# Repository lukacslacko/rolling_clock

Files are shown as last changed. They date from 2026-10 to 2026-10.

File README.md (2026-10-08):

# Rolling clock

A 3D-printed clock mechanism powered by its own slow roll down an incline. The rolling drum drives a pendulum escapement through two 72:18 gear pairs. A weighted inner frame carries the gears and stays approximately upright while the drum turns around it.

Designed by László Lukács with OpenAI Codex for a Bambu Lab P1S, using PLA, a 0.4 mm nozzle and 0.2 mm layers. Intended as a short-duration timer and mechanical demonstration.

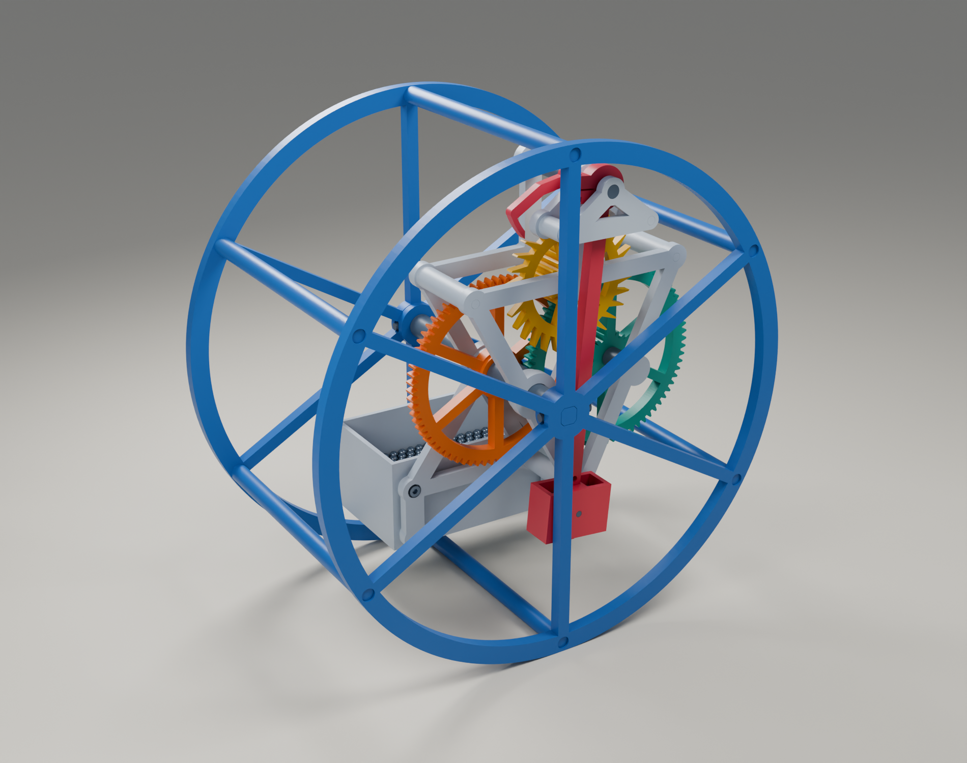
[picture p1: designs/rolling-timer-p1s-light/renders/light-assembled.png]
Assembled lightweight rolling clock


## New prototype - bolted R3

The [R3 design](designs/rolling-timer-r3/README.md) responds to the first build's physical feedback: square screw-fastened posts, a screw-fixed bob, more pendulum space, a deeper rolling rim and shared frames for 16:1, 32:1 and 64:1 gearing. It includes [a 17-page illustrated guide](designs/rolling-timer-r3/BUILD-GUIDE.pdf), a [1:1 axle identification sheet](designs/rolling-timer-r3/AXLE-1-TO-1.pdf) (also guide page 6), [per-ratio spacer and wheel-orientation drawings](designs/rolling-timer-r3/PIVOT-STACKS.pdf) (guide pages 7-9), and separate print lists. **The builder reports corrected R3 prints and rolls well.** The smoother wheel below still needs a physical trial. The first working version remains below and under tag `v0.1.0`. The 7 October pivot correction adds taller pivot feet and 6 mm of width; see the R3 reuse table before printing the remaining parts.

**R3 rear thrust correction:** add one [38_rear_journal_thrust_collar.stl](designs/rolling-timer-r3/STL/common/38_rear_journal_thrust_collar.stl). This 6 mm ring surrounds rear journal 36, between the rear frame and washer 35; it fills a gap omitted during the widening. All existing corrected print files remain unchanged. See the [R3 correction notes](designs/rolling-timer-r3/README.md#missing-rear-thrust-collar---correction) and updated guide page 6.

**Smoother R3 rim:** [wheel 01](designs/rolling-timer-r3/STL/common/01_case_wheel.stl) now has **1,536 outer segments** instead of 192 (0.507 mm flats instead of 4.058 mm). The 248 mm diameter and all mounting features are retained; the other 50 print files are unchanged. Try Bambu Studio Resolution 0.001 mm and Arc fitting on. Details and evidence are in the [R3 notes](designs/rolling-timer-r3/README.md#smoother-rolling-rim---8-october-2026).

## Current state — first working build

On **1 October 2026**, the complete lightweight **16:1** mechanism ran on its first physical trial, following a successful hand-driven bench test. This repository preserves that design before the next round of improvements. Running duration, timing accuracy and long-term wear have not yet been measured.

The reported issue is occasional contact between the pendulum bob and the interior frame or drum spokes. A separate [1 mm wall replacement bob and shorter pin](designs/rolling-timer-p1s-light/bob-1mm/README.md) provide 1.4 mm more clearance on each side while preserving the iron capacity and rod fit. This replacement has passed geometric checks but **has not yet been physically tested**. The original working STL set is retained unchanged.

## Start here

1. Use the **[lightweight 16:1 design](designs/rolling-timer-p1s-light/README.md)** and its **[print list](designs/rolling-timer-p1s-light/PRINT-LIST.md)**. The list gives quantities and orientations; optional fit coupons are included.
2. Follow the **[illustrated bench assembly guide (PDF)](designs/rolling-timer-p1s-light/bench-guide/bench-assembly-guide.pdf)** for the gear train, escapement and pendulum. A [browser version](designs/rolling-timer-p1s-light/bench-guide/index.html) is included; download the repository and open it locally.
3. Follow the **[complete assembly instructions](designs/rolling-timer-p1s-light/ASSEMBLY.md)** to add the ballast cup and rolling drum.
4. For the clearance update, replace parts 25 and 26 with **[25_open_pendulum_bob_1mm.stl](designs/rolling-timer-p1s-light/bob-1mm/25_open_pendulum_bob_1mm.stl)** and **[26_bob_pin_short.stl](designs/rolling-timer-p1s-light/bob-1mm/26_bob_pin_short.stl)**. Follow that folder's fitting instructions; the guide's pictures show the original bob.

**Rotation direction:** viewed from the pendulum/front side, the orange input and yellow escape wheel turn counterclockwise, and the green compound wheel turns clockwise. Apply only light hand torque for a bench test. Lift the drum to return it uphill instead of rolling the escapement backward.

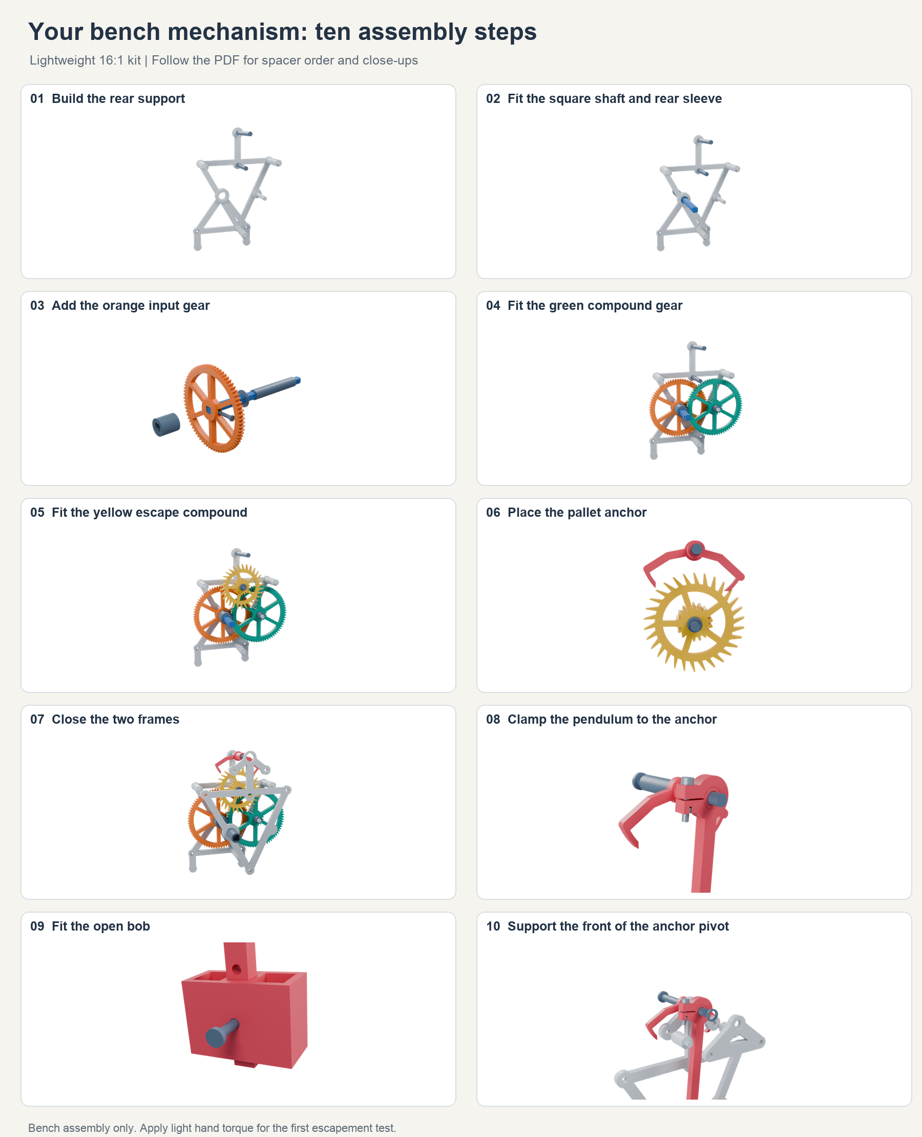
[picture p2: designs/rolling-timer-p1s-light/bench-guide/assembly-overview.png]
Ten stages of the bench assembly


## Dimensions and materials

| Item | Design |
|---|---|
| Rolling drum | 240 mm diameter × 140 mm wide |
| Printer envelope | 256 × 256 × 256 mm; every individual part fits |
| Spur gears | Module 1.25, 20° pressure angle; 72:18 × 72:18 = 16:1 |
| Escapement | 30-tooth Graham deadbeat, printed pallets and short pendulum |
| Main axle | 8 mm chamfered square shaft with separate round journal sleeves |
| Bearings | Printed plain journals; no purchased rolling bearings |
| Ballast | Start around 600 g in the open main cup and 15–20 g in the open bob |
| Hardware | Two M3 × 10 screws and nuts for the cup; one M3 × 16 screw and nut for the pendulum clamp |
| Nominal rate | About 8 minutes per metre at the intended effective pendulum length; calculated, not measured |

The two compound gears have small-pinion teeth extending through their large wheels so they print from the bed without support under the pinions. Detailed fits, print settings and first-run setup are in each design's README. STL dimensions are millimetres; print at 100% scale.

## Animation and other variants

Open **[docs/animation.html](docs/animation.html)** locally for the interactive animation: play/pause, single beats, time scrubbing, and close-ups of the escapement and gear layers. It is a self-contained HTML file with no build step or network dependency. Its older grid-frame schematic illustrates the same 16:1 gearing; the print files and assembly guide define the lightweight hardware. The animation prescribes motion and does not simulate friction, available torque or carrier rocking.

The **[modular R2 design](designs/rolling-timer-p1s-r2/README.md)** retains two grid plates with removable pivot modules for experimenting with gear ratios. Its **[32:1 development set](designs/rolling-timer-p1s-r2/upgrade-32x/README.md)** includes an extra gear and a matched reversed escape wheel and anchor. Neither this grid-frame assembly nor the 32:1 set has been physically tested. The 32:1 set is **not a drop-in upgrade for the lightweight frames**.

Perspective renders, editable Blender mesh scenes, assembled reference meshes and JSON geometry-check reports are included beside each design. Files in `source/assembly/` and `bob-1mm/assembly/` are positioned reference meshes, not print plates. Rendered loose steel and fasteners are illustrative.

## Edit and regenerate

The CAD source is Python using Manifold, Trimesh, Shapely and NumPy. Use **Python 3.11 or newer** and install the pinned dependencies in a virtual environment. From the repository root:

```sh
python3 -m venv .venv
source .venv/bin/activate
python -m pip install -r designs/rolling-timer-p1s-light/source/requirements.txt

python designs/rolling-timer-p1s-light/source/check_motion.py
python designs/rolling-timer-p1s-light/source/validate_light.py
python designs/rolling-timer-p1s-light/bob-1mm/source/build_bob.py
```

On Windows, activate with `.venv\Scripts\activate` instead. `check_motion.py` regenerates the base print files and assembled geometry before checking motion. The bob generator writes only the separate replacement folder. These commands overwrite generated files; commit edits before regenerating. The STL set has already been exported, so Python is unnecessary just to print it.

The modular version has its own generators:

```sh
python designs/rolling-timer-p1s-r2/source/check_motion.py
python designs/rolling-timer-p1s-r2/source/upgrade32.py
python designs/rolling-timer-p1s-r2/source/validate_revision.py
```

For optional renders, use Blender 5.x:

```sh
blender -b --factory-startup -t 6 --python designs/rolling-timer-p1s-light/source/render_light.py
blender -b --factory-startup -t 6 --python designs/rolling-timer-p1s-light/bench-guide/source/render_bench_guide.py
```

To rebuild the PDF and browser guide from the included rendered figures, install `reportlab` and `Pillow`, then run `python designs/rolling-timer-p1s-light/bench-guide/source/make_bench_guide.py`. The script looks for Arial, Liberation Sans or DejaVu Sans on common platforms; the checked-in PDF is ready to use.

The checks cover closed connected meshes, print envelopes, gear engagement, nominal assembly intersections, and sampled mechanism motion. They do not model print error, friction, strength or wear. Historical JSON reports describe the geometric checks when created; the physical status above records the later successful trial.

## References and license

The deadbeat pallet geometry follows the construction described by [Roman Y. Andronov](https://romanandronov.github.io/pgc/ryapgce.html); see also [Rainer Hessmer's Deadbeat Escapement Builder](https://hessmer.org/gears/DeadbeatEscapementBuilder.html). The project supplies its own CAD implementation, mounting system and print geometry.

The original source, print models, animation and documentation in this repository are released under the **[MIT License](LICENSE)**. Third-party software used to generate them retains its own licenses and is not bundled here.

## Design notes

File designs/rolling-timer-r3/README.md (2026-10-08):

# R3 - bolted frames and three gear ratios

The builder reports that the corrected R3 **prints and rolls well** (8 October 2026), after adding rear thrust collar 38. Visible flat faces on the rolling rim led to the finer-mesh wheel below, which still needs a physical print. Running accuracy, durability and every gearing option have not been established. The original build and its `v0.1.0` checkpoint remain unchanged.

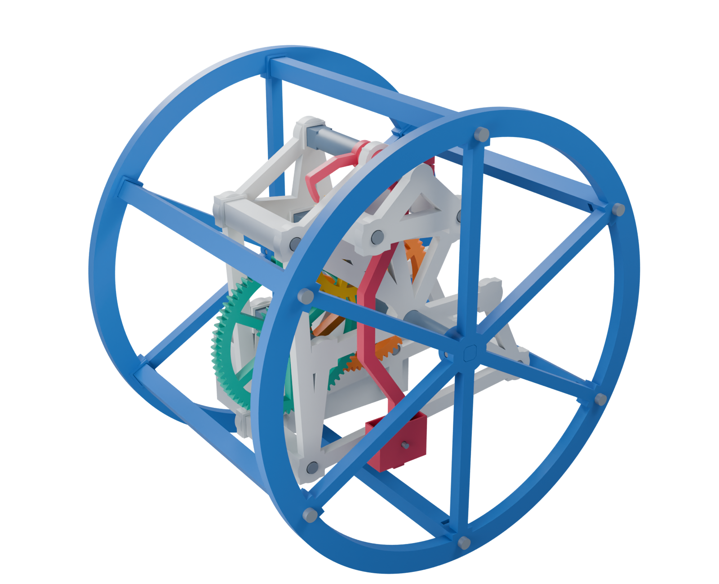
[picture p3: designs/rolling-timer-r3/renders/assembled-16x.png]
Bolted R3 assembly


## What changes

- Six square case posts and three square frame posts have flat ends, side-loading captive nuts and M3 clearance holes. Screws clamp the ends against flat seats; locating lips have **0.2 mm clearance per side**, so the posts do not spread the wheel rim.
- The bridge has two square posts, bolted at both ends. Its post locations are moved away from the pendulum clamp's swept envelope. The bridge supplies their square locating lips; their frame ends sit directly on a flat face.
- All three main-axle crosspins become **M3x16 screws and captive nuts**. The square axle still transmits torque; the screws retain it axially.
- The open bob has **1 mm outer walls**, a retained structural web, and an **M3x16 screw and captive nut** instead of a printed pin. Its screw passes through one of five 3.4 mm rod holes.
- The pendulum has its own wider front compartment and a bent rod that clears the main axle. The escapement is tilted inward by 10 degrees as a matched wheel/pallet arrangement to keep the pendulum clamp inside the rotating posts. Its working pallet profiles follow the first successful build.
- Both carrier frames support **16:1, 32:1 and 64:1**. Gear shafts are bolted to the rear frame and supported in clearance-fit blind seats in the front frame. The anchor pivot is supported by the rear frame and the bolted bridge. No bought bearings are needed.

The drum is **248 mm diameter x 186 mm between its outer plastic faces**, about **192.4 mm including the bounded screw heads**. Every individual part fits the 256 mm P1S volume. The wheel has a 13 mm radial rolling rim. The post body's furthest corner is 4.90 mm inside the rolling circle; the wider locating pads stay at least about 2.9 mm inside it. All post screws load the wheel axially.

## Smoother rolling rim - 8 October 2026

The printed rim's visible faces were present in the STL: the outside circle used **192 segments**, making each flat **4.058 mm wide** on the 248 mm wheel. The ideal chord lies up to **0.01660 mm** inside a true circle. This coarse approximation is a clear contributor to the reported faceted surface; the user's actual sliced toolpath was not inspected.

The current [01_case_wheel.stl](STL/common/01_case_wheel.stl) uses **1,536 outer segments**, each about **0.507 mm wide**, with only **0.000259 mm ideal chord error**. Only the outside rolling contour changes. The hub, axle socket, six post seats, screw holes, inner rim and spokes keep their original geometry. The other 50 print files are unchanged. Print **two copies** when replacing the drum wheels; the revised wheel still fits the existing assembly.

For this wheel, try **Bambu Studio Resolution = 0.001 mm** and **Arc fitting enabled** in Advanced settings. Resolution controls contour simplification, and arc fitting uses the same tolerance to generate G2/G3 moves; this is an engineering starting point for this rim, not a physically tested profile. The common Bambu process profile currently uses 0.012 mm resolution. See Bambu's [setting definitions](https://github.com/bambulab/BambuStudio/blob/master/src/libslic3r/PrintConfig.cpp) and [common process profile](https://github.com/bambulab/BambuStudio/blob/master/resources/profiles/BBL/process/fdm_process_common.json). Keep 0.2 mm layers: the issue is the circular contour in the XY plane. Avoid mesh simplification of the replacement STL.

## Pivot-base correction - 7 October 2026

The original 4.5 mm pivot foot was too short: its nut channel reached 1.2 mm into the 8 mm journal, leaving a weak connection. Both pivot types now have **10.5 mm square feet**, **4.8 mm of material above the nut channel**, and a blind screw bore that stops **3.7 mm below the shaft root**. The 8 mm shaft is solid from its root upward. Print pivots 13 and 19 with **100% infill**, foot down. Nut fit remains 5.6 mm with a 5.8 mm entry.

The gear train, front frame, bridge and pendulum move forward together by 6 mm. Gear engagement, all gear spacers, pendulum clearance and screw lengths stay the same. At its closest axial position, the B gear is 6.4 mm ahead of its pivot nut.

**Already printed R3 gears, anchor, rear frame, anchor bridge and both bridge posts can be reused. Reprint only the three frame posts from the builder's reported printed set.** Both frame shapes are unchanged; their spacing increases from 48 to 54 mm. Six print files change in total:

| File in `STL/common/` | Qty, 32x core | Qty, complete 32x | Revised dimension |
|---|---:|---:|---|
| [07_square_frame_post.stl](STL/common/07_square_frame_post.stl) | 3 | 3 | 54 mm long |
| [13_bolted_gear_pivot.stl](STL/common/13_bolted_gear_pivot.stl) | 3 | 3 | 10.5 mm foot; 56.5 mm total |
| [19_bolted_anchor_pivot.stl](STL/common/19_bolted_anchor_pivot.stl) | 1 | 1 | 10.5 mm foot; 89.5 mm total |
| [03_square_main_axle.stl](STL/common/03_square_main_axle.stl) | 1 | 1 | 186 mm; cross-holes at 6, 97, 180 mm |
| [36_rear_round_journal.stl](STL/common/36_rear_round_journal.stl) | 1 | 1 | 76 mm long |
| [02_square_case_post.stl](STL/common/02_square_case_post.stl) | 0 | 6 | 172 mm long |

For 16x, use two copies of pivot 13; the other quantities are the same. The 64x quantities match 32x. Use all six corrected file types when completing the drum; all other R3 print shapes remain compatible.

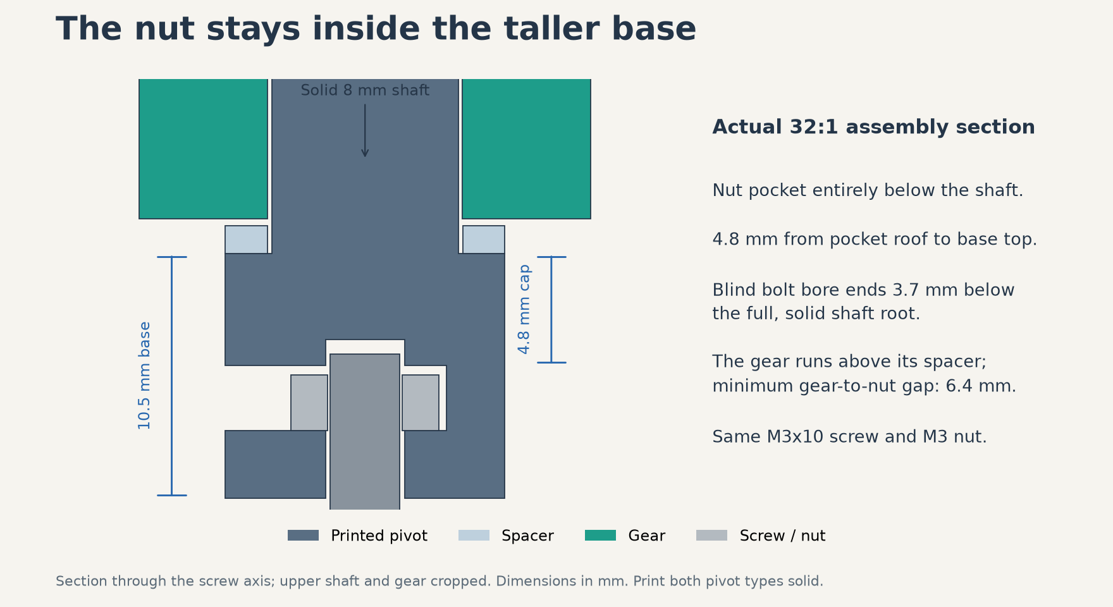
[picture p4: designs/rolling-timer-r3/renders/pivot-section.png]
Section through corrected gear pivot


## Missing rear thrust collar - correction

The 6 mm widening advanced the orange gear, washer 35 and the end of journal 36, but left the rear frame's bearing collar in place. A ring around the journal was omitted. This left a **6.4 mm gap between the rear-frame collar and washer 35**, allowing excessive rearward movement of the main axle relative to the carrier. This was a design error, not a missing assembly step or a part already present in the earlier kit.

**Print one [38_rear_journal_thrust_collar.stl](STL/common/38_rear_journal_thrust_collar.stl), for any of the three ratios.** It is **6 mm long, 16 mm outside diameter, with a 12.4 mm round bore**. Print flat on either annular face, without supports. Slide it **around journal 36**, in front of the rear-frame bearing collar and behind washer 35. Washer 35 still goes onto the square axle, against the end of the journal. The nominal frame-to-collar clearance is 0.4 mm.

Rear-to-front thrust path: **rear-frame collar 05 → new collar 38 → washer 35 → fixed orange gear 10**. Journal 36 runs inside collar 38. **The collar correction left all 50 previously supplied STL files byte-for-byte unchanged.** The later rolling-rim refinement above changes only wheel 01. The collar is included in all print lists, kits, the assembly meshes and the updated guide's page 6. No additional screw or nut is needed.

The geometry checks now derive the actual axle stops from the thrust stacks and allow the loose sleeves to slide independently. With collar 38, the nominal rigid axle limits are **-0.8 to +0.8 mm** relative to the carrier; the previous check incorrectly assumed only -0.4 to +0.4 mm without checking that those stops existed. All three configurations pass the revised interference checks. The builder subsequently reported that collar 38 printed well and the clock rolled well.

## Files and printing

Start with [BUILD-GUIDE.pdf](BUILD-GUIDE.pdf), then use the exact quantities in [PRINT-LIST-16x.md](PRINT-LIST-16x.md). The other configurations have [32x](PRINT-LIST-32x.md) and [64x](PRINT-LIST-64x.md) lists. Do not print every file in every folder.

**Axle orientation, updated 8 October:** page 6 of the 17-page guide is a **1:1 side view of the assembled main axle**, with a second outline of the bare axle and all three holes. It is also available as a one-page [AXLE-1-TO-1.pdf](AXLE-1-TO-1.pdf). Print A4 landscape at **100% / Actual size**, disable Fit / Shrink, and verify the **50 mm calibration bar**. The drawing uses the actual corrected assembly meshes and is shared by all three ratios.

**Spacer and wheel orientation drawings:** guide pages **7, 8 and 9** cover **16:1, 32:1 and 64:1**, respectively. The same three pages are available separately as [PIVOT-STACKS.pdf](PIVOT-STACKS.pdf). Each shows the active pivot map, rear-to-front order, part numbers, spacer lengths, tooth counts and the direction of the pinions. The anchor row shows its sleeve passing through the front frame, the pendulum clamp, and the 7.7 mm front spacer before the bridge. These side diagrams use CAD axial positions with compressed diameters for readability; they are **not 1:1 templates**.

The middle hole is **97 mm from the rear end** (main ballast bowl side), and **89 mm from the front end** (pendulum side). The orange wheel's **flat face points rearward**, toward the **76 mm journal 36**; its **raised hub points forward**, toward sleeve 34 and the pendulum. Its M3x16 screw goes through the middle hole. Rear-to-front order on the axle: **36 → 35 → 10 → 34 → 37**, with **38 around the front end of 36**, between the rear frame and washer 35. The drawing preserves the intended small gaps; it is not an exploded view.

- `STL/common/`: shared case, frames, fastener posts, pivots, input gear, pendulum and bob.
- `STL/16x/`, `STL/32x/`, `STL/64x/`: the selected gear train and its spacers.
- `STL/slow-common/`: the reversed anchor shared by 32x and 64x.
- `STL/fit-tests/`: nut-post and locating-seat coupons.
- `assembly/`: positioned reference meshes, **not print files**.
- `source/`: editable Python CAD, geometric checks, render and guide generators.
- `layouts.json`: actual R3 shaft positions and per-ratio quantities. `escapement-reference.json` preserves the earlier tooth/pallet/contact-cycle data; its legacy layout centres are not the R3 frame layout.
- `renders/` and `r3-assembly.blend`: views of the actual mesh assemblies.

Use PLA, a 0.4 mm nozzle, 0.2 mm layers, and 100% scale. Small functional parts: 5-6 walls and solid or nearly solid sections. Larger frames and wheels: about 4-5 walls, 5 top/bottom layers and 25-35% infill as a starting point. The exported orientations put posts on a long flat side with their nut slots upward, gears on their broad faces, cups mouth-up, and journal sleeves upright. Keep gear teeth, journals and pallets free of support material. Preview the small transverse screw-hole bridges and nut recesses in the slicer.

The 248 mm wheel leaves only 4 mm on each side of a nominal 256 mm bed: **no outside brim**. Check your actual printer profile's exclusions and auxiliary structures. Tall journal sleeves and pivots can use a small brim.

### Fit coupons first

The final anti-rotation seats are **5.6 mm** wide throughout, selected by the builder after printing and trying the fit coupons. The side-loading insertion channels are **5.8 mm** wide, with a 2 mm taper into the seat, including the bob, square posts, pivot feet and axle-retaining hubs. Direct-entry hex pockets in the pendulum clamp and ballast bowl use the same 5.6 mm seats with a short 5.8 mm flared mouth. `NUT_WIDTH` and `NUT_ENTRY_WIDTH` in `source/build.py` control these dimensions independently.

To confirm the fit on another printer or with different nuts, print `40_nut_post_coupon_560.stl` and `41_post_seat_coupon.stl` in their supplied orientations, and try an actual nut and M3x10 screw. The nut should slide freely along the entry, then sit with its thread on the screw axis without rotating when tightened. The two flat faces must close without the locating lips spreading. The original 5.25 and 5.40 mm comparison coupons are retained at their labelled dimensions, all with the same 5.8 mm entry. If another seat width suits your nuts and printer, change `NUT_WIDTH` and regenerate; do not scale complete gear or frame files.

The hardware models use nominal 5.5 mm-across-flats nuts, leaving 0.1 mm total clearance across the production seat. The physical coupon test determined the printed fit, and the corrected R3 has now been reported running. Tighten plastic joints only until seated; use the nut, not a self-tapped plastic thread.

## Hardware

| Configuration | M3x10 screws | M3x16 screws | Plain M3 nuts |
|---|---:|---:|---:|
| 16:1 | 15 | 17 | 32 |
| 32:1 | 16 | 17 | 33 |
| 64:1 | 16 | 17 | 33 |

These counts are within two dozen of each screw length and exclude optional fit-test hardware. Use plain nuts approximately 2.4 mm thick and screw heads no larger than 6.5 mm diameter x 3.2 mm high, with flat undersides. Screw length is measured under the head. No metal washers, threaded inserts or purchased bearings are required.

The gear pivot feet use one rear screw each; their front tips are located in blind seats, without clamping the rotating gear. The three main frame posts set the 54 mm face-to-face spacing. Spare bearing positions remain empty.

## Choosing a ratio

| Configuration | Gear pairs | Extra shaft | Anchor |
|---|---|---|---|
| 16:1 | 72:18 x 72:18 | None; B uses B16 position | Forward |
| 32:1 | 72:18 x 72:18 x 60:30 | Bslow and D positions | Reversed |
| 64:1 | 72:18 x 72:18 x 72:18 | Same Bslow and D positions | Same reversed anchor |

Both final pairs for the slower options have **90 teeth in total**, giving the same **56.25 mm centre distance**. To change 32x to 64x, swap only the D compound and the escape compound; all shafts, spacers, anchor and frames remain in place. Changing 16x to a slower option also relocates B, adds D and its spacers, and replaces the anchor and C rear spacer. Use the complete selected print list. Do not mix older revision parts into R3.

From the pendulum/front side, drive the orange input **counterclockwise**. The escape wheel turns counterclockwise in 16x and clockwise in 32x/64x. The extra external mesh requires the reversed anchor and escape wheel together.

At the original nominal pendulum period, one metre takes approximately **7 min 42 s / 15 min 25 s / 30 min 50 s** for 16x/32x/64x. These are calculated values, not measurements. The larger wheel, revised pendulum shape and metal bob fastener require calibration. The slower options reduce the ideal torque at the escapement by factors of two and four relative to 16x, so successful running on the same incline is not guaranteed.

## First trial

Begin with 16x. Bench-test with light hand torque before fitting the drum. Set the bob initially at the **150 mm hole** (fourth from the pivot), with about **15-20 g total iron**. Adjust the clamp angle for equal release on each half-swing, then snug its M3x16 screw. Leave the bearing stack free to turn with its designed endplay.

Start the rolling test with about **600 g** in the main bowl. The previous clock ran well with a 4 cm rise over an 80 cm board and also ran at 3 cm; at 2 cm it needed careful beat adjustment. Those correspond to approximately **2.9, 2.1 and 1.4 degrees**. Use the successful 4 cm setup as a starting point for R3, then reduce the slope once it runs steadily. Mark distance against a stopwatch rather than assuming the calculated rate. Lift the drum to reset it uphill.

A little periodic rocking can result from the pendulum exchanging angular momentum with the carrier and drum. The bolted joints address looseness; they are not intended to eliminate that coupled motion. Watch for missed or multiple releases, rubbing and changing beat rather than judging solely by the appearance of the rocking.

## What was checked

The three assembled configurations include worst-case screw-head envelopes and real nut envelopes. Checks cover each exported mesh, actual involute engagement, both escapement directions, nominal assembly interference, the full gear and carrier axial endplay, a 61-position pendulum sweep from -15 to +15 degrees, and 73 drum positions through a full rotation. Analytic radial bounds also cover every drum angle within the checked pendulum range. The pivot correction adds cross-section area checks through both feet, verifies a substantial cap above each nut pocket, and checks that the full 8 mm shaft is solid. These geometric checks are not a strength or fatigue simulation.

Nominal axial gaps: **9.4 mm bob to front frame**, **6.2 mm bob-screw head to frame**, and **15.6 mm screw tip to front wheel spokes**. Overall clearance to the rotating case posts is at least **2.35 mm** within the checked range. The screw/nut stacks have full nominal nut engagement, with at least 0.4 mm of screw extending beyond the nut. Gear axial endplay is 0.6 mm; blind pivot seats leave 0.5 mm end clearance. At the full combined axle and gear endplay limits, the input hub clears the large B wheel by **0.1 mm nominally**. The builder's successful roll is encouraging, but that small extreme-position clearance has not been measured physically.

These checks do not simulate friction, extrusion errors, elastic deflection, creep, torque losses or running accuracy. The successful R3 report does not establish every gear ratio or the new smoother rim. `checks-16x.json`, `checks-32x.json` and `checks-64x.json` contain the detailed results, including the measured exported rim segmentation; [OBSERVATIONS.md](OBSERVATIONS.md) preserves the builder's feedback.

## Regenerate

With Python 3.11+ and `source/requirements.txt` installed:

```sh
python source/validate.py
```

This regenerates all R3 meshes and runs the checks. It does not modify earlier designs. Generate the dimensioned pivot section with `python source/pivot_section.py` (requires Matplotlib). For illustrations, run `blender -b --factory-startup -t 6 --python source/render.py`. After any CAD change, run `python source/axle_reference.py` to project the actual assembled axle meshes and verify that they match across all ratios, then `python source/pivot_reference.py` to project the pivot stacks and verify their spacer lengths and gaps. Rebuild the guide, standalone 1:1 axle sheet, three-page pivot reference and print lists with `python source/make_guide.py` using ReportLab and Pillow. Create the complete archive and selected print kits with `python source/package.py --output /path/to/output-folder`. The checked-in outputs are ready to use without these tools.

Released under the [MIT License](LICENSE), as part of [lukacslacko/rolling_clock](https://github.com/lukacslacko/rolling_clock).

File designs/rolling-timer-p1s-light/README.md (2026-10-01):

# Lightweight 16:1 rolling timer

This is a dedicated first-print alternative to the revision-2 grid frames. It retains the same gear train, escapement, square shaft, round journal sleeves, pendulum, open ballast capacity and 240 mm drum. Only three existing print files change: rear carrier 05, front carrier 06 and bowl 08.

## What changed

- The two grid discs become small triangular frames with only the required bearing bosses, pendulum supports and bowl bracket.
- The B pivot is integrated into rear frame 05; its blind front bearing is integrated into frame 06. Parts 31, 32 and all six pins 33 are omitted.
- Three original-size carrier posts 07 join the frames, at new positions. Print only three, not four. The six long drum posts 02 remain unchanged.
- The bowl uses two upper M3 x10 screws and plain M3 nuts. Head recesses shorten the clamped plastic stack; hex pockets inside the bowl locate the nuts. Two lower contact pads resist rocking without lower fasteners. Omit the four original pins 09.

The pair of frames has **49.8 cm3** CAD solid volume versus **145.2 cm3** for the old grid plates: **65.7% less**, even including the integrated B supports. There are 39 printed assembly instances rather than 52. Slicer time and filament savings depend on settings; these are geometry-volume figures, not a sliced-time prediction.

## Files to use

- `STL/05_rear_carrier.stl`, `STL/06_front_carrier.stl`, `STL/08_open_ballast_bucket.stl`: the three replacement parts.
- `STL/`: complete compatible 16:1 print set, including unchanged R2 pieces and fit tests.
- `PRINT-LIST.md`: quantities and print orientations.
- `bob-1mm/`: optional 2026-10-01 replacement bob with 1 mm outer walls and a matching shorter pin, preserving the rod fit and iron capacity. Use its own instructions; the original `STL/` files remain preserved.
- `ASSEMBLY.md`: revised complete assembly order.
- `bowl-bolt-section.png` and `.svg`: the M3 x10 mounting stack.
- `renders/`: perspective views of the new assembly and frame pair.
- `light-assembly.blend`: editable rendered assembly; its floor, loose ballast and fastener envelopes are not print parts.
- `source/`: generators and checks. `light-layout.json` records the axes, post locations and fastener dimensions.

The old R2 package is preserved separately. This light frame has no interchangeable mounting grid and is intended for the first 16:1 build. Use the original grid-frame version for the supplied 32:1 upgrade.

## The two M3 x10 bowl screws

The screw heads sit on the mechanism side of the rear frame. Their 7 mm diameter recesses are 2.5 mm deep. Use cap, button or pan heads with flat undersides, head diameter no more than 6.5 mm and head height no more than 3.2 mm. Screw length is measured under the head.

From the head seat to the nut face, the plastic stack is 2.5 mm of rear frame + 2 mm bowl boss + 2.4 mm bowl wall = **6.9 mm**. A plain **2.4 mm-thick M3 nut** leaves **0.7 mm** of the 10 mm screw beyond the nut. No washer is needed in the intended stack. The nut pockets are 5.7 mm across flats and 3 mm deep, sized around a plain M3 nut with 5.5 mm flats. The nut dimensions follow [Accu's M3 plain-nut specification](https://www.accu.co.uk/hexagon-nuts/766459-NUT203M3); use your existing matching nuts.

Seat both nuts and fit both screws before filling the bowl. Tighten gently until the upper bosses and lower pads contact the rear frame. The nuts can be held with a fingertip inside the open cup while starting the screws. Begin with about 600 g of ballast as before.

## Printing

PLA, 0.4 mm nozzle and 0.2 mm layers remain the design assumptions. Both frames print with their outside faces on the bed. The rear frame's integral B pivot points upward; the front frame's bearing bosses and blind seat point upward. Use 5-6 walls and 5 top/bottom layers; 25-35% infill is a reasonable initial choice for the frame webs. The integral pivot should be solid. These settings are starting choices, not a printer-specific strength validation.

Rear frame envelope: **128.3 x 188.9 x 41 mm**. Front frame: **120 x 163.9 x 9 mm**. Bowl: **110 x 60 x 46 mm**, exported open-mouth-up. All fit the P1S. Keep general supports off the frames. Inspect the small horizontal nut-pocket roofs and screw holes in the bowl's slicer preview; clean up any loose bridge strands before fitting the nuts.

The saved meshes are closed, connected solids. Nominal assembly, both spur meshes, escapement motion, the pendulum range and a full rotation of the keyed shaft were checked, including the bowl fastener envelopes. The unchanged printed files are byte-identical to R2. On 2026-10-01, the user reported the complete mechanism running on its first trial, with occasional pendulum-bob contact against the carrier or case spokes. The narrower replacement in `bob-1mm/` addresses that contact; it has been checked geometrically but has not yet been physically tested. Long-term wear and running accuracy remain unmeasured.

## Regenerating

With the dependencies in `source/requirements.txt`, run `python source/check_motion.py`, then `python source/validate_light.py`. The first command regenerates the print meshes and assembled geometry. For images, use Blender: `blender -b --factory-startup -t 6 --python source/render_light.py`.

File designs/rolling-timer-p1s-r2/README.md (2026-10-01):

# Rolling timer - P1S prototype, revision 2

A 240 mm rolling drum containing a weighted carrier, a 16:1 gear train and a short pendulum with a Graham deadbeat escapement. Every printable part fits the 256 mm P1S volume. The ballast bucket and pendulum bob are open; neither has a lid. All rotating pivots are printed plain bearings. This revision adds pinion teeth through both compound wheels and an 8 mm chamfered square main shaft, with separate round journal sleeves in the unchanged carrier plates.

**This modular grid-frame variant has checked CAD geometry but has not been physically tested. The lightweight sibling uses the same 16:1 gears and was reported running on 2026-10-01.** Start with the fit coupon and the 16:1 mechanism. The animation prescribes pendulum motion; it does not establish that friction, losses or carrier rocking will permit sustained running.

## Files and first prints

- `STL/`: the initial **16:1** build, individually oriented on the bed. Print quantities are in `PRINT-LIST.md` and `parts.json`. Do not import every file as one assembled model.
- `ASSEMBLY.md`: assembly order, fit adjustment and first running trial.
- `mounting-layout.png`: dimensioned axis and mounting-hole layout.
- `renders/`: perspective studio views of the assembly and revised components. See its README for the parts omitted in the open inspection view.
- `REVISION-2.md`: changes, compatibility, fit and assembly differences.
- `perspective-assembly.blend`: editable assembled mesh scene with perspective camera and studio lighting. Numerical dimensions are millimetres. It is not a parametric solid model or a print plate.
- `source/`: editable Python geometry and CAD generators.
- `upgrade-32x/`: a separate, optional development set. **Do not mix these parts into the first build.**

Print parts 27-30 and 38-39 first. Parts 38-39 test the new square drive fit: the notched coupon has 8.20, 8.30 and 8.40 mm sockets from left to right with the notch at lower-left. Production sockets are 8.30 mm across flats. The key should slide by hand with little angular play. The original parts 27-30 comprise a hole coupon and matching 4, 6 and 12 mm test pins. The coupon has a notched corner. With that corner at the lower-left in a top view, the row nearest it is Ø6.2, 6.3, 6.4, 6.5 left to right, followed by Ø4.0, 4.1, 4.2. The farther row is Ø12.2, 12.3, 12.4. The coupon illustration shows the exact orientation.

## Main dimensions

| Feature | Dimension |
|---|---:|
| Complete drum | Ø240 × 140 mm |
| Reusable carrier plates | Ø216 mm; 5 mm plate + 4 mm main bearing collar |
| Mounting lattice | 20 mm positions on 40 mm rails; Ø4.1 holes |
| Printed main shaft | 8 x 8 x 140 mm; 1.4 mm corner chamfers |
| Main round journal sleeves | OD12; lengths 66.6 and 23.6 mm |
| Square drive sockets | 8.30 mm across flats; matching corner relief |
| B, C and anchor pivot journals | Ø6 mm |
| Gear / anchor running bores | Ø6.35 mm |
| Main running bores | Ø12.4 mm |
| Module and pressure angle | 1.25 mm, 20° |
| Both gear pairs | 72:18; 56.25 mm centre distance |
| 72-tooth gear pitch / tip diameter | 90 / 92.5 mm |
| 18-tooth pinion pitch / tip diameter | 22.5 / 25 mm |
| Escape wheel | 30 teeth; Ø68 mm tip circle |
| Escape wheel–anchor spacing | 48.08326 mm |
| Lock / lift / drop | 1.5° / 4.5° / 2° |
| Pendulum bob settings | 135, 140, 145, 150, 155 mm from pivot |
| Nominal effective pendulum length | Approximately 140 mm; calibrate after filling |
| Ballast bucket, external | 110 × 58 × 46 mm, plus 2 mm mounting bosses |
| Ballast internal volume | Approximately 244 cm³ |

The larger ballast bucket is behind the gear train. The pendulum and its much smaller open bob are in front, so their front-view outlines can overlap. Start with about **600 g of balls in the ballast bucket and 15–20 g in the bob**; your 750 g supply leaves adjustment material. Loosely packed screws have a different bulk density, so use the actual filled mass. Leave space below the rim.

## Reusing the plates for different gearing

Both carrier plates have the same mounting lattice. The B gear in the first build already uses a **removable rear pivot module and matching front bearing module** (31 and 32), located by three printed pins each. These are small parts: changing a shaft position means changing its modules, gears and spacers while retaining the plates. New shafts can have integral pivots or blind bearing seats on the inner faces; they do not require new holes drilled through plate rails. Carrier posts also fit unused lattice holes if a later layout needs them moved.

The complete list of usable grid positions is `mounting-grid.json`; the central bearing and existing C/P mounting areas exclude some positions. The main rolling axis stays fixed. The supplied escapement stays at C/P for the two included layouts. Other arbitrary layouts still require clearance and strength checks; the grid cannot make every gear combination fit.

As a concrete extension, `upgrade-32x/` uses **72:18 × 72:18 × 36:18 = 32:1**. It retains both plates, drum, main shaft, C/P pivots, front B module, bucket and pendulum. A replacement rear module adds an Ø8 mm cantilever pivot for the extra compound gear. A recessed retaining collar keeps that shaft clear of the escape wheel. Adding one external mesh reverses the output, so the upgrade includes **both a mirrored escape wheel and a mirrored pallet anchor**, with matching axial spacers. This layout has been checked for static interference and spur engagement, but is a development set to try after the 16:1 version works.

## Printing

Use PLA, a 0.4 mm nozzle and 0.2 mm layers at 100% scale. The exports already have their intended printing faces on Z=0. Do not resize the gears to change a fit: that also changes their pitch.

- Gears, anchor, pivots, pins and pivot modules: 4–6 walls; solid or near-solid small sections. Put the seam away from journal surfaces and pallet contacts. Use a moderate outer-wall speed, about 30–40 mm/s as a starting point.
- Carrier plates and wheels: 4 walls, 5 top/bottom layers, around 20–30% infill. Keep both wheel rims flat and equal in diameter.
- Main shaft: lie on the long flat as exported, with solid infill and 4-6 walls. Its 45-degree corner chamfers start from a 5.2 mm-wide bed face.
- Tall posts and round journal sleeves: upright with a 5-6 mm brim, 6 walls or solid where space allows. Journal sleeves have about 1.07 mm minimum wall at the socket corners; preview the toolpaths there.
- Both compound gears: broad wheel face on the bed. Their small pinion teeth now continue down to the bed rather than starting partway up the print.
- Buckets: print open mouth upward as exported; their 2.4 mm walls are intended to print solid. Ordinary bridging is needed over the small horizontal pin holes.
- The 240 mm wheels fit individually with 8 mm nominal margins on a 256 mm plate. Avoid adding a large outside brim or purge structure that extends beyond the usable bed.
- General supports should be off. Inspect the slicer preview around transverse holes and the pendulum clamp's nut pocket; use local support only there if your profile needs it. Keep support material off the gear teeth and pallet contact edges.

Remove elephant foot and burrs from gears and bearing entrances. A running journal should turn freely under a small load; a locating pin should stay put without being hammered in. The starting PLA running allowance is 0.35–0.4 mm on diameter. It is an allowance to test, not a claim about your printer's exact output. This is consistent with the practical range discussed by [MatterHackers in its assembly-design notes](https://www.matterhackers.com/articles/matterhackers-lab:-design-assemblies-).

The only recommended metal fastener in the initial build is **one M3×16 screw and one M3 nut for the pendulum beat clamp**. A sufficiently snug printed clamp can be tried first, but it must not slip relative to the anchor. All other joints use printed pins. Calibrate the new square socket by changing KEY_CLEARANCE in source/build.py after printing coupon 38 and key 39. Calibrate other tight stationary fits by changing only the pins' XY dimensions or the relevant source allowance; do not scale their lengths or complete gear parts.

## Timing and operation

At an effective length of 140 mm, the ideal pendulum period is 0.75060 s. The escape wheel advances one tooth per full oscillation, giving 480 oscillations per drum turn at 16:1. One beat advances the drum about 0.7854 mm.

| Nominal result | 16:1 first build | 32:1 development set |
|---|---:|---:|
| One drum revolution | 6 min 00 s | 12 min 01 s |
| Travel in five minutes | 628 mm | 314 mm |
| Time for one metre | 7 min 58 s | 15 min 56 s |

These are kinematic values, not measured accuracy. The rod, bob, anchor mass and fill distribution determine the actual effective length; the moving weighted carrier also affects the rate. Set the bob initially at 150 mm and calibrate travel against a stopwatch. Moving the bob down slows the timer. For a practical egg-timer demonstration, marking a measured five-minute travel distance is easier than achieving an exact calculated pendulum length.

Use a straight board around 1 m long and at least 170 mm wide, with a soft end stop. Start at 1–2° (approximately 17–35 mm rise per metre), then increase only enough to sustain ticking. The animation's 6° is an illustration, not a required setting. Aim initially for about ±5° pendulum swing. Reset by **lifting and carrying the drum uphill**; forcing it to roll backward drives the escapement backward.

## What was checked

- Every initial-build STL is a closed, single-body mesh and fits the stated build volume.
- The revised compound pinion cross-sections have full support from the broad wheel face in the supplied print orientation.
- The complete keyed input rotor checked at 73 positions over a full revolution; both carrier plates are byte-identical to revision 1.
- Both spur meshes over 121 input positions and the complete pallet outline over 241 pendulum positions.
- The initial assembly for unintended intersections, plus 41 mechanism poses and 41 pendulum positions from −25° to +15° relative to the carrier.
- Approximately 3 mm clearance between the carrier envelope and the swept inside surface of the rotating drum posts.
- The 32:1 alternative's additional gear meshes and complete nominal assembly, allowing only its explicitly intended collar press fit.

Reports are included as JSON. These reports record geometric checks, not physical tests of this modular variant. See the repository README for the lightweight build's running report. Print the fit coupon, then bench-test the mechanism while supporting the carrier vertically before committing to the two large drum wheels.

## Editing and regenerating

Use Python 3.11+ and install `manifold3d==3.5.4`, `trimesh==5.1.0`, `shapely==2.1.2` and NumPy. From `source/`, run:

```sh
python geometry.py
python check_motion.py
python upgrade32.py
python validate_revision.py
```

`check_motion.py` rebuilds the 16:1 CAD; `upgrade32.py` rebuilds it and then the optional set. Generated STL and assembly files are overwritten. `build.py` defines the plates, modules, clearances and axial stack. `geometry.py` generates the deadbeat contact geometry and animation samples. Change related dimensions together and rerun the checks; they intentionally fail if a revised layout interferes.

## Geometry references

The pallet construction follows the geometric method described by [Roman Y. Andronov](https://romanandronov.github.io/pgc/ryapgce.html), also implemented in [Rainer Hessmer’s Deadbeat Escapement Builder](https://hessmer.org/gears/DeadbeatEscapementBuilder.html). The supplied CAD, mounting system, tooth relief and size choices are this prototype’s design.

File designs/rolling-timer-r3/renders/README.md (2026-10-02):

# R3 CAD illustrations

These are perspective renders of the generated assembly meshes. Blue: case and square axle; orange: input gear; green: B compound; purple: D compound; gold: escape wheel; red: anchor, pendulum and bob; pale gray: fixed frame and cup; dark gray: printed journals and spacers; steel: screws and nuts.

`assembled-16x.png` shows the complete 16x plastic and fastener assembly. `mechanism-16x.png`, `mechanism-32x.png` and `mechanism-64x.png` omit the rolling case to expose the mechanism. Other images omit selected pieces or spread fasteners apart to show assembly access; follow the PDF for the seated positions and stack order.

Screws are unthreaded clearance envelopes, with simplified heads; drive recesses are not depicted. Nuts are nominal M3 envelopes with an unthreaded bore. No rendered metal part is an STL to print. The loose iron fill is omitted.

`render-metadata.json` supplies label locations for the PDF. The corresponding `source/render.py` regenerates all views from `assembly/` with Blender 5.x. `r3-assembly.blend` in the parent folder contains all three configurations; only 16x is visible initially.

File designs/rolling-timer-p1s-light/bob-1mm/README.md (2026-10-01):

# Pendulum bob with 1 mm walls

Replacement for the bob that occasionally touches the carrier or front drum spokes. The original print set is preserved; use the two STL files in this folder for this revision.

Print one each:

- `25_open_pendulum_bob_1mm.stl`
- `26_bob_pin_short.stl`

The four outer vertical cup walls are now **1.0 mm**, reduced from 2.4 mm by moving the exterior faces inward. The printed envelope is **31.2 x 13.2 x 24 mm**, previously 34 x 16 x 24 mm. This gives **1.4 mm more clearance on each face**, including both faces toward the frame and drum spokes. The iron pocket dimensions and capacity are unchanged. The 2.4 mm floor and central structural web remain to carry the iron and pin loads.

The rod slot, 3.1 mm pin hole and 150 mm starting position are unchanged. The new pin has the same head and 2.9 mm shank diameter, but its shank is **13.2 mm** instead of 16 mm. Overall length is **14.8 mm** instead of 17.6 mm.

## Printing and fitting

1. Print the holder at 100% scale, open mouth upward as exported, using your PLA and 0.2 mm layers. Check that the slicer retains the continuous 1 mm walls. No added supports are intended. Print the pin on its head as exported.
2. Empty the old holder, remove its pin and slide it off the pendulum rod.
3. Slide on the replacement with the pockets facing upward. Use the same rod hole as your successful test (150 mm was the starting recommendation).
4. Insert the short pin from behind, with its head facing the interior frame. It should seat gently, with its plain end approximately flush with the front of the holder. Do not leave the longer pin protruding: it can consume the clearance gained by this change.
5. Refill with the same iron amount, then turn the case through a complete revolution while gently swinging the pendulum to check actual clearance. The lower plastic mass may slightly change the rate; recheck travel against elapsed time after the swap.

Instead of printing the new pin, you can shorten the **plain end** of your existing pin by **2.8 mm**, giving a 13.2 mm shank measured from under its head, and remove the cutting burr. Preserve the head.

## Checks

Both exported STLs are watertight, single connected solids and fit the P1S. The replacement was checked through 81 pendulum poses from -25 to +15 degrees against the fixed assembly and pendulum rod. Axial and radial bounds cover every drum rotation within that range. No nominal CAD intersections were found.

Nominal gaps are 3.4 mm between holder and front carrier, 1.8 mm between the seated pin head and front carrier, and 2.4 mm between holder/pin tip and front drum spokes. These figures do not include print error, frame flex or axial play. The user has reported the original complete mechanism running; this replacement has not yet been physically tested.

`checks.json` records the geometry checks. `source/build_bob.py` regenerates only this replacement folder, using the original assembly as a reference. `assembly/` contains development meshes in assembled positions, not files to print.

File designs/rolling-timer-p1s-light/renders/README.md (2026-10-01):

# Lightweight 16:1 variant - perspective views

All views use the supplied printable meshes. The steel screw/nut envelopes omit threads; loose steel ballast and the studio floor are illustrative.

- light-assembled.png: the complete rolling timer.
- light-mechanism.png: front drum wheel and its shaft crosspin removed; both lightweight carrier frames remain fitted.
- light-rear.png: complete assembly, empty ballast cup so its upper mounting region can be inspected.
- lightweight-frames.png: the new rear and front frames lying on their intended printing faces. Rear frame has the integral B pivot and bowl bracket; front has the blind B bearing and pendulum bridge supports.

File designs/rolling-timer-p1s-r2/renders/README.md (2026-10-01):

# Revision 2 perspective renders

All views use a perspective camera and the exact supplied R2 print geometry.

- `perspective-front.png`: complete assembly, front three-quarter view.
- `perspective-rear.png`: complete assembly from the ballast side.
- `perspective-open.png`: front wheel, front carrier, B front module and anchor bridge removed for inspection, with their associated retaining hardware. These supports are required in the actual build.
- `compound-gears-on-print-faces.png`: green and yellow gears resting on their exported printing faces. Small pinion teeth now continue through the large-wheel thickness.
- `square-drive-components.png`: square shaft, orange input gear, two round bearing sleeves and keyed thrust parts, arranged separately on the studio floor.

The studio floor and loose steel spheres are illustrative. No printed part geometry was altered for rendering. Colors identify the same functional groups as the previous guide. The old visual guide belongs to revision 1; follow this revision's ASSEMBLY.md for the square axle and its additional sleeves.

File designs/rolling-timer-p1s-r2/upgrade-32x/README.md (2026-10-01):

# Optional 32:1 development set - revision 2

Build the initial 16:1 mechanism first. This optional set keeps both carrier plates, the revised square drive and its round sleeves, drum, ballast and pendulum. Read the parent ASSEMBLY.md section "Trying 32:1 later" and layout-and-checks.json before printing.

U02-U04 now have pinion teeth extending through the large-wheel thickness, as in the revised base gears. The D compound still has its recessed collar seat; inspect that small annular overhang in the slicer. Use the reversed escape wheel and reversed anchor together. All upgrade print quantities and orientations are in parts.json. The geometry is not physically tested.

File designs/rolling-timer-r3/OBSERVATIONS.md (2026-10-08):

# Physical observations motivating R3

Recorded from the builder on 2 October 2026, after the original lightweight 16:1 clock ran successfully.

1. Press-fit case posts expanded their wheel holes and produced six bumps in the rolling rim, sometimes stopping the roll. Frame and pendulum-bridge joints loosened or failed to maintain an exact distance.
2. The printed bob pin was unreliable; a toothpick was used successfully instead.
3. The pendulum still occasionally touched the frame or case. Inexact post spacing contributed.
4. Pendulum motion visibly rocked the case, with no clear running problem reported from that effect alone.
5. The clock rolled well on an 80 cm board raised 4 cm, and also at 3 cm. At 2 cm, setting the pendulum clamp angle was finicky.
6. The main axle crosspins worked, but screws were preferred for consistency and easier assembly.

Requested changes: square, flat-ended posts with captive M3 nuts; M3x10 and M3x16 fasteners; 5.25 mm nut-slot width; loose locating lips; a thicker rolling rim; more pendulum space; screw-retained axle and bob; one frame design supporting 16x, 32x and 64x; and a new illustrated build guide. A few centimetres of extra width were acceptable.

Nut-access clarification: the originally requested 5.25 mm applied only to the final anti-rotation seat. The insertion channel should be wider, approximately 5.8 mm, especially on the pendulum bob.

Physical coupon result: after printing and trying the coupons, the builder selected **5.6 mm** for all final nut seats. This supersedes the original 5.25 mm request. Current R3 production parts use 5.6 mm seats throughout, with the 5.8 mm insertion channels retained. The labelled comparison coupons remain unchanged.

R3 is a response to these observations. Its subsequent running report is recorded below. The previous working version is preserved under the v0.1.0 repository tag.

## Pivot-foot issue - 7 October 2026

The builder found in the slicer that the gear-pivot nut slot nearly severed the shaft from its base and could expose the nut near a gear. At this point the printed R3 parts were the four 32x wheels, reversed anchor, rear frame, anchor bridge, three frame posts and two bridge posts. Widening was acceptable.

The CAD confirmed that the 2.8 mm nut pocket reached 1.2 mm above the original 4.5 mm foot into the 8 mm journal. Connected-mesh and collision checks had not caught this weak section. The correction uses 10.5 mm feet on both pivot types, a blind bolt bore below the shaft, and a 6 mm forward shift of the mechanism. Frame posts become 54 mm long and overall plastic width becomes 186 mm. Of the reported printed parts, only the three frame posts need replacement. At that point, physical strength and running tests were pending.

## Successful roll and faceted rim - 8 October 2026

After printing and fitting the missing rear thrust collar 38, the builder reported: "Printed well, rolls well". The remaining reported issue was a visibly faceted outer rim: the wheel appeared to move from one flat face to the next, and the flats could be seen in reflected light and felt by hand. The ongoing build was prepared for 32:1; this message does not independently confirm trials of all three gear sets. Timing accuracy and durability remain unmeasured.

Inspection of the exported wheel STL found exactly 192 outer angular vertices, 4.058 mm between neighbours and 0.01660 mm ideal radial chord error. The source circle used 48 segments per quadrant. The correction refines only that outside circle to 384 segments per quadrant (1,536 total), retaining all mounting features and every other print file. The revised STL and a finer slicing-resolution suggestion are ready for a new print; smoother physical rolling is not yet confirmed.

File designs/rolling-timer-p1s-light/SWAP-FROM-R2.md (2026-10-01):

# Lightweight replacement pack for the revision-2 timer

Print these three replacement STLs:

1. `05_rear_carrier.stl`: triangular rear frame, integrated B pivot and bowl bracket.
2. `06_front_carrier.stl`: triangular front frame, integrated B bearing and pendulum-bridge mounts.
3. `08_open_ballast_bucket.stl`: open bowl with two upper M3 nut pockets and two lower contact pads.

All other retained STLs are byte-identical to revision 2. Reuse the square axle, round bearing sleeves, gears, escapement, pendulum, drum wheels and their existing spacers/pins.

## Quantity changes

- Use **three** carrier posts 07, at the new frame holes. The six long drum posts 02 are unchanged.
- Omit all four bowl pins 09.
- Omit both B modules 31 and 32 and all six pins 33; their functions are integrated into the new frames.
- Add two **M3 x10** flat-under-head cap/button/pan screws and two plain M3 nuts for the bowl. The existing pendulum-clamp screw is separate.

The two frame prints together have 49.8 cm3 CAD solid volume rather than 145.2 cm3 for the original grid discs, a 65.7% reduction. Actual sliced print time and filament depend on settings. The rear frame is 128.3 x 188.9 x 41 mm; front is 120 x 163.9 x 9 mm.

## Assembly changes

The exported orientations put each frame's outside face on the bed. The rear B pivot prints pointing up; the front blind B seat opens upward. Print the bowl mouth upward. Start with 5-6 walls and 5 top/bottom layers for the frames.

Seat the two plain nuts inside the bowl. Bring the bowl against the rear frame and insert the M3 x10 screws from the gear side into the recessed upper holes. The screw heads sit on 2.5 mm-thick material; together with the 2 mm bowl bosses and 2.4 mm bowl wall, the plastic grip is 6.9 mm. A 2.4 mm plain nut leaves 0.7 mm of screw beyond it. Use the stack without washers. See `bowl-bolt-section.png`.

The two lower pads rest against the frame without fasteners. Tighten the top screws gently until the bosses and pads sit against the frame. Keep the bowl empty until the fasteners are fitted; start the running trial with about 600 g of ballast.

The new frame-post positions are (-76,-52), (32,-50), (-26,55), using the original coordinate system. All gear, pendulum and main-bearing positions stay unchanged. Fit the B compound straight onto the rear frame's integral pivot; the front frame now contains its mating blind bearing. No module mounting step remains.

Follow the included `ASSEMBLY.md` for the complete sequence. This pair is dedicated to 16:1 and does not have the original frame's upgrade grid. Geometric motion and screw-clearance checks passed; physical fit, frame stiffness and sustained running remain to be tried.

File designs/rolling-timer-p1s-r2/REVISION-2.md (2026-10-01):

# Revision 2 - print support and square drive

This is the new complete print set. Use matching revision-2 drive parts together.

## Through pinions

The green 18/72 compound (11) now carries its 18-tooth pinion profile through all 16 mm of thickness. The yellow escape compound (12) carries its pinion through all 17 mm. Their large wheel faces remain the printing faces. This removes the unsupported starts at the small pinion teeth in the old design. Gear ratios, phases, pitch, centre distances and outer envelopes are unchanged.

The same through-pinion change is included in the optional 32:1 compounds U02-U04. That remains a development set; build and test 16:1 first.

## Square drive with round bearing sleeves

Main shaft 03 is 8 x 8 x 140 mm, with 1.4 mm corner chamfers. The orange gear and both blue drum wheels have matching sockets, 8.30 mm across flats. Chamfers keep the profile inside a small round envelope; the four long flats provide the positive drive.

The weighted carrier must stay free to turn relative to this shaft. Two separately printed sleeves have square sockets inside and 12 mm round exteriors. They rotate with the shaft inside the existing 12.4 mm carrier bores. Minimum sleeve wall at a socket corner is about 1.07 mm. Their extended lengths locate them between the wheel hubs and the existing thrust stack.

The three printed crosspins remain as axial retainers. Wheel and gear hub slots have tangential relief, so the square drive can engage without relying on the pins to transmit torque. Thrust pieces 34 and 35 now have square sockets too.

The shaft prints lying on its long flat, with length along the bed; the sleeves print upright. Print square coupon 38 and key 39 first. Nominal clearances must be calibrated to the actual PLA print.

## Changed print files

| Part | Change |
|---|---|
| 01_case_wheel, quantity 2 | Square socket; relieved retaining slot |
| 03_main_shaft | Chamfered square section; lying-flat print orientation |
| 10_drive_72 | Square socket; relieved retaining slot |
| 11_compound_18_72 | Pinion teeth through the full thickness |
| 12_escape_compound | Pinion teeth through the full thickness |
| 34_main_front_thrust_sleeve | Square socket |
| 35_main_rear_thrust_washer | Square socket |
| 36_rear_round_journal | New; OD12 x 66.6 mm |
| 37_front_round_journal | New; OD12 x 23.6 mm |
| 38_square_fit_coupon, 39_square_fit_key | New fit tests, not assembly parts |

Both reusable carrier plates (05 and 06) and all their mounting locations are unchanged. The earlier STL package, Blender scene and illustrated PDF remain revision 1. This package has updated assembly instructions and perspective renders; it does not silently mix the old guide with the new shaft.

## Checks and limits

See assembly-checks.json, motion-checks.json and revision-checks.json. The geometry has been checked for intersections, gear engagement, the full-turn keyed rotor and pinion support in the supplied print orientation. No physical printing, shaft strength, friction or sustained-running test has been performed. Fit, smooth motion and timing still need the first prototype trial.

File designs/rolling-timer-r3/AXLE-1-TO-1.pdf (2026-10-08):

04 / AXLE IDENTIFICATION AT ACTUAL SIZE

# Main axle: rear, front and gear orientation

Corrected R3 • 54 mm frame posts • 186 mm axle • identical for 16x / 32x / 64x

REAR — main ballast bowl side | FRONT — pendulum side

CHECK THE ASSEMBLY

Long side of the middle hole: REAR (97 mm).

Fix gear 10 at this middle hole with one M3x16 screw + nut.

38 surrounds rear journal 36. It fits between frame 05
and rear thrust washer 35. Parts are in their assembled positions. Small gaps are
intentional; do not clamp tight.

Rear frame collar shown in section. Other frame parts / drum omitted.

Lay the bare axle on the outline below to identify its three holes.

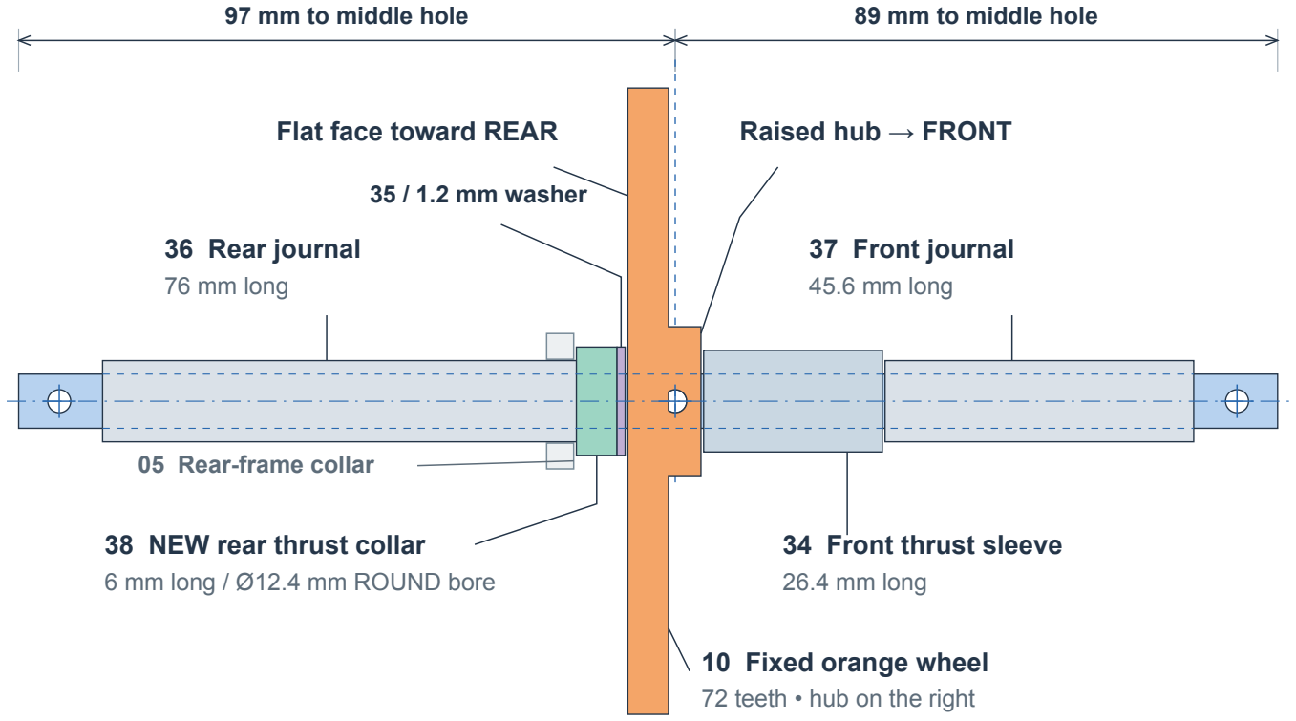
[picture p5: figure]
97 mm to middle hole; 89 mm to middle hole; 36 Rear journal; 76 mm long; 37 Front journal; 45.6 mm long; 35 / 1.2 mm washer; 05 Rear-frame collar; 38 NEW rear thrust collar; 6 mm long / Ø12.4 mm ROUND bore; 34 Front thrust sleeve; 26.4 mm long; Flat face toward REAR; Raised hub → FRONT; 10 Fixed orange wheel; 72 teeth • hub on the right

BARE AXLE 03 • 8 mm square • Ø3.4 mm cross-holes

Hole labels are measured from the REAR end. Both end holes are 6 mm from their nearest end.

This bar must measure 50 mm

Print A4 landscape at 100% / Actual size. Disable Fit / Shrink. Check the bar first.

ROLLING CLOCK R3 | TRUE 1:1 VECTOR DRAWING | 8 OCTOBER 2026 | 1 / 1

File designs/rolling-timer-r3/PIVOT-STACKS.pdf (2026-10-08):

05 / RATIO-SPECIFIC ASSEMBLY REFERENCE

# 16:1 - spacer order and wheel orientation

Side diagrams show the assembled order. Axial positions come from CAD; diameters are compressed. Not 1:1.

PIVOT MAP | REAR / ballast bowl side | FRONT / pendulum side

Seen from the front

A

B16

Bslow

C D

P

B uses B16.
Gear files: STL/16x/

Spacer label: part / length.

Anchor file:
STL/16x/

18_anchor_forward.stl

Pinions always face REAR.
Anchor sleeve faces FRONT.

13 = short gear pivot
19 = long anchor pivot

Rear spacers sit against the pivot foot, ahead of frame 05.

B

05 06

13 foot

15 / 1.2 mm | 16 / 23.7 mm

11

11_B_18_72.stl
18T pinion toward REAR
72T wheel toward FRONT

15 (1.2) > 11 > 16 (23.7) > front frame 06

C

05 06

13 foot

17 / 13.2 mm | 27 / 4.7 mm
| 12

12_escape_compound.stl
18T pinion toward REAR
30T escape teeth toward FRONT

17 (13.2) > 12 > 27 (4.7) > front frame 06

P

05

06

22

19 foot

20 / 34.2 mm | 21 / 7.7 mm
18 24

long sleeve

Bridge
22

20 (34.2) > 18 [sleeve forward] > 21 (7.7) > bridge 22

P: sleeve 18 passes through frame 06; clamp 24 surrounds its front end. Spacer 21 goes beyond both.

One of each spacer shown. Use common/ for 20 and 21. Main axle A and its sleeves: guide page 6 / AXLE-1-TO-1.pdf.

Corrected 54 mm frame posts. Nominal gear endplay: 0.6 mm total. Do not squeeze rotating parts between fixed faces.

ROLLING CLOCK R3 | 16:1 PIVOT STACKS | NUMBERS = STL FILE PREFIXES | 1 / 3

# 32:1 - spacer order and wheel orientation

Side diagrams show the assembled order. Axial positions come from CAD; diameters are compressed. Not 1:1.

PIVOT MAP | REAR / ballast bowl side | FRONT / pendulum side

Seen from the front

A

B16

Bslow

C D

P

B uses Bslow.
Gear files: STL/32x/

Spacer label: part / length.

Anchor file:
STL/slow-common/

18_anchor_reversed.stl

Pinions always face REAR.
Anchor sleeve faces FRONT.

13 = short gear pivot
19 = long anchor pivot

Rear spacers sit against the pivot foot, ahead of frame 05.

B

05 06

13 foot

15 / 1.2 mm | 16 / 23.7 mm

11

11_B_18_72.stl
18T pinion toward REAR
72T wheel toward FRONT

15 (1.2) > 11 > 16 (23.7) > front frame 06

D

05 06

13 foot

28 / 13.2 mm | 29 / 11.7 mm

14

14_D_18_60.stl
18T pinion toward REAR
60T wheel toward FRONT

28 (13.2) > 14 > 29 (11.7) > front frame 06

C

05 06

13 foot

17 / 25.2 mm | 27 / 4.7 mm
| 12

12_escape_compound.stl
30T pinion toward REAR
30T escape teeth toward FRONT

17 (25.2) > 12 > 27 (4.7) > front frame 06

P

05

06

22

19 foot

20 / 34.2 mm | 21 / 7.7 mm
18 24

long sleeve

Bridge
22

20 (34.2) > 18 [sleeve forward] > 21 (7.7) > bridge 22

P: sleeve 18 passes through frame 06; clamp 24 surrounds its front end. Spacer 21 goes beyond both.

One of each spacer shown. Use common/ for 20 and 21. Main axle A and its sleeves: guide page 6 / AXLE-1-TO-1.pdf.

ROLLING CLOCK R3 | 32:1 PIVOT STACKS | NUMBERS = STL FILE PREFIXES | 2 / 3

# 64:1 - spacer order and wheel orientation

Side diagrams show the assembled order. Axial positions come from CAD; diameters are compressed. Not 1:1.

PIVOT MAP | REAR / ballast bowl side | FRONT / pendulum side

Seen from the front

A

B16

Bslow

C D

P

B uses Bslow.
Gear files: STL/64x/

Spacer label: part / length.

Anchor file:
STL/slow-common/

18_anchor_reversed.stl

Pinions always face REAR.
Anchor sleeve faces FRONT.

13 = short gear pivot
19 = long anchor pivot

Rear spacers sit against the pivot foot, ahead of frame 05.

B

05 06

13 foot

15 / 1.2 mm | 16 / 23.7 mm

11

11_B_18_72.stl
18T pinion toward REAR
72T wheel toward FRONT

15 (1.2) > 11 > 16 (23.7) > front frame 06

D

05 06

13 foot

28 / 13.2 mm | 29 / 11.7 mm

14

14_D_18_72.stl
18T pinion toward REAR
72T wheel toward FRONT

28 (13.2) > 14 > 29 (11.7) > front frame 06

C

05 06

13 foot

17 / 25.2 mm | 27 / 4.7 mm
| 12

12_escape_compound.stl
18T pinion toward REAR
30T escape teeth toward FRONT

17 (25.2) > 12 > 27 (4.7) > front frame 06

P

05

06

22

19 foot

20 / 34.2 mm | 21 / 7.7 mm
18 24

long sleeve

Bridge
22

20 (34.2) > 18 [sleeve forward] > 21 (7.7) > bridge 22

P: sleeve 18 passes through frame 06; clamp 24 surrounds its front end. Spacer 21 goes beyond both.

One of each spacer shown. Use common/ for 20 and 21. Main axle A and its sleeves: guide page 6 / AXLE-1-TO-1.pdf.

ROLLING CLOCK R3 | 64:1 PIVOT STACKS | NUMBERS = STL FILE PREFIXES | 3 / 3

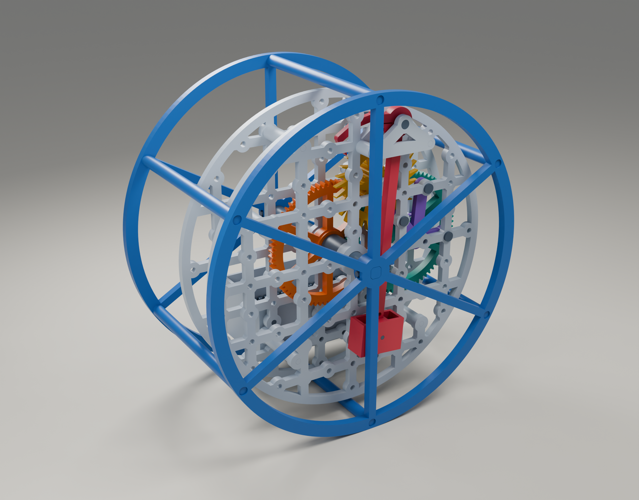
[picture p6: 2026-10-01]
designs/rolling-timer-p1s-r2/renders/perspective-front.png

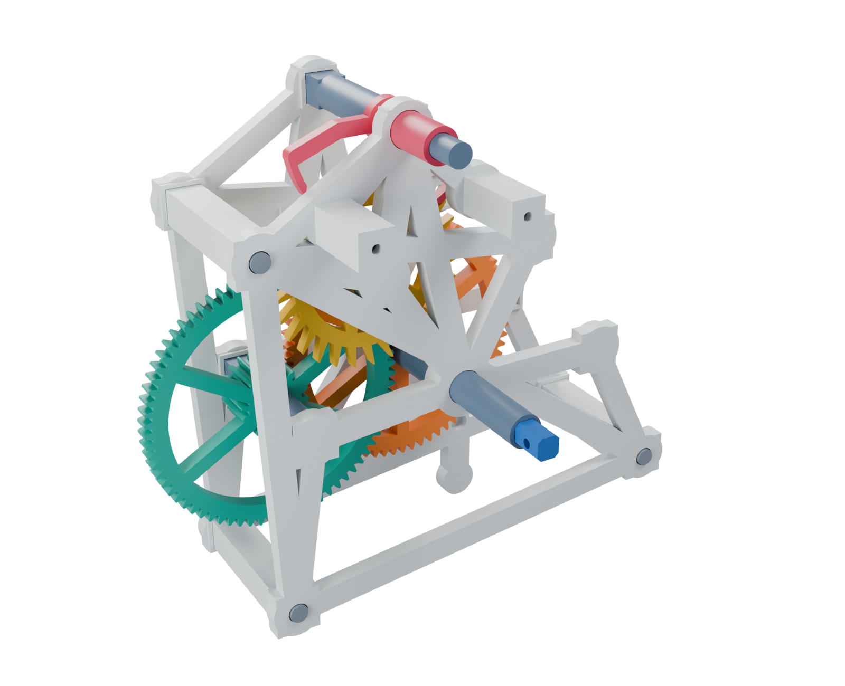
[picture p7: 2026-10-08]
designs/rolling-timer-r3/renders/close-front-frame.png

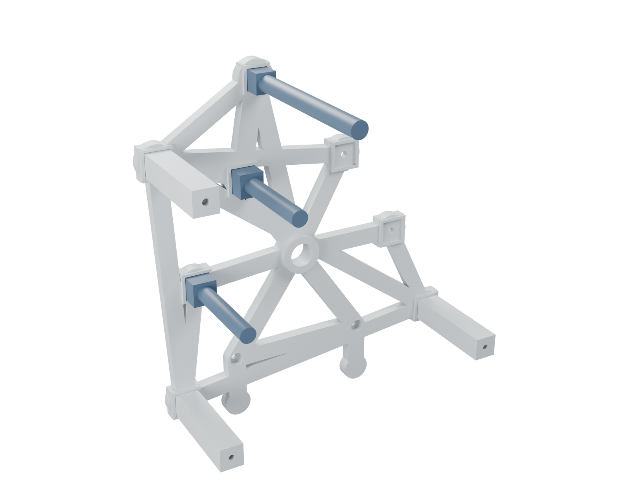
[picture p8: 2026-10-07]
designs/rolling-timer-r3/renders/frame-and-pivots.png

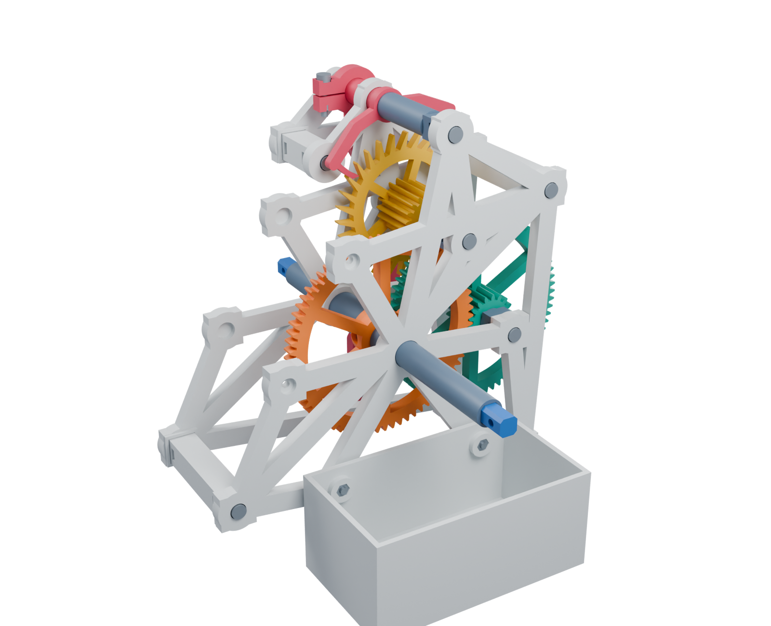
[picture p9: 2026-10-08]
designs/rolling-timer-r3/renders/bowl-rear.png

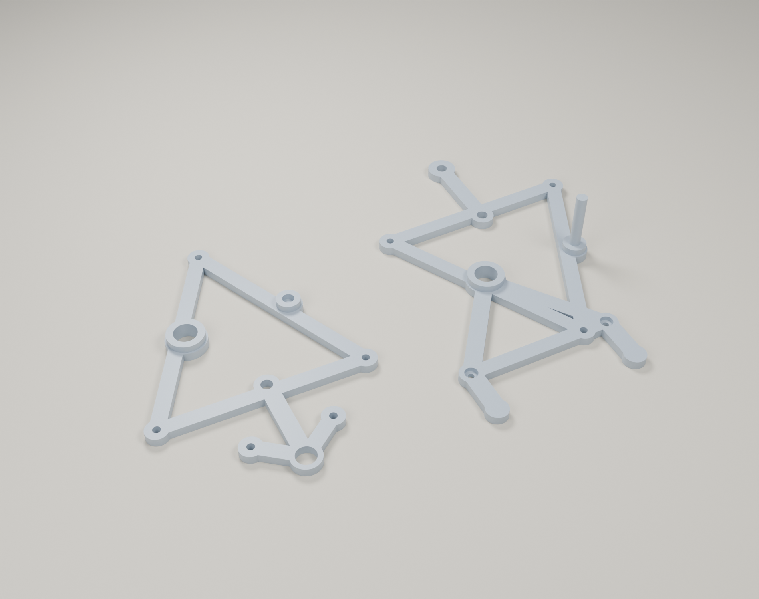
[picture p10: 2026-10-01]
designs/rolling-timer-p1s-light/renders/lightweight-frames.png

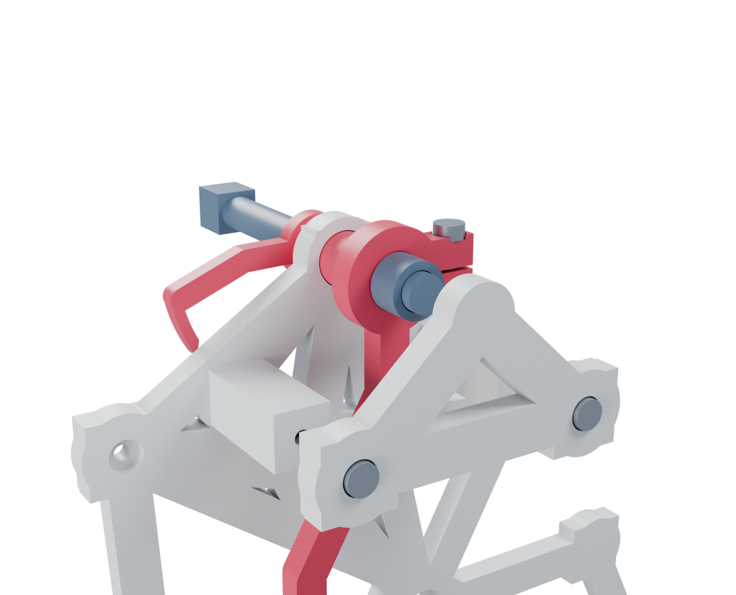
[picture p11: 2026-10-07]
designs/rolling-timer-r3/renders/bridge-detail.png

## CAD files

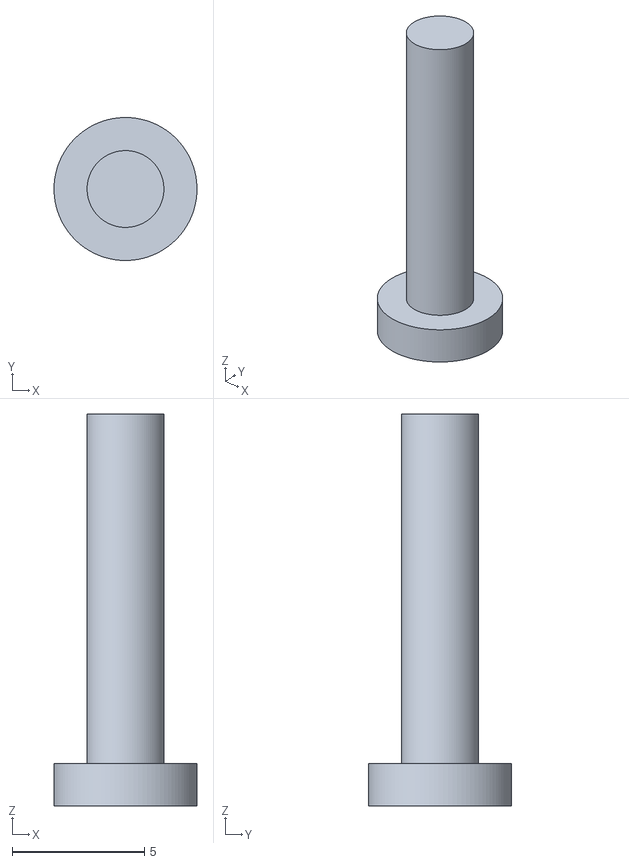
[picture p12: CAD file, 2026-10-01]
designs/rolling-timer-p1s-light/bob-1mm/assembly/26_pin_assembled.stl
5.40 x 5.40 x 14.8

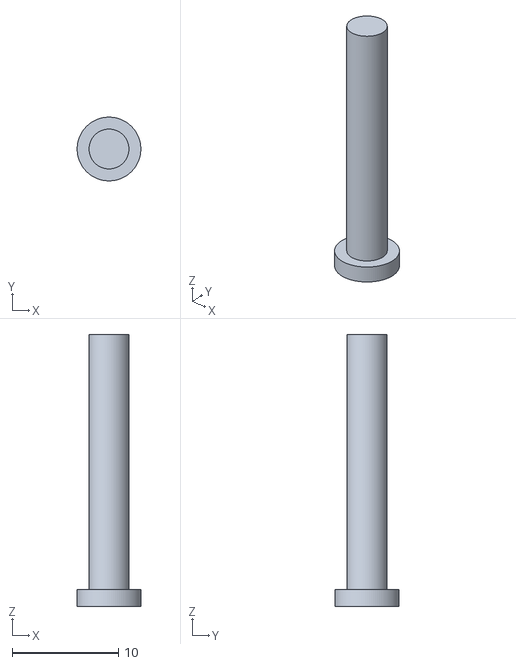
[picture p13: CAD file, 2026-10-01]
designs/rolling-timer-p1s-r2/STL/04_main_crosspin.stl
6.00 x 6.00 x 25.6

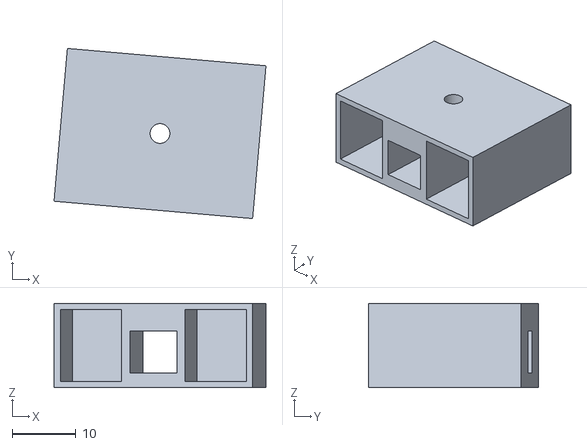
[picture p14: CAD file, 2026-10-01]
designs/rolling-timer-p1s-light/bob-1mm/assembly/25_bob_assembled.stl
33.2 x 26.6 x 13.2

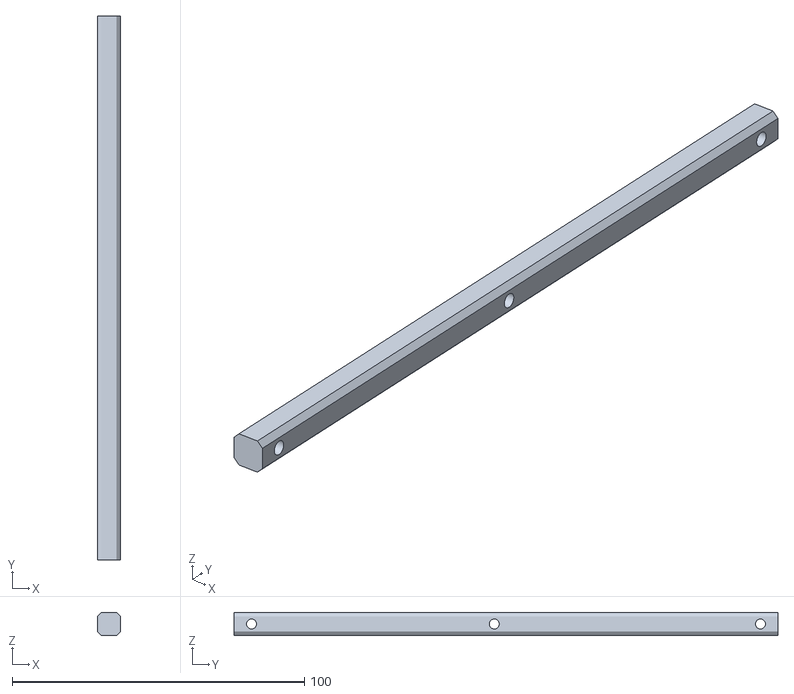
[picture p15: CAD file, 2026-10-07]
designs/rolling-timer-r3/STL/common/03_square_main_axle.stl
8.00 x 186.0 x 8.00

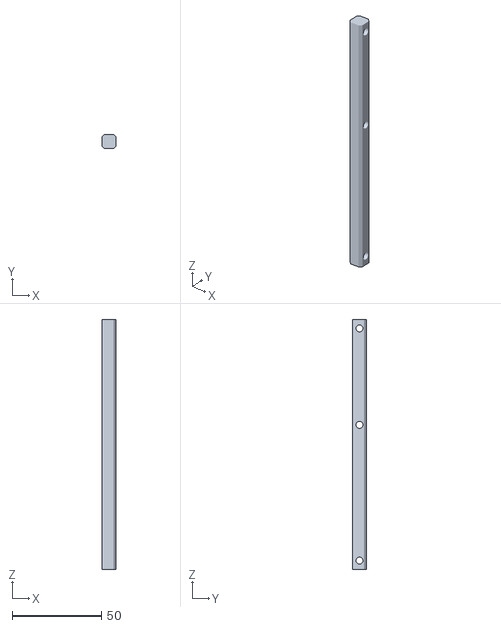
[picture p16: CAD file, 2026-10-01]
designs/rolling-timer-p1s-light/source/assembly/08_03_main_shaft.stl
8.00 x 8.00 x 140.0

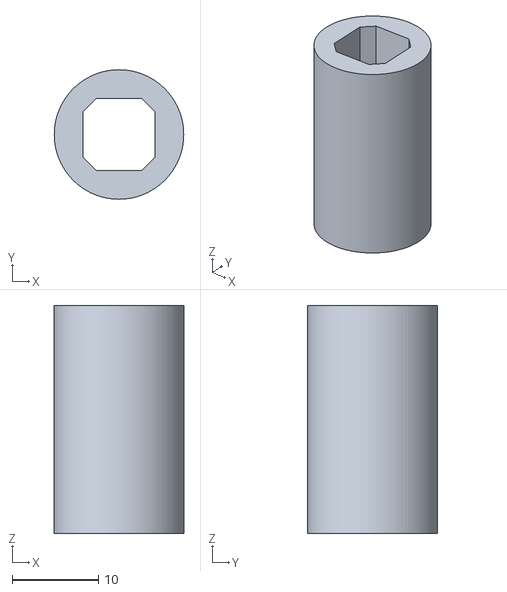
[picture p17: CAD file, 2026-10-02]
designs/rolling-timer-r3/STL/common/34_main_front_thrust_sleeve.stl
15.0 x 15.0 x 26.4

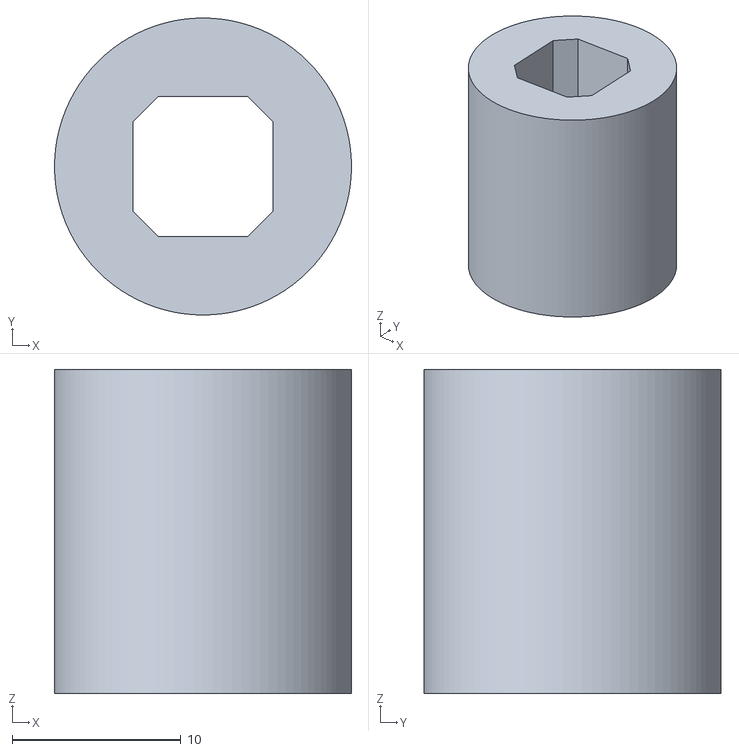
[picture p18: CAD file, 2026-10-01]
designs/rolling-timer-p1s-r2/source/assembly/38_34_main_front_thrust_sleeve.stl
17.6 x 17.6 x 19.2

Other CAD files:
designs/rolling-timer-p1s-light/STL/34_main_front_thrust_sleeve.stl
designs/rolling-timer-p1s-r2/STL/03_main_shaft.stl
designs/rolling-timer-p1s-light/source/assembly/09_04_main_crosspin.stl
designs/rolling-timer-p1s-light/STL/03_main_shaft.stl
designs/rolling-timer-p1s-r2/source/assembly/09_04_main_crosspin.stl
designs/rolling-timer-r3/assembly/32x/103_34_main_front_thrust_sleeve.stl
designs/rolling-timer-p1s-light/source/assembly/10_04_main_crosspin.stl
designs/rolling-timer-p1s-r2/source/assembly/11_04_main_crosspin.stl
designs/rolling-timer-p1s-light/STL/01_case_wheel.stl
designs/rolling-timer-p1s-light/STL/02_case_post.stl
designs/rolling-timer-p1s-light/STL/05_rear_carrier.stl
designs/rolling-timer-p1s-light/STL/06_front_carrier.stl
designs/rolling-timer-p1s-light/STL/07_carrier_post.stl
designs/rolling-timer-p1s-light/STL/08_open_ballast_bucket.stl
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

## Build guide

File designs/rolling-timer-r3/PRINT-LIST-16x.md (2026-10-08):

# R3 print list - 16:1

One complete 16:1 clock. Keep the folder names: identically numbered gear files differ between ratios. Dimensions are millimetres. See BUILD-GUIDE.pdf.

Hardware: **15 M3x10**, **17 M3x16**, **32 plain M3 nuts**. Fit coupons are optional extras.

| File | Qty | Print envelope | Orientation / note |
|---|---:|---|---|
| [common/01_case_wheel.stl](STL/common/01_case_wheel.stl) | 2 | 248 x 248 x 12 | Flat outer face on bed, hub and locating lips up. Diameter 248 mm, 1536-side rolling rim. Slicer Resolution: try 0.001 mm; arc fitting on. No outer brim. |
| [common/02_square_case_post.stl](STL/common/02_square_case_post.stl) | 6 | 172 x 10 x 10 | 172 mm long. Long flat side on bed; both nut-slot mouths upward. Preload two M3 nuts. End bolts M3x16. |
| [common/03_square_main_axle.stl](STL/common/03_square_main_axle.stl) | 1 | 8 x 186 x 8 | 186 mm long. Long flat on bed; solid. Cross-holes at 6, 97 and 180 mm from the rear end. |
| [common/05_shared_rear_frame.stl](STL/common/05_shared_rear_frame.stl) | 1 | 171 x 186.353 x 10 | Flat outside face on bed; lips and main collar up. Universal 16/32/64 frame. |
| [common/06_shared_front_frame.stl](STL/common/06_shared_front_frame.stl) | 1 | 171 x 178.353 x 10 | Outside face on bed; all locating lips point up. Bridge posts locate in the bridge at their other ends. |
| [common/07_square_frame_post.stl](STL/common/07_square_frame_post.stl) | 3 | 54 x 12 x 12 | Long flat side on bed, nut slots up. Flat ends set the 54 mm frame gap; M3x10 at both ends. |
| [common/08_open_ballast_bowl.stl](STL/common/08_open_ballast_bowl.stl) | 1 | 104 x 62 x 46 | Mouth up. Two M3x10 screws and two nuts; lower pads rest on the frame. |
| [common/10_drive_72.stl](STL/common/10_drive_72.stl) | 1 | 92.5 x 92.5 x 10.8 | Broad wheel on bed, hub up. M3x16 retains the square axle. |
| [common/13_bolted_gear_pivot.stl](STL/common/13_bolted_gear_pivot.stl) | 2 | 12 x 12 x 56.5 | Solid print, square foot on bed; 10.5 mm foot and solid 8 mm journal. One M3x10 at rear; tip has 0.5 mm clearance in the front blind seat. |
| [common/19_bolted_anchor_pivot.stl](STL/common/19_bolted_anchor_pivot.stl) | 1 | 10 x 10 x 89.5 | Solid print, square foot on bed; 10.5 mm foot fully contains the nut slot. M3x10 at rear; bridge supports the long tip. |
| [common/20_anchor_rear_spacer.stl](STL/common/20_anchor_rear_spacer.stl) | 1 | 12 x 12 x 34.2 | Flat annular face on bed; 34.2 mm long. |
| [common/21_anchor_front_spacer.stl](STL/common/21_anchor_front_spacer.stl) | 1 | 12 x 12 x 7.7 | Flat annular face on bed; 7.7 mm long. |
| [common/22_bolted_anchor_bridge.stl](STL/common/22_bolted_anchor_bridge.stl) | 1 | 70 x 40 x 7.5 | Outer face on bed; shallow locating lips upward. M3x10 at each end. |
| [common/23_square_bridge_post.stl](STL/common/23_square_bridge_post.stl) | 2 | 27 x 12 x 12 | Flat side on bed, nut mouths up. Two M3x10 per post. Hard shoulders set the bridge position. |
| [common/24_offset_pendulum.stl](STL/common/24_offset_pendulum.stl) | 1 | 42.5 x 177 x 6 | Broad face on bed. Dogleg clears the main shaft. M3x16 clamp; 3.4 mm bob holes. |
| [common/25_screw_fixed_bob.stl](STL/common/25_screw_fixed_bob.stl) | 1 | 31.2 x 13.2 x 24 | Open mouth up. 1 mm outer walls; 5.8 mm nut channel tapers to a 5.6 mm seat. Use one M3x16 through the selected rod hole. |
| [common/34_main_front_thrust_sleeve.stl](STL/common/34_main_front_thrust_sleeve.stl) | 1 | 15 x 15 x 26.4 | Flat annular end on bed, 26.4 mm long. Square bore keys to axle. |
| [common/35_main_rear_thrust_washer.stl](STL/common/35_main_rear_thrust_washer.stl) | 1 | 16 x 16 x 1.2 | Flat annular end on bed, 1.2 mm long. Square bore keys to axle. |
| [common/36_rear_round_journal.stl](STL/common/36_rear_round_journal.stl) | 1 | 12 x 12 x 76 | Flat annular end on bed, 76 mm long. Square bore keys to axle. |
| [common/37_front_round_journal.stl](STL/common/37_front_round_journal.stl) | 1 | 12 x 12 x 45.6 | Flat annular end on bed, 45.6 mm long. Square bore keys to axle. |
| [common/38_rear_journal_thrust_collar.stl](STL/common/38_rear_journal_thrust_collar.stl) | 1 | 16 x 16 x 6 | Flat annular end on bed. 6 mm long, 16 mm OD, 12.4 mm ROUND bore. Slides around journal 36, between the rear-frame collar and washer 35. One for every ratio. |
| [16x/11_B_18_72.stl](STL/16x/11_B_18_72.stl) | 1 | 92.5 x 92.5 x 18 | Large wheel on bed; pinion teeth continue down to the bed. Pinion faces rear in assembly. |
| [16x/12_escape_compound.stl](STL/16x/12_escape_compound.stl) | 1 | 67.907 x 67.907 x 25 | Escape face on bed; pinion extends through wheel. Use matching anchor direction. |
| [16x/15_B_rear_spacer.stl](STL/16x/15_B_rear_spacer.stl) | 1 | 12 x 12 x 1.2 | Flat annular face on bed; 1.2 mm long. |
| [16x/16_B_front_spacer.stl](STL/16x/16_B_front_spacer.stl) | 1 | 12 x 12 x 23.7 | Flat annular face on bed; 23.7 mm long. |
| [16x/17_C_rear_spacer.stl](STL/16x/17_C_rear_spacer.stl) | 1 | 12 x 12 x 13.2 | Flat annular face on bed; 13.2 mm long. |
| [16x/18_anchor_forward.stl](STL/16x/18_anchor_forward.stl) | 1 | 66.539 x 33.038 x 34 | Pallet faces on bed, sleeve up. Used only with 16x escape wheel. |
| [16x/27_C_front_spacer.stl](STL/16x/27_C_front_spacer.stl) | 1 | 12 x 12 x 4.7 | Flat annular face on bed; 4.7 mm long. |

## Fit coupons first

- [5.60 mm nut-post coupon - selected production fit](STL/fit-tests/40_nut_post_coupon_560.stl)
- [Matching frame-seat coupon](STL/fit-tests/41_post_seat_coupon.stl)
- Alternative nut seats: [5.25 mm](STL/fit-tests/40_nut_post_coupon_525.stl), [5.40 mm](STL/fit-tests/40_nut_post_coupon_540.stl). All insertion channels are 5.8 mm.

Print at 100% scale in the exported orientation. Do not rescale complete gears to change a fit. All parts must be R3.

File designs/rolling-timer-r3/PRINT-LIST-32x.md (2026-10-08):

# R3 print list - 32:1

One complete 32:1 clock. Keep the folder names: identically numbered gear files differ between ratios. Dimensions are millimetres. See BUILD-GUIDE.pdf.

Hardware: **16 M3x10**, **17 M3x16**, **33 plain M3 nuts**. Fit coupons are optional extras.

| File | Qty | Print envelope | Orientation / note |
|---|---:|---|---|
| [common/01_case_wheel.stl](STL/common/01_case_wheel.stl) | 2 | 248 x 248 x 12 | Flat outer face on bed, hub and locating lips up. Diameter 248 mm, 1536-side rolling rim. Slicer Resolution: try 0.001 mm; arc fitting on. No outer brim. |
| [common/02_square_case_post.stl](STL/common/02_square_case_post.stl) | 6 | 172 x 10 x 10 | 172 mm long. Long flat side on bed; both nut-slot mouths upward. Preload two M3 nuts. End bolts M3x16. |
| [common/03_square_main_axle.stl](STL/common/03_square_main_axle.stl) | 1 | 8 x 186 x 8 | 186 mm long. Long flat on bed; solid. Cross-holes at 6, 97 and 180 mm from the rear end. |
| [common/05_shared_rear_frame.stl](STL/common/05_shared_rear_frame.stl) | 1 | 171 x 186.353 x 10 | Flat outside face on bed; lips and main collar up. Universal 16/32/64 frame. |
| [common/06_shared_front_frame.stl](STL/common/06_shared_front_frame.stl) | 1 | 171 x 178.353 x 10 | Outside face on bed; all locating lips point up. Bridge posts locate in the bridge at their other ends. |
| [common/07_square_frame_post.stl](STL/common/07_square_frame_post.stl) | 3 | 54 x 12 x 12 | Long flat side on bed, nut slots up. Flat ends set the 54 mm frame gap; M3x10 at both ends. |
| [common/08_open_ballast_bowl.stl](STL/common/08_open_ballast_bowl.stl) | 1 | 104 x 62 x 46 | Mouth up. Two M3x10 screws and two nuts; lower pads rest on the frame. |
| [common/10_drive_72.stl](STL/common/10_drive_72.stl) | 1 | 92.5 x 92.5 x 10.8 | Broad wheel on bed, hub up. M3x16 retains the square axle. |
| [common/13_bolted_gear_pivot.stl](STL/common/13_bolted_gear_pivot.stl) | 3 | 12 x 12 x 56.5 | Solid print, square foot on bed; 10.5 mm foot and solid 8 mm journal. One M3x10 at rear; tip has 0.5 mm clearance in the front blind seat. |
| [common/19_bolted_anchor_pivot.stl](STL/common/19_bolted_anchor_pivot.stl) | 1 | 10 x 10 x 89.5 | Solid print, square foot on bed; 10.5 mm foot fully contains the nut slot. M3x10 at rear; bridge supports the long tip. |
| [common/20_anchor_rear_spacer.stl](STL/common/20_anchor_rear_spacer.stl) | 1 | 12 x 12 x 34.2 | Flat annular face on bed; 34.2 mm long. |
| [common/21_anchor_front_spacer.stl](STL/common/21_anchor_front_spacer.stl) | 1 | 12 x 12 x 7.7 | Flat annular face on bed; 7.7 mm long. |
| [common/22_bolted_anchor_bridge.stl](STL/common/22_bolted_anchor_bridge.stl) | 1 | 70 x 40 x 7.5 | Outer face on bed; shallow locating lips upward. M3x10 at each end. |
| [common/23_square_bridge_post.stl](STL/common/23_square_bridge_post.stl) | 2 | 27 x 12 x 12 | Flat side on bed, nut mouths up. Two M3x10 per post. Hard shoulders set the bridge position. |
| [common/24_offset_pendulum.stl](STL/common/24_offset_pendulum.stl) | 1 | 42.5 x 177 x 6 | Broad face on bed. Dogleg clears the main shaft. M3x16 clamp; 3.4 mm bob holes. |
| [common/25_screw_fixed_bob.stl](STL/common/25_screw_fixed_bob.stl) | 1 | 31.2 x 13.2 x 24 | Open mouth up. 1 mm outer walls; 5.8 mm nut channel tapers to a 5.6 mm seat. Use one M3x16 through the selected rod hole. |
| [common/34_main_front_thrust_sleeve.stl](STL/common/34_main_front_thrust_sleeve.stl) | 1 | 15 x 15 x 26.4 | Flat annular end on bed, 26.4 mm long. Square bore keys to axle. |
| [common/35_main_rear_thrust_washer.stl](STL/common/35_main_rear_thrust_washer.stl) | 1 | 16 x 16 x 1.2 | Flat annular end on bed, 1.2 mm long. Square bore keys to axle. |
| [common/36_rear_round_journal.stl](STL/common/36_rear_round_journal.stl) | 1 | 12 x 12 x 76 | Flat annular end on bed, 76 mm long. Square bore keys to axle. |
| [common/37_front_round_journal.stl](STL/common/37_front_round_journal.stl) | 1 | 12 x 12 x 45.6 | Flat annular end on bed, 45.6 mm long. Square bore keys to axle. |
| [common/38_rear_journal_thrust_collar.stl](STL/common/38_rear_journal_thrust_collar.stl) | 1 | 16 x 16 x 6 | Flat annular end on bed. 6 mm long, 16 mm OD, 12.4 mm ROUND bore. Slides around journal 36, between the rear-frame collar and washer 35. One for every ratio. |
| [32x/11_B_18_72.stl](STL/32x/11_B_18_72.stl) | 1 | 92.5 x 92.5 x 18 | Large wheel on bed; pinion teeth continue down to the bed. Pinion faces rear in assembly. |
| [32x/12_escape_compound.stl](STL/32x/12_escape_compound.stl) | 1 | 67.741 x 67.99 x 13 | Escape face on bed; pinion extends through wheel. Use matching anchor direction. |
| [32x/14_D_18_60.stl](STL/32x/14_D_18_60.stl) | 1 | 77.5 x 77.5 x 18 | Large wheel on bed; pinion faces rear. Both pivot ends supported. |
| [32x/15_B_rear_spacer.stl](STL/32x/15_B_rear_spacer.stl) | 1 | 12 x 12 x 1.2 | Flat annular face on bed; 1.2 mm long. |
| [32x/16_B_front_spacer.stl](STL/32x/16_B_front_spacer.stl) | 1 | 12 x 12 x 23.7 | Flat annular face on bed; 23.7 mm long. |
| [32x/17_C_rear_spacer.stl](STL/32x/17_C_rear_spacer.stl) | 1 | 12 x 12 x 25.2 | Flat annular face on bed; 25.2 mm long. |
| [32x/27_C_front_spacer.stl](STL/32x/27_C_front_spacer.stl) | 1 | 12 x 12 x 4.7 | Flat annular face on bed; 4.7 mm long. |
| [32x/28_D_rear_spacer.stl](STL/32x/28_D_rear_spacer.stl) | 1 | 12 x 12 x 13.2 | Flat annular face on bed; 13.2 mm long. |
| [32x/29_D_front_spacer.stl](STL/32x/29_D_front_spacer.stl) | 1 | 12 x 12 x 11.7 | Flat annular face on bed; 11.7 mm long. |
| [slow-common/18_anchor_reversed.stl](STL/slow-common/18_anchor_reversed.stl) | 1 | 66.539 x 33.038 x 34 | Pallet faces on bed, sleeve up. Used with 32x or 64x reversed escape wheels. |

## Fit coupons first

- [5.60 mm nut-post coupon - selected production fit](STL/fit-tests/40_nut_post_coupon_560.stl)
- [Matching frame-seat coupon](STL/fit-tests/41_post_seat_coupon.stl)
- Alternative nut seats: [5.25 mm](STL/fit-tests/40_nut_post_coupon_525.stl), [5.40 mm](STL/fit-tests/40_nut_post_coupon_540.stl). All insertion channels are 5.8 mm.

Print at 100% scale in the exported orientation. Do not rescale complete gears to change a fit. All parts must be R3.

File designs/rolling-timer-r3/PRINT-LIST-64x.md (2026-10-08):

# R3 print list - 64:1

One complete 64:1 clock. Keep the folder names: identically numbered gear files differ between ratios. Dimensions are millimetres. See BUILD-GUIDE.pdf.

Hardware: **16 M3x10**, **17 M3x16**, **33 plain M3 nuts**. Fit coupons are optional extras.

| File | Qty | Print envelope | Orientation / note |
|---|---:|---|---|
| [common/01_case_wheel.stl](STL/common/01_case_wheel.stl) | 2 | 248 x 248 x 12 | Flat outer face on bed, hub and locating lips up. Diameter 248 mm, 1536-side rolling rim. Slicer Resolution: try 0.001 mm; arc fitting on. No outer brim. |
| [common/02_square_case_post.stl](STL/common/02_square_case_post.stl) | 6 | 172 x 10 x 10 | 172 mm long. Long flat side on bed; both nut-slot mouths upward. Preload two M3 nuts. End bolts M3x16. |
| [common/03_square_main_axle.stl](STL/common/03_square_main_axle.stl) | 1 | 8 x 186 x 8 | 186 mm long. Long flat on bed; solid. Cross-holes at 6, 97 and 180 mm from the rear end. |
| [common/05_shared_rear_frame.stl](STL/common/05_shared_rear_frame.stl) | 1 | 171 x 186.353 x 10 | Flat outside face on bed; lips and main collar up. Universal 16/32/64 frame. |
| [common/06_shared_front_frame.stl](STL/common/06_shared_front_frame.stl) | 1 | 171 x 178.353 x 10 | Outside face on bed; all locating lips point up. Bridge posts locate in the bridge at their other ends. |
| [common/07_square_frame_post.stl](STL/common/07_square_frame_post.stl) | 3 | 54 x 12 x 12 | Long flat side on bed, nut slots up. Flat ends set the 54 mm frame gap; M3x10 at both ends. |
| [common/08_open_ballast_bowl.stl](STL/common/08_open_ballast_bowl.stl) | 1 | 104 x 62 x 46 | Mouth up. Two M3x10 screws and two nuts; lower pads rest on the frame. |
| [common/10_drive_72.stl](STL/common/10_drive_72.stl) | 1 | 92.5 x 92.5 x 10.8 | Broad wheel on bed, hub up. M3x16 retains the square axle. |
| [common/13_bolted_gear_pivot.stl](STL/common/13_bolted_gear_pivot.stl) | 3 | 12 x 12 x 56.5 | Solid print, square foot on bed; 10.5 mm foot and solid 8 mm journal. One M3x10 at rear; tip has 0.5 mm clearance in the front blind seat. |
| [common/19_bolted_anchor_pivot.stl](STL/common/19_bolted_anchor_pivot.stl) | 1 | 10 x 10 x 89.5 | Solid print, square foot on bed; 10.5 mm foot fully contains the nut slot. M3x10 at rear; bridge supports the long tip. |
| [common/20_anchor_rear_spacer.stl](STL/common/20_anchor_rear_spacer.stl) | 1 | 12 x 12 x 34.2 | Flat annular face on bed; 34.2 mm long. |
| [common/21_anchor_front_spacer.stl](STL/common/21_anchor_front_spacer.stl) | 1 | 12 x 12 x 7.7 | Flat annular face on bed; 7.7 mm long. |
| [common/22_bolted_anchor_bridge.stl](STL/common/22_bolted_anchor_bridge.stl) | 1 | 70 x 40 x 7.5 | Outer face on bed; shallow locating lips upward. M3x10 at each end. |
| [common/23_square_bridge_post.stl](STL/common/23_square_bridge_post.stl) | 2 | 27 x 12 x 12 | Flat side on bed, nut mouths up. Two M3x10 per post. Hard shoulders set the bridge position. |
| [common/24_offset_pendulum.stl](STL/common/24_offset_pendulum.stl) | 1 | 42.5 x 177 x 6 | Broad face on bed. Dogleg clears the main shaft. M3x16 clamp; 3.4 mm bob holes. |
| [common/25_screw_fixed_bob.stl](STL/common/25_screw_fixed_bob.stl) | 1 | 31.2 x 13.2 x 24 | Open mouth up. 1 mm outer walls; 5.8 mm nut channel tapers to a 5.6 mm seat. Use one M3x16 through the selected rod hole. |
| [common/34_main_front_thrust_sleeve.stl](STL/common/34_main_front_thrust_sleeve.stl) | 1 | 15 x 15 x 26.4 | Flat annular end on bed, 26.4 mm long. Square bore keys to axle. |
| [common/35_main_rear_thrust_washer.stl](STL/common/35_main_rear_thrust_washer.stl) | 1 | 16 x 16 x 1.2 | Flat annular end on bed, 1.2 mm long. Square bore keys to axle. |
| [common/36_rear_round_journal.stl](STL/common/36_rear_round_journal.stl) | 1 | 12 x 12 x 76 | Flat annular end on bed, 76 mm long. Square bore keys to axle. |
| [common/37_front_round_journal.stl](STL/common/37_front_round_journal.stl) | 1 | 12 x 12 x 45.6 | Flat annular end on bed, 45.6 mm long. Square bore keys to axle. |
| [common/38_rear_journal_thrust_collar.stl](STL/common/38_rear_journal_thrust_collar.stl) | 1 | 16 x 16 x 6 | Flat annular end on bed. 6 mm long, 16 mm OD, 12.4 mm ROUND bore. Slides around journal 36, between the rear-frame collar and washer 35. One for every ratio. |
| [64x/11_B_18_72.stl](STL/64x/11_B_18_72.stl) | 1 | 92.5 x 92.5 x 18 | Large wheel on bed; pinion teeth continue down to the bed. Pinion faces rear in assembly. |
| [64x/12_escape_compound.stl](STL/64x/12_escape_compound.stl) | 1 | 67.741 x 67.99 x 13 | Escape face on bed; pinion extends through wheel. Use matching anchor direction. |
| [64x/14_D_18_72.stl](STL/64x/14_D_18_72.stl) | 1 | 92.5 x 92.5 x 18 | Large wheel on bed; pinion faces rear. Both pivot ends supported. |
| [64x/15_B_rear_spacer.stl](STL/64x/15_B_rear_spacer.stl) | 1 | 12 x 12 x 1.2 | Flat annular face on bed; 1.2 mm long. |
| [64x/16_B_front_spacer.stl](STL/64x/16_B_front_spacer.stl) | 1 | 12 x 12 x 23.7 | Flat annular face on bed; 23.7 mm long. |
| [64x/17_C_rear_spacer.stl](STL/64x/17_C_rear_spacer.stl) | 1 | 12 x 12 x 25.2 | Flat annular face on bed; 25.2 mm long. |
| [64x/27_C_front_spacer.stl](STL/64x/27_C_front_spacer.stl) | 1 | 12 x 12 x 4.7 | Flat annular face on bed; 4.7 mm long. |
| [64x/28_D_rear_spacer.stl](STL/64x/28_D_rear_spacer.stl) | 1 | 12 x 12 x 13.2 | Flat annular face on bed; 13.2 mm long. |
| [64x/29_D_front_spacer.stl](STL/64x/29_D_front_spacer.stl) | 1 | 12 x 12 x 11.7 | Flat annular face on bed; 11.7 mm long. |
| [slow-common/18_anchor_reversed.stl](STL/slow-common/18_anchor_reversed.stl) | 1 | 66.539 x 33.038 x 34 | Pallet faces on bed, sleeve up. Used with 32x or 64x reversed escape wheels. |

## Fit coupons first

- [5.60 mm nut-post coupon - selected production fit](STL/fit-tests/40_nut_post_coupon_560.stl)
- [Matching frame-seat coupon](STL/fit-tests/41_post_seat_coupon.stl)
- Alternative nut seats: [5.25 mm](STL/fit-tests/40_nut_post_coupon_525.stl), [5.40 mm](STL/fit-tests/40_nut_post_coupon_540.stl). All insertion channels are 5.8 mm.

Print at 100% scale in the exported orientation. Do not rescale complete gears to change a fit. All parts must be R3.

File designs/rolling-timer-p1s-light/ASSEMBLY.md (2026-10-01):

# Assembly and first trial - lightweight 16:1

Use the new perspective views in `renders/` and `bowl-bolt-section.png` alongside this guide. Numbers refer to the STL filenames. Z is measured from the rear outside drum face toward the pendulum/front wheel. In the coordinate drawing, X is right and Y is down. The original grid-layout picture and old illustrated guide do not show this frame/post layout.

## 1. Fit and preparation

Print coupon 27 and test pins 28-30, plus square coupon 38 and key 39, before the larger parts. The square fit should slide by hand with little angular play. The stock socket is 8.30 mm across flats around an 8.00 mm chamfered square key. Select a freely turning Ø6 and Ø12 running fit, and a firm removable Ø4 locating fit. The actual gear and anchor bores are Ø6.35; static shaft seats are Ø6.2. Remove any seam ridge on a journal. Smooth thrust faces; preserve the escape-tooth tips and the pallet's curved locking/flat impulse faces.

Print the mechanism before the two case wheels if you want to limit the first trial. Support or clamp the carrier vertically for its bench test, leaving the pendulum and gear faces free. Clamp or support the skeletal carrier without obstructing either gear face. Do not rely on the ballast cup as a bench-test stand.

## 2. Lightweight carrier and two-bolt bowl

1. Hold rear frame 05 with its integral B pivot and main-bearing collar pointing toward the gears. The frame is at Z68-73; the main collar and B-pivot shoulder end at Z77. There is no separate B module.
2. Put two plain M3 nuts into the hex recesses inside bowl 08. Place the bowl behind the rear frame, mouth upward. Its two upper bosses and two lower pads contact the frame. Mount centres are X=-40 and +40, Y=55; the unfastened lower pads are at Y=80.
3. Insert two M3 x10 screws from the gear side through the recessed frame holes and into the nuts. Hold the nuts while starting the threads. Use the intended flat-under-head screws without washers; the nominal stack leaves 0.7 mm of screw past a 2.4 mm nut. Tighten gently. The lower pads resist bowl rocking and require no pins or bolts.
4. Insert C pivot 13 and the longer P pivot 19 from the rear, with their flanges resting on frame 05. Their axes remain C=(-25,-46.77072) and P=(-25,-94.85398). The integral B axis remains (-56.25,0).
5. Insert **three** carrier posts 07 at **(-76,-52), (32,-50), (-26,55)**. Their shoulders span Z73-110. Do not use the old grid-frame post locations. The six longer case posts 02 are a different part.
6. Set front frame 06 aside with its main collar and blind B bearing seat facing the gears. It has no separate front B module or module pins. Omit parts 09, 31, 32 and 33 entirely.

## 3. Main shaft and gear train

The square main shaft's three cross-holes are at **5, 81 and 135 mm from its rear end**. Keep this orientation; it is not symmetric. The square faces transmit torque. The pins provide axial retention, with tangential relief in the wheel and gear hub slots.

1. Slide long rear journal 36 onto main shaft 03. Feed the shaft and sleeve through the rear plate centre bearing. The sleeve, not the square shaft, contacts the round bearing bore. In the final stack it occupies Z10.4-77; its front end is flush with the rear bearing collar at Z77. Hold it there while assembling the next parts.
2. Add thin main thrust washer 35 in front of the rear collar, then drive gear 10, with its taller hub facing forward. Align its transverse hole to the shaft hole at 81 mm and insert crosspin 04. The square socket positively drives the gear; the pin prevents axial sliding. The hub slot deliberately permits a little tangential pin movement so torque is taken by the square faces.
3. Slide keyed main thrust sleeve 34 in front of the drive-gear hub. Together with washer 35 it limits the carrier's axial movement without clamping the bearings.
4. Fit compound B gear 11 onto the integral B pivot of rear frame 05: its 18-tooth pinion faces rearward and meshes with gear 10; its 72-tooth wheel faces forward. Add spacer 15 in front.
5. On C pivot 13, fit rear spacer 16, escape compound 12 with its 18-tooth pinion rearward, then front spacer 17. Mesh C's pinion with B's 72-tooth wheel. The escape wheel faces forward.
6. On P pivot 19, fit rear spacer 20, then anchor 18. The pallet body is in the same axial plane as the escape wheel; its long Ø10 sleeve points forward. Bring the pallets around the escape wheel without levering against tooth tips.
7. Fit the front plate. Its integral blind B seat receives B's pivot, C's pivot enters its static hole, and the anchor sleeve passes through the larger P opening. Seat all three carrier posts. Ensure that neither gear compound is axially squeezed. Slide short front journal 37 along the exposed square shaft and into the front carrier bearing from the front. It occupies Z106-129.6, with its rear end flush with the rear face of the front bearing collar. Both sleeves turn with the shaft in the stationary plates.

### Working axial stack, 16:1

| Axis | Rear to front, millimetres |
|---|---|
| A | Rear journal 36: 10.4-77; washer 35: 77-77.6; drive face 78-84 / hub to 86; thrust sleeve 34: 86.4-105.6; front journal 37: 106-129.6 |
| B | Integral rear boss 73-77; pinion 78-94 (through wheel); large wheel 88-94; spacer 94.6-106; integral front boss 106-110 |
| C | Rear spacer 73-87.4; pinion 88-105 (through wheel); escape wheel 101-105; front spacer 105.6-110 |
| P | Rear spacer 73–100.4; anchor body 101–105; sleeve to 127; front washer 127.6–129; bridge 129–133 |

The small axial gaps are deliberate. Do not add a washer that removes all endplay.

## 4. Pendulum and beat

1. Slide pendulum 24 over the anchor sleeve, ahead of the front plate. Leave its split clamp loose. Install the M3 nut in the hex pocket and the M3×16 screw through the opposing ear if using the recommended clamp screw.
2. Slide open bob 25 onto the rod. Use pin 26 through the **150 mm** rod hole initially. The other settings, from the pivot outward, are 135, 140, 145 and 155 mm. The bob mouth points upward; add roughly 15–20 g of balls or small hardware, spread between its two pockets.
3. Fit washer 21, bridge posts 23 and bridge 22. The bridge supports the front end of P's stationary shaft. Its support-post holes are at **P+(−21,16)** and **P+(21,16)**.
4. With the carrier vertical, apply a very light counterclockwise torque to gear A, viewed from the pendulum/front side, and move the pendulum gently. Adjust the clamp angle so the escape wheel releases once on each half-swing with similar excursions either side of gravity vertical. Tighten only enough to prevent the pendulum slipping on the anchor sleeve.

Beat adjustment changes the pendulum's angle relative to the pallet anchor. Moving the bob changes the rate. Do the beat adjustment again under actual ramp load, because the weighted carrier tilts under drive torque. The checked rod/bob envelope is −25° to +15° relative to the carrier, including the swing; keep the neutral rod within approximately −20° to +10° at a ±5° swing.

## 5. Bench check and drum

First check free gear motion with the anchor lifted clear. Then replace the anchor and verify alternating lock/release under light hand torque. No tooth should drag on the back of a pallet. If the train is stiff, find the tight bore, tooth burr or thrust contact before increasing drive force.

Once the mechanism passes this test, ensure both round journal sleeves are fitted, then slide the rear wheel's square socket onto the shaft and lock it with crosspin 04 at Z5. Insert six case posts 02 into its rim holes. Fit the second wheel facing inward—the hub's taller side faces the mechanism—and secure the shaft crosspin at Z135. The post shoulders sit between the inner wheel faces; the main shaft crosspins retain the two wheels axially. The wheel hubs also capture the extended journal sleeves. Keep the intended small axial gaps; do not force the sleeves against the bearings.

Add about 600 g to the open ballast bucket. Turn the drum through a full revolution by hand while controlling the pendulum. Check that the case posts clear the carrier everywhere, both wheel rims run true, and the bucket and pendulum remain between the case wheels. Carry the assembly with the bucket upright.

## 6. First run

Use a straight, level-across-its-width board with a soft end stop. Start with a 1–2° incline and a small pendulum swing. Increase the slope only enough to maintain motion; use less slope if the escapement knocks or the swing grows excessively. The bucket should hold the carrier near a steady tilted position rather than rotating with the case. Adjust the beat at that operating tilt.

If the rims slide instead of rolling, improve the board's traction; do not add a thick tread without accounting for its change in rolling diameter. Mark a start and finish after a stopwatch trial. At the intended rate, five minutes uses about 628 mm in the 16:1 build. To reset, lift the timer and carry it back uphill rather than forcing the gear train backward.

## Keeping the later upgrade option

This lightweight pair is dedicated to 16:1. The original R2 grid-frame package remains available for the 32:1 development set. All gearing and pendulum parts in this first build retain their R2 positions and geometry, but the lightweight frames do not provide that upgrade's module mounts.

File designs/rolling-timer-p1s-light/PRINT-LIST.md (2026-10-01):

# Print list - lightweight 16:1 variant

Print at 100% scale; dimensions below are millimetres. The files are already oriented on their printing faces. Parts 27-30 and 38-39 are optional fit tests rather than assembly parts.

| File | Qty | Printing envelope | Notes |
|---|---:|---|---|
| 01_case_wheel.stl | 2 | 240 x 240 x 10 | Flat spokes on bed; 240 mm circle. No brim outside the rim. |
| 02_case_post.stl | 6 | 8.5 x 8.5 x 138 | Upright with brim. The two case wheels capture the shoulders. |
| 03_main_shaft.stl | 1 | 8 x 140 x 8 | Lie on a long flat as exported; solid, 4-6 walls. 8 mm square with 1.4 mm corner chamfers. Clear retention holes. |
| 04_main_crosspin.stl | 3 | 6 x 6 x 25.6 | Print upright on its head; brim. Do not force a tight pin. |
| 05_rear_carrier.stl | 1 | 128.3 x 188.854 x 41 | Dedicated light 16:1 frame. Flat outside face on bed. Integral B pivot upward. |
| 06_front_carrier.stl | 1 | 120 x 163.854 x 9 | Dedicated light 16:1 frame. Outside face on bed; bearing bosses and blind B seat upward. |
| 07_carrier_post.stl | 3 | 10 x 10 x 47 | Same post as R2; only three needed. Upright. |
| 08_open_ballast_bucket.stl | 1 | 110 x 60 x 46 | Open mouth upward. Two M3 nut pockets inside the upper front wall; lower pads have no fasteners. |
| 10_drive_72.stl | 1 | 92.5 x 92.5 x 8 | Wheel face flat on bed, hub upward. |
| 11_compound_18_72.stl | 1 | 92.5 x 92.5 x 16 | Large wheel on bed; pinion teeth run through all 16 mm so they start on the bed. Phase is built in. |
| 12_escape_compound.stl | 1 | 67.741 x 67.99 x 17 | Escape wheel on bed; pinion teeth run through all 17 mm. Preserve escape tooth tips. |
| 13_gear_pivot.stl | 1 | 10 x 10 x 49 | Escape shaft only. Upright on flange, brim; solid. Both ends supported. |
| 15_B_front_spacer.stl | 1 | 10 x 10 x 11.4 | Flat annular face on bed. Keep thrust faces smooth. |
| 16_C_rear_spacer.stl | 1 | 10 x 10 x 14.4 | Flat annular face on bed. Keep thrust faces smooth. |
| 17_C_front_spacer.stl | 1 | 10 x 10 x 4.4 | Flat annular face on bed. Keep thrust faces smooth. |
| 18_pallet_anchor.stl | 1 | 66.539 x 32.038 x 26 | Pallet faces flat on bed, sleeve upward. No supports on contact edges. |
| 19_anchor_pivot.stl | 1 | 10 x 10 x 67 | Upright on flange; brim, solid. Supported at rear plate and front bridge. |
| 20_anchor_rear_spacer.stl | 1 | 9 x 9 x 27.4 | Flat annular face on bed. Keep thrust faces smooth. |
| 21_anchor_front_washer.stl | 1 | 9 x 9 x 1.4 | Flat annular face on bed. Keep thrust faces smooth. |
| 22_anchor_bridge.stl | 1 | 50 x 26 x 4 | Flat on bed. |
| 23_bridge_post.stl | 2 | 9 x 9 x 23 | Upright. |
| 24_pendulum.stl | 1 | 26 x 176 x 6 | Rod and clamp on bed; One M3×16 plus nut clamps the beat. |
| 25_open_pendulum_bob.stl | 1 | 34 x 16 x 24 | Open mouth up. Slide over rod; set centre initially to the 150 mm hole. |
| 26_bob_pin.stl | 1 | 5.4 x 5.4 x 17.6 | Print upright on its head; brim. Do not force a tight pin. |
| 27_fit_coupon.stl | 1 | 112 x 42 x 5 | Not an assembly part. Notched corner is lower-left in the fit diagram. |
| 28_fit_test_6mm.stl | 1 | 10 x 10 x 20 | Coupon test shaft; upright. |
| 29_fit_test_12mm.stl | 1 | 16 x 16 x 20 | Coupon test shaft; upright. |
| 30_fit_test_4mm.stl | 1 | 6 x 6 x 16 | Coupon test pin; upright. |
| 34_main_front_thrust_sleeve.stl | 1 | 17.6 x 17.6 x 19.2 | Flat face on bed. Chamfered square bore keys this thrust part to the main shaft. |
| 35_main_rear_thrust_washer.stl | 1 | 19.6 x 19.6 x 0.6 | Flat face on bed. Chamfered square bore keys this thrust part to the main shaft. |
| 36_rear_round_journal.stl | 1 | 12 x 12 x 66.6 | Upright on flat end; brim. OD 12 mm runs in existing 12.4 mm carrier bore. Square socket slides on shaft. |
| 37_front_round_journal.stl | 1 | 12 x 12 x 23.6 | Upright on flat end; brim. OD 12 mm runs in existing 12.4 mm carrier bore. Square socket slides on shaft. |
| 38_square_fit_coupon.stl | 1 | 54 x 20 x 5 | Not an assembly part. Notch at lower-left: 8.20, 8.30, 8.40 mm across flats, left to right. |
| 39_square_fit_key.stl | 1 | 8 x 20 x 8 | Not an assembly part. Same profile and lying-flat orientation as main shaft. |

External hardware: two M3 x10 screws with flat undersides and two plain M3 nuts for the bowl. The existing pendulum clamp can use one M3 x16 screw and another M3 nut. No gear bearings are purchased.

Omit the old bowl pins 09, B modules 31/32 and module pins 33. Use three carrier posts 07; the six drum posts 02 are unchanged.

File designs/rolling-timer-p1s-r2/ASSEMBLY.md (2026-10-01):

# Assembly and first trial - revision 2

Use the new perspective views in `renders/` and `mounting-layout.png` alongside this guide. The previous illustrated PDF shows revision 1; use the square-shaft instructions here for this revision. Numbers refer to STL filenames. All Z measurements below start at the **rear outside face of the drum**, with Z increasing toward the pendulum/front wheel. In the front-view drawing X points right and Y points down.

## 1. Fit and preparation

Print coupon 27 and test pins 28-30, plus square coupon 38 and key 39, before the larger parts. The square fit should slide by hand with little angular play. The stock socket is 8.30 mm across flats around an 8.00 mm chamfered square key. Select a freely turning Ø6 and Ø12 running fit, and a firm removable Ø4 locating fit. The actual gear and anchor bores are Ø6.35; static shaft seats are Ø6.2. Remove any seam ridge on a journal. Smooth thrust faces; preserve the escape-tooth tips and the pallet's curved locking/flat impulse faces.

Print the mechanism before the two case wheels if you want to limit the first trial. Support or clamp the carrier vertically for its bench test, leaving the pendulum and gear faces free. With the modular plates fitted, the frame extends below the ballast bucket; the bucket alone is not a stand.

## 2. Carrier and fixed pivots

1. Hold rear plate 05 with its central bearing collar toward the gear train. The plate occupies Z68–73; the collar ends at Z77.
2. Attach the open ballast bucket 08 behind it using four pins 09. Its 2 mm bosses meet the plate. The mouth points upward. The bucket mounting holes are X±40, Y55 and Y80.
3. Attach B rear module 31 to the inner face using three pins 33, inserted from outside the plate. Use lattice holes **(−80,0), (−60,−40), (−40,−20)**. The integral Ø6 shaft points forward.
4. Insert C pivot 13 and the longer P pivot 19 from the back, with their flanges resting against the rear plate. They should stay fixed in the plate. Their axes are **C=(−25,−46.77072)** and **P=(−25,−94.85398)**.
5. Insert four carrier posts 07 at **(65,−35), (40,−85), (45,65), (−60,65)**. Their shoulders span Z73–110. These are the carrier posts, not the six longer drum posts.
6. On front plate 06, attach B front module 32 to its inner face using three more pins 33 at the same lattice positions. Its blind bearing seat faces rearward, toward the gears. The centre bearing collar also faces rearward.

## 3. Main shaft and gear train

The square main shaft's three cross-holes are at **5, 81 and 135 mm from its rear end**. Keep this orientation; it is not symmetric. The square faces transmit torque. The pins provide axial retention, with tangential relief in the wheel and gear hub slots.

1. Slide long rear journal 36 onto main shaft 03. Feed the shaft and sleeve through the rear plate centre bearing. The sleeve, not the square shaft, contacts the round bearing bore. In the final stack it occupies Z10.4-77; its front end is flush with the rear bearing collar at Z77. Hold it there while assembling the next parts.
2. Add thin main thrust washer 35 in front of the rear collar, then drive gear 10, with its taller hub facing forward. Align its transverse hole to the shaft hole at 81 mm and insert crosspin 04. The square socket positively drives the gear; the pin prevents axial sliding. The hub slot deliberately permits a little tangential pin movement so torque is taken by the square faces.
3. Slide keyed main thrust sleeve 34 in front of the drive-gear hub. Together with washer 35 it limits the carrier's axial movement without clamping the bearings.
4. Fit compound B gear 11 onto the integral pivot of module 31: its 18-tooth pinion faces rearward and meshes with gear 10; its 72-tooth wheel faces forward. Add spacer 15 in front.
5. On C pivot 13, fit rear spacer 16, escape compound 12 with its 18-tooth pinion rearward, then front spacer 17. Mesh C's pinion with B's 72-tooth wheel. The escape wheel faces forward.
6. On P pivot 19, fit rear spacer 20, then anchor 18. The pallet body is in the same axial plane as the escape wheel; its long Ø10 sleeve points forward. Bring the pallets around the escape wheel without levering against tooth tips.
7. Fit the front plate. Its B module receives B's pivot, C's pivot enters its static hole, and the anchor sleeve passes through the larger P opening. Seat all four carrier posts. Ensure that neither gear compound is axially squeezed. Slide short front journal 37 along the exposed square shaft and into the front carrier bearing from the front. It occupies Z106-129.6, with its rear end flush with the rear face of the front bearing collar. Both sleeves turn with the shaft in the stationary plates.

### Working axial stack, 16:1

| Axis | Rear to front, millimetres |
|---|---|
| A | Rear journal 36: 10.4-77; washer 35: 77-77.6; drive face 78-84 / hub to 86; thrust sleeve 34: 86.4-105.6; front journal 37: 106-129.6 |
| B | Rear module 73-77; pinion 78-94 (through wheel); large wheel 88-94; spacer 94.6-106; front module 106-110 |
| C | Rear spacer 73-87.4; pinion 88-105 (through wheel); escape wheel 101-105; front spacer 105.6-110 |
| P | Rear spacer 73–100.4; anchor body 101–105; sleeve to 127; front washer 127.6–129; bridge 129–133 |

The small axial gaps are deliberate. Do not add a washer that removes all endplay.

## 4. Pendulum and beat

1. Slide pendulum 24 over the anchor sleeve, ahead of the front plate. Leave its split clamp loose. Install the M3 nut in the hex pocket and the M3×16 screw through the opposing ear if using the recommended clamp screw.
2. Slide open bob 25 onto the rod. Use pin 26 through the **150 mm** rod hole initially. The other settings, from the pivot outward, are 135, 140, 145 and 155 mm. The bob mouth points upward; add roughly 15–20 g of balls or small hardware, spread between its two pockets.
3. Fit washer 21, bridge posts 23 and bridge 22. The bridge supports the front end of P's stationary shaft. Its support-post holes are at **P+(−21,16)** and **P+(21,16)**.
4. With the carrier vertical, apply a very light counterclockwise torque to gear A, viewed from the pendulum/front side, and move the pendulum gently. Adjust the clamp angle so the escape wheel releases once on each half-swing with similar excursions either side of gravity vertical. Tighten only enough to prevent the pendulum slipping on the anchor sleeve.

Beat adjustment changes the pendulum's angle relative to the pallet anchor. Moving the bob changes the rate. Do the beat adjustment again under actual ramp load, because the weighted carrier tilts under drive torque. The checked rod/bob envelope is −25° to +15° relative to the carrier, including the swing; keep the neutral rod within approximately −20° to +10° at a ±5° swing.

## 5. Bench check and drum

First check free gear motion with the anchor lifted clear. Then replace the anchor and verify alternating lock/release under light hand torque. No tooth should drag on the back of a pallet. If the train is stiff, find the tight bore, tooth burr or thrust contact before increasing drive force.

Once the mechanism passes this test, ensure both round journal sleeves are fitted, then slide the rear wheel's square socket onto the shaft and lock it with crosspin 04 at Z5. Insert six case posts 02 into its rim holes. Fit the second wheel facing inward—the hub's taller side faces the mechanism—and secure the shaft crosspin at Z135. The post shoulders sit between the inner wheel faces; the main shaft crosspins retain the two wheels axially. The wheel hubs also capture the extended journal sleeves. Keep the intended small axial gaps; do not force the sleeves against the bearings.

Add about 600 g to the open ballast bucket. Turn the drum through a full revolution by hand while controlling the pendulum. Check that the case posts clear the carrier everywhere, both wheel rims run true, and the bucket and pendulum remain between the case wheels. Carry the assembly with the bucket upright.

## 6. First run

Use a straight, level-across-its-width board with a soft end stop. Start with a 1–2° incline and a small pendulum swing. Increase the slope only enough to maintain motion; use less slope if the escapement knocks or the swing grows excessively. The bucket should hold the carrier near a steady tilted position rather than rotating with the case. Adjust the beat at that operating tilt.

If the rims slide instead of rolling, improve the board's traction; do not add a thick tread without accounting for its change in rolling diameter. Mark a start and finish after a stopwatch trial. At the intended rate, five minutes uses about 628 mm in the 16:1 build. To reset, lift the timer and carry it back uphill rather than forcing the gear train backward.

## Trying 32:1 later

Read `upgrade-32x/layout-and-checks.json` first. Replace 31, 11, 12, 18, 15, 16 and 17 with the corresponding U parts. Keep the front B module, both carrier plates, C/P pivots, main shaft and thrust parts, drum, ballast and pendulum.

The combined B/D rear module adds two mounts at **(−80,−60)** and **(−40,−60)**; print two additional pins 33. On its Ø8 D pivot fit U10, then U03. Press collar U11 into the recessed front hub of U03 until it is held by the fixed pivot, with its front face flush with the pivot tip at Z99.4. It must clear the spinning counterbore and leave endplay; do not press it against the gear's shoulder. This collar fit is intentionally tight and needs a trial fit before final assembly.

Use U04 **and** U05 together: both escapement parts are mirrored because the output direction reverses. Readjust beat. A successful 32:1 build should nominally halve the travel rate, but it also halves ideal torque at the escapement and adds losses. That is why the first running trial should use 16:1.

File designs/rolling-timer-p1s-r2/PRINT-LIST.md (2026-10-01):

# Print list - revision 2, initial 16:1 build

All dimensions in millimetres. Files are already oriented for printing. Parts 27-30 and 38-39 are fit tests, not assembly components. Part numbers intentionally skip 14.

| File stem | Quantity | Printing envelope | Notes |
|---|---:|---|---|
| 01_case_wheel | 2 | 240 x 240 x 10 | Flat spokes on bed; 240 mm circle. No brim outside the rim. |
| 02_case_post | 6 | 8.5 x 8.5 x 138 | Upright with brim. The two case wheels capture the shoulders. |
| 03_main_shaft | 1 | 8 x 140 x 8 | Lie on a long flat as exported; solid, 4-6 walls. 8 mm square with 1.4 mm corner chamfers. Clear retention holes. |
| 04_main_crosspin | 3 | 6 x 6 x 25.6 | Print upright on its head; brim. Do not force a tight pin. |
| 05_rear_carrier | 1 | 216 x 216 x 9 | Reusable mounting grid. Flat plate on bed, bearing collar upward. |
| 06_front_carrier | 1 | 216 x 216 x 9 | Reusable mounting grid. Flat plate on bed, bearing collar upward. |
| 07_carrier_post | 4 | 10 x 10 x 47 | Upright. Select static press fit using coupon. |
| 08_open_ballast_bucket | 1 | 110 x 60 x 46 | Open mouth upward in print and use. No lid. 2.4 mm walls. |
| 09_bucket_pin | 4 | 7.2 x 7.2 x 11 | Print upright on its head; brim. Do not force a tight pin. |
| 10_drive_72 | 1 | 92.5 x 92.5 x 8 | Wheel face flat on bed, hub upward. |
| 11_compound_18_72 | 1 | 92.5 x 92.5 x 16 | Large wheel on bed; pinion teeth run through all 16 mm so they start on the bed. Phase is built in. |
| 12_escape_compound | 1 | 67.741 x 67.99 x 17 | Escape wheel on bed; pinion teeth run through all 17 mm. Preserve escape tooth tips. |
| 13_gear_pivot | 1 | 10 x 10 x 49 | Escape shaft only. Upright on flange, brim; solid. Both ends supported. |
| 15_B_front_spacer | 1 | 10 x 10 x 11.4 | Flat annular face on bed. Keep thrust faces smooth. |
| 16_C_rear_spacer | 1 | 10 x 10 x 14.4 | Flat annular face on bed. Keep thrust faces smooth. |
| 17_C_front_spacer | 1 | 10 x 10 x 4.4 | Flat annular face on bed. Keep thrust faces smooth. |
| 18_pallet_anchor | 1 | 66.539 x 32.038 x 26 | Pallet faces flat on bed, sleeve upward. No supports on contact edges. |
| 19_anchor_pivot | 1 | 10 x 10 x 67 | Upright on flange; brim, solid. Supported at rear plate and front bridge. |
| 20_anchor_rear_spacer | 1 | 9 x 9 x 27.4 | Flat annular face on bed. Keep thrust faces smooth. |
| 21_anchor_front_washer | 1 | 9 x 9 x 1.4 | Flat annular face on bed. Keep thrust faces smooth. |
| 22_anchor_bridge | 1 | 50 x 26 x 4 | Flat on bed. |
| 23_bridge_post | 2 | 9 x 9 x 23 | Upright. |
| 24_pendulum | 1 | 26 x 176 x 6 | Rod and clamp on bed; One M3×16 plus nut clamps the beat. |
| 25_open_pendulum_bob | 1 | 34 x 16 x 24 | Open mouth up. Slide over rod; set centre initially to the 150 mm hole. |
| 26_bob_pin | 1 | 5.4 x 5.4 x 17.6 | Print upright on its head; brim. Do not force a tight pin. |
| 27_fit_coupon | 1 | 112 x 42 x 5 | Not an assembly part. Notched corner is lower-left in the fit diagram. |
| 28_fit_test_6mm | 1 | 10 x 10 x 20 | Coupon test shaft; upright. |
| 29_fit_test_12mm | 1 | 16 x 16 x 20 | Coupon test shaft; upright. |
| 30_fit_test_4mm | 1 | 6 x 6 x 16 | Coupon test pin; upright. |
| 31_B_rear_pivot_module | 1 | 51 x 52 x 36 | Flat module on bed, integral pivot upward. Mounts to three grid holes. |
| 32_B_front_pivot_module | 1 | 51 x 52 x 4 | Closed face on bed, blind bearing seat upward. Matching three grid holes. |
| 33_module_pin | 6 | 7.2 x 7.2 x 10.6 | Print upright on its head; brim. Do not force a tight pin. |
| 34_main_front_thrust_sleeve | 1 | 17.6 x 17.6 x 19.2 | Flat face on bed. Chamfered square bore keys this thrust part to the main shaft. |
| 35_main_rear_thrust_washer | 1 | 19.6 x 19.6 x 0.6 | Flat face on bed. Chamfered square bore keys this thrust part to the main shaft. |
| 36_rear_round_journal | 1 | 12 x 12 x 66.6 | Upright on flat end; brim. OD 12 mm runs in existing 12.4 mm carrier bore. Square socket slides on shaft. |
| 37_front_round_journal | 1 | 12 x 12 x 23.6 | Upright on flat end; brim. OD 12 mm runs in existing 12.4 mm carrier bore. Square socket slides on shaft. |
| 38_square_fit_coupon | 1 | 54 x 20 x 5 | Not an assembly part. Notch at lower-left: 8.20, 8.30, 8.40 mm across flats, left to right. |
| 39_square_fit_key | 1 | 8 x 20 x 8 | Not an assembly part. Same profile and lying-flat orientation as main shaft. |

CAD solid volume including test pieces: 513 cm3. This is geometry volume; use your slicer for actual filament consumption.

The main shaft is now printed lying on its long flat. Journals 36 and 37 print upright. Keep support material off all gear teeth and bearing surfaces. Also required: ballast, ramp/end stop, and preferably an M3 x16 screw and nut for the pendulum clamp.

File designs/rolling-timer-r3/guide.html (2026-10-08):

# Build the bolted rolling clock

R3: shared frames for 16:1, 32:1 and 64:1. The builder reports corrected R3 rolls well. The refined 1,536-segment rolling rim still needs a physical test.

Open the complete 17-page illustrated build guide

Print the 1:1 main-axle identification sheet (also page 6 of the guide). A4 landscape, 100% / Actual size, with Fit / Shrink disabled. Check the 50 mm bar.

Spacer order and wheel direction drawings: 16x / 32x / 64x (guide pages 7-9). Each sheet shows the pivot map, spacer lengths and front/rear orientation, including the anchor.

Smoother rolling rim: wheel 01 now has 1,536 outer segments instead of 192, retaining its dimensions and mounting features. Try slicer Resolution 0.001 mm and Arc fitting on. Only wheel 01 changes; print two copies to replace both drum wheels.

Rear thrust correction: print one new 38_rear_journal_thrust_collar.stl. Its 12.4 mm round bore surrounds journal 36; its 6 mm length fills the gap between rear-frame collar 05 and washer 35. Existing corrected prints can be reused.

Pivot correction: 10.5 mm pivot feet, 54 mm frame posts, 186 mm axle and 76 mm rear journal. Existing R3 gears, frames, anchor bridge and bridge posts remain compatible.

Print lists: 16x / 32x / 64x. Begin with the nut-post and seat coupons, then the 16x mechanism. Full design notes.

Assembled R3 clock

## Captive-nut posts

Square post and metal screw and nut

## Screw-fixed bob

Thin-wall bob with screw and nut

## Same frames, slower gearing

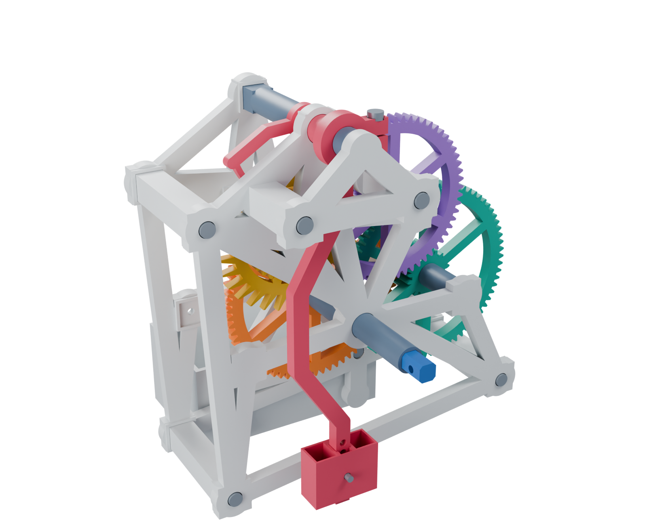
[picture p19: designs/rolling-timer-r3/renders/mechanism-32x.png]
32 to 1 mechanism
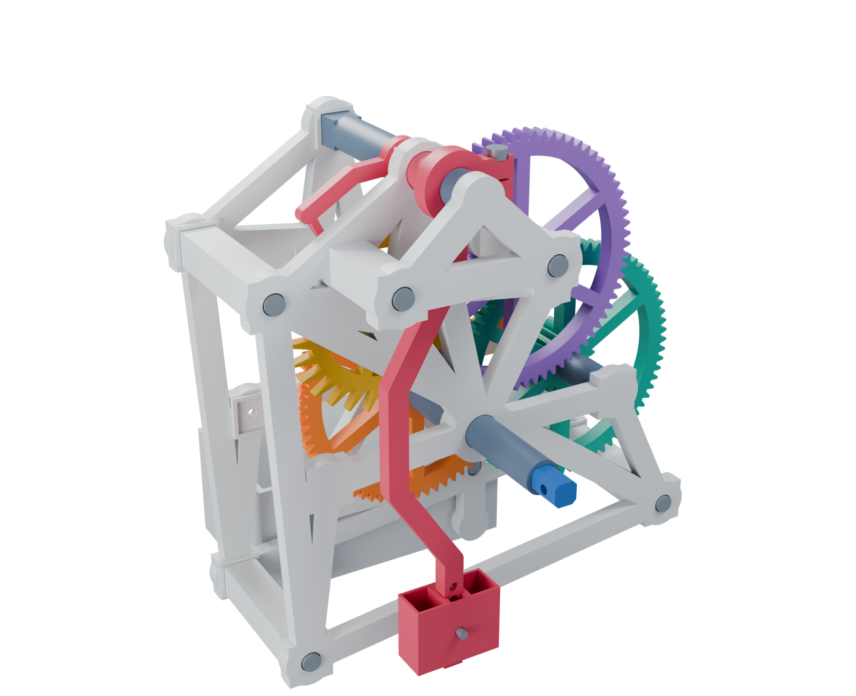
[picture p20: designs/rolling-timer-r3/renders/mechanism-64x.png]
64 to 1 mechanism


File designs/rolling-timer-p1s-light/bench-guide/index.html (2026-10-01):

LIGHT 16:1 / YOUR PRINTED BENCH KIT

# Assemble the gear train, escapement and pendulum

28 printed pieces from 25 STL files, one M3 x16 screw and one M3 nut. Download the illustrated PDF for numbered callouts, diagrams and the spacer reference.

Front is the pendulum side. Rear is the side with the heads of pivots 13 and 19. Remove brims and obvious shaft burrs; preserve tooth tips and pallet faces.

## 01. Build the rear support



Looking from the gear / pendulum side. B is already printed into frame 05.

- 05_rear_carrier.stl
- 07_carrier_post.stl x3
- 13_gear_pivot.stl
- 19_anchor_pivot.stl
1. Hold rear frame 05 with its long built-in B pin pointing toward you. The two small bowl screw holes are at the bottom; leave them empty.
2. Insert short pivot 13 through hole C and long pivot 19 through the top hole P, both from behind. Their flat heads stay behind frame 05.
3. Insert the three posts 07 into the three small corner holes shown. Their thick shoulders sit against the gear-side face of 05.

Check: 13 is 49 mm overall; 19 is 67 mm. Use all three 47 mm carrier posts. Set front frame 06 aside.

## 02. Fit the square shaft and rear sleeve



The long round sleeve passes through the rear frame bearing.

- 03_main_shaft.stl
- 36_rear_round_journal.stl
1. Identify the rear end of shaft 03: the middle cross-hole is 81 mm from it, and 59 mm from the other end. Mark the rear end temporarily.
2. Slide long round sleeve 36 onto the square shaft. Feed the sleeved shaft through the large A hole of frame 05 from behind.
3. Set the front end of sleeve 36 flush with the front face of the raised collar on 05. Hold it there while adding the next parts.

Shaft holes from rear end: 5 mm, 81 mm, 135 mm. Overall length: 140 mm.

Check: the 66.6 mm sleeve provides the round bearing surface. The bare square shaft should not rub directly in the frame hole.

## 03. Add the orange input gear



Exploded detail: parts are spread apart along the shaft. Frame omitted here.

- 35_main_rear_thrust_washer.stl
- 10_drive_72.stl
- 04_main_crosspin.stl
- 34_main_front_thrust_sleeve.stl
1. From the front, slide thin washer 35 onto the square shaft, against the rear collar. This is the very thin 0.6 mm washer.
2. Slide drive gear 10 on with its taller central hub facing forward. Align its cross-slot with the shaft hole 81 mm from the rear end.
3. Push crosspin 04 through the hub and shaft. Then add the larger keyed sleeve 34 in front of the gear. Its length is 19.2 mm.

Rear to front: 05 rear collar → 35 0.6 mm washer → 10 + 04 gear + pin → 34 19.2 mm sleeve

Check: gear 10 and shaft 03 turn together. The square socket transmits torque; a little tangential play in the retaining pin slot is intentional.

## 04. Fit the green compound gear



The green wheel sits farther forward than the orange wheel.

- 11_compound_18_72.stl
- 15_B_front_spacer.stl
1. Slide compound gear 11 onto the built-in B pivot of rear frame 05.
2. Point its projecting small pinion toward the rear frame. Its large 72-tooth wheel faces forward. The small pinion meshes with orange gear 10.
3. Slide spacer 15, length 11.4 mm, onto the B pivot in front of gear 11.

Rear to front: 05 / B integral pivot → 11 pinion rearward → 15 11.4 mm spacer

Check: turn the gears gently while supporting the loose shafts. The large green wheel should clear the orange wheel rather than mesh with it.

## 05. Fit the yellow escape compound



The yellow small pinion engages the large green wheel.

- 16_C_rear_spacer.stl
- 12_escape_compound.stl
- 17_C_front_spacer.stl
1. On pivot 13 at C, slide on rear spacer 16, length 14.4 mm. It rests against frame 05.
2. Add escape compound 12: its projecting small pinion points rearward, and its large pointed escape wheel faces forward. Turn gently to engage the green wheel.
3. Add front spacer 17, length 4.4 mm. Before fitting the anchor, check that both gear meshes turn without a hard spot.

Rear to front: 05 rear frame → 16 14.4 mm → 12 pinion rearward → 17 4.4 mm

Check: 16 is the long spacer behind the yellow gear; 17 is the short spacer in front. Do not press on the pointed tooth tips.

## 06. Place the pallet anchor

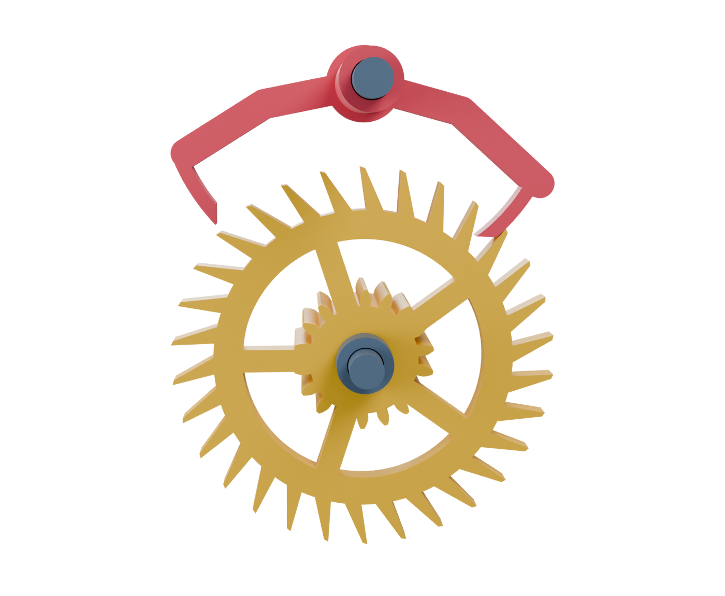
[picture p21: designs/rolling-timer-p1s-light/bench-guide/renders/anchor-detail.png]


Isolated escapement detail. Rear frame and other gears omitted for clarity.

- 20_anchor_rear_spacer.stl
- 18_pallet_anchor.stl
1. On long top pivot 19, slide rear spacer 20 against frame 05. This narrow spacer is 27.4 mm long.
2. Slide anchor 18 onto that pivot with its two pallet arms pointing down toward the escape wheel. Its long round sleeve points forward.
3. Ease the pallets around the upper teeth of wheel 12, rotating the wheel a little if necessary. The pallet faces and escape wheel occupy the same front-to-back plane.

Rear to front: 05 rear frame → 20 27.4 mm spacer → 18 arms at wheel → sleeve points forward

Check: the anchor pivots freely on 19. Preserve the little working faces and tooth tips; do not force the wheel past a locked pallet.

## 07. Close the two frames



Front frame and front sleeve are shown pulled forward before seating.

- 06_front_carrier.stl
- 37_front_round_journal.stl
1. Orient front frame 06 with its raised main collar and blind B bearing seat facing rearward, toward the gears.
2. Bring it onto all three posts 07. Guide B's built-in pin into its blind seat, C pivot 13 into its hole, and the anchor's round sleeve through the large top opening.
3. Seat the frame gently. Slide short round sleeve 37 over the front of the square shaft and into the A bearing. Its rear end should be flush with the rear face of the front frame collar.

Check: sleeves 36 and 37 turn with the shaft. Keep a little axial play in the gears. If closure makes anything stiff, reopen and check the spacer order.

## 08. Clamp the pendulum to the anchor



Close-up of the anchor sleeve and split pendulum clamp. Rod continues below.

- 24_pendulum.stl
1. Slide the split clamp of pendulum 24 over the anchor's protruding round sleeve, ahead of front frame 06. The rod points downward.
2. Place one plain M3 nut in the hexagonal recess of the clamp ear. Insert an M3 x16 screw through the opposite ear and start it into the nut.
3. Set the front face of the clamp approximately flush with the end of the anchor sleeve. Tighten only enough to hold it provisionally; you will adjust its angle during the test.

Check: the pendulum clamps to the rotating anchor sleeve, not to the stationary 6 mm pivot. Keep the clamp clear of frame 06.

## 09. Fit the open bob



Rear close-up of the bob; its pin is pulled back before insertion.

- 25_open_pendulum_bob.stl
- 26_bob_pin.stl
1. Slide open bob 25 onto the bottom of the pendulum rod with its two open pockets facing upward.
2. Align its hole with the 150 mm rod hole: the fourth hole from the pivot, or the second hole from the free end.
3. Insert bob pin 26. Keep the bob empty until the assembled frame is supported upright; then put 15-20 g total of iron into its two pockets.

Holes from pivot: 135, 140, 145, 150, 155 mm. Use the second hole from the free end.

Check: the bob pin passes through the rod and bob. Split the iron approximately evenly between the two pockets; this is the only ballast used in this bench test.

## 10. Support the front of the anchor pivot



Exploded close-up: washer, two bridge posts and bridge are pulled forward.

- 21_anchor_front_washer.stl
- 23_bridge_post.stl x2
- 22_anchor_bridge.stl
1. Slide thin washer 21, thickness 1.4 mm, over the exposed end of pivot 19, just in front of the pendulum clamp and anchor sleeve.
2. Fit both short bridge posts 23 into the two small holes beside the top of front frame 06. Each post is 23 mm overall.
3. Fit bridge 22 onto the posts while guiding pivot 19 into its central hole. Seat all three locations together without bending the pivot.

Rear to front: 18 + 24 sleeve + clamp → 21 1.4 mm washer → 22 front bridge

Check: the anchor pivot is now supported at both ends. The anchor and pendulum must turn freely with slight endplay; the bridge must not squeeze the clamp.

## 11. Support and test



1. Support the fixed frame upright with a padded clamp or blocks, leaving the pendulum and both gear faces free. Avoid squeezing the bearing areas.
2. Without drum wheels, sleeves 36 and 37 can slide outward. Keep them seated. Small removable tape collars on the exposed shaft just outside their outer ends can retain them; keep tape away from the frame bearings.
3. Add 15-20 g to the bob. Apply very light counterclockwise torque to orange gear 10, viewed from the pendulum side. Move the pendulum gently, initially about 5 degrees each side.
4. Look for release, then a definite stop on the opposite pallet on each half-swing. Adjust the pendulum clamp angle until release occurs at similar excursions either side of vertical; retighten lightly.

From the pendulum side: orange and yellow turn counterclockwise, green clockwise. This corrects the earlier clockwise instruction for this front view. Stop if it binds or skips; inspect before adding force.

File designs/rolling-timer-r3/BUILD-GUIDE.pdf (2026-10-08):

R3 / FIRST ASSEMBLY

# Build the bolted rolling clock

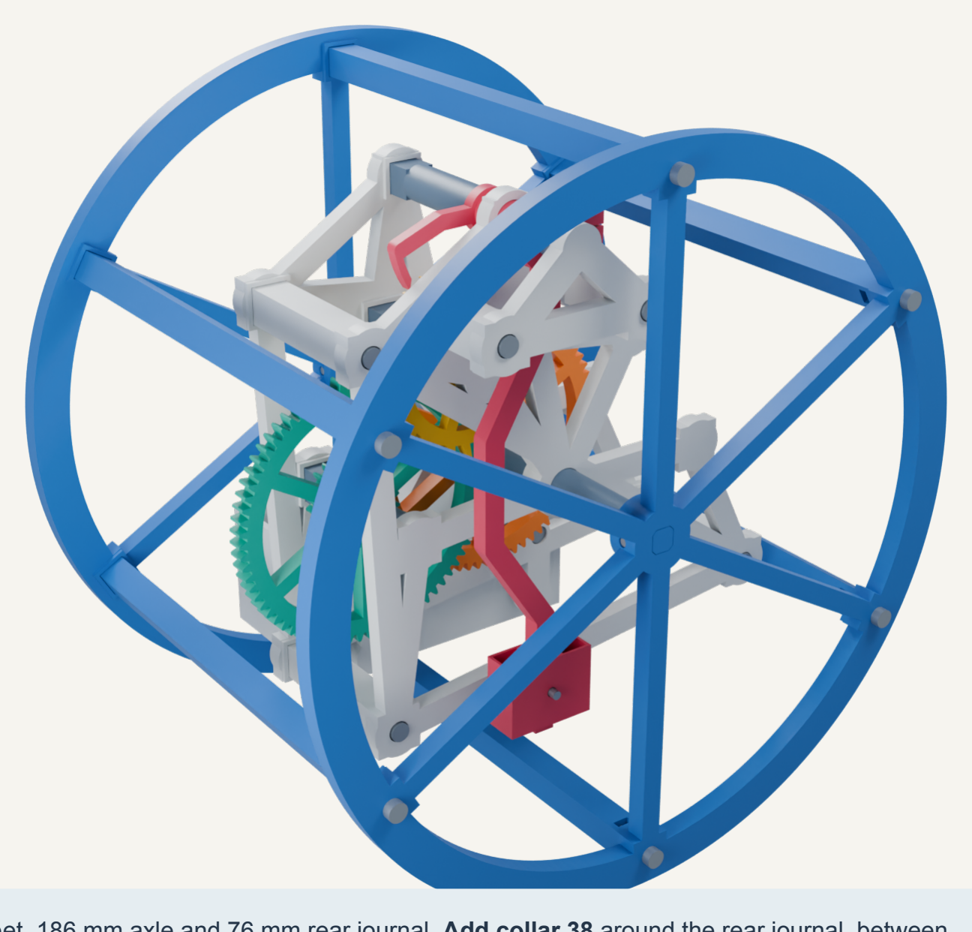
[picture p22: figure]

ROLLING CLOCK R3 | 248 mm drum | PLA / 0.4 mm nozzle / 0.2 mm layers | 1 / 17

Solid pivot roots, a rigid frame, and three gear ratios.

Start with 16:1.
The same frames also accept 32:1 and 64:1. This guide shows the complete assembly, the captive-nut joints and the parts to change for slower rolling.

Status, 8 October: the builder reports that corrected R3 prints and rolls well. The new 1,536-segment wheel rim still needs a print; timing and every ratio are not yet verified.

Current corrected stack: 54 mm frame posts, 10.5 mm pivot feet, 186 mm axle and 76 mm rear journal. Add collar 38 around the rear journal, between frame 05 and washer 35. This missing 6 mm thrust collar is one extra print; existing corrected parts remain compatible.

01 / MATERIALS AND SMALL COUPONS

# Check the nut fit before the large prints

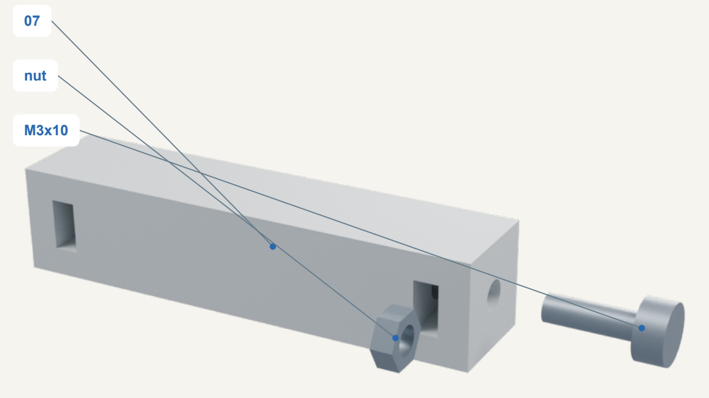
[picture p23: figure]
nut

ROLLING CLOCK R3 | 248 mm drum | PLA / 0.4 mm nozzle / 0.2 mm layers | 2 / 17

Selected by the builder after printing: the 5.6 mm seat. To confirm on another setup, print 40_nut_post_coupon_560 and 41_post_seat_coupon from STL/fit-tests/.

Slide a real M3 nut through the 5.8 mm entry channel and its taper into the 5.6 mm seat. Align the thread with the screw axis. The post must slip into the 12.4 mm locating lip.

Use one M3x10 screw through the seat coupon. Tighten until the flat faces meet. The 5.25 and 5.40 mm comparison coupons remain available; do not scale complete parts to change a fit.

16x: 15 M3x10, 17 M3x16, 32 nuts.
32x / 64x: 16 M3x10, 17 M3x16, 33 nuts.

Square posts print on a long flat side, with nut slots facing upward. Preload both end nuts before assembly. Screw heads: flat underside, at most 6.5 mm diameter x 3.2 mm high. Plain nuts: about 2.4 mm thick.

02 / SHAFT POSITIONS SEEN FROM THE PENDULUM SIDE

# One pair of frames, three layouts

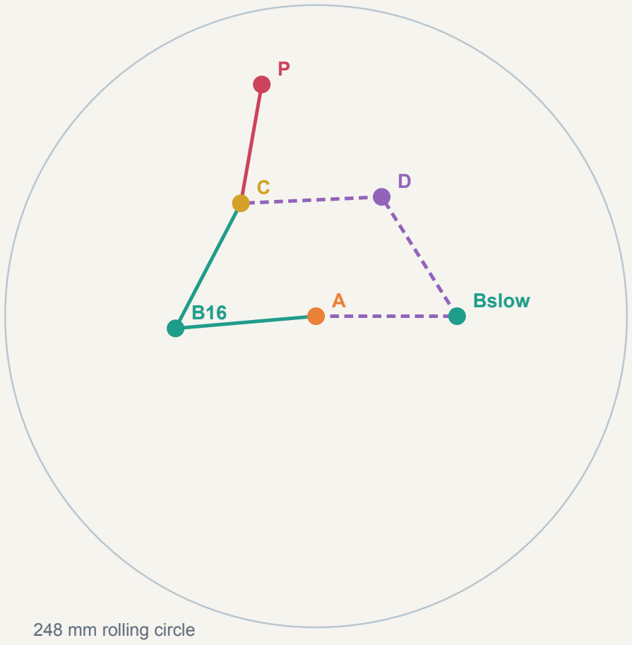
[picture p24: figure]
Bslow; 248 mm rolling circle

ROLLING CLOCK R3 | 248 mm drum | PLA / 0.4 mm nozzle / 0.2 mm layers | 3 / 17

A is the square rolling axle. C is the escape-wheel pivot. P is the long anchor pivot. These stay fixed for every ratio.

16x: fit one short pivot at B16 and one at C. Leave Bslow and D empty.

32x or 64x: fit short pivots at Bslow, D and C. Leave B16 empty. Both slower layouts use the same shaft positions.

Each pivot foot sits inside its loose square locating lip on rear frame 05. The front frame has matching blind seats for the gear-pivot tips. The large top opening passes the anchor sleeve.

The extra holes are deliberate. Install only the pivots for your chosen ratio. Match the frame to this view before tightening; unused seats require no plugs or screws.

03 / BEGIN THE 16X MECHANISM

# Bolt the rear frame and pivot feet

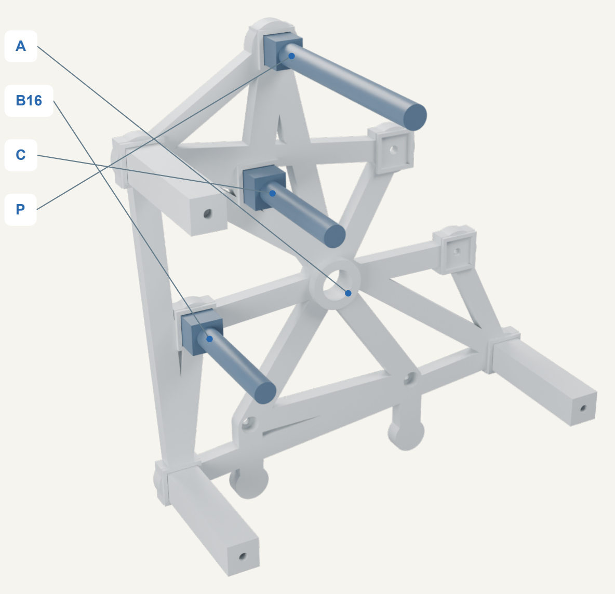
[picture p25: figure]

ROLLING CLOCK R3 | 248 mm drum | PLA / 0.4 mm nozzle / 0.2 mm layers | 4 / 17

### 1. Lay 05 with its collars and locating lips facing you. The

ballast-bowl bracket is at the bottom.

### 2. Preload the nuts. Seat the two 13 gear pivots at B16

and C, and the long 19 pivot at P. Fasten each from behind with M3x10.

### 3. Fit the three 07 square frame posts inside their locating

lips. Use one M3x10 from behind for each post; leave the front nuts loaded.

### 4. Use the corrected pivots with 10.5 mm feet and solid

shaft roots. Bring their flat shoulders into contact with the frame before tightening.

The front frame is 54 mm from the rear frame's inside face. Reprint the three old 48 mm posts. Each nut pocket is fully below the shaft, with 4.8 mm of material above it. Print both pivot types solid.

04 / REPLACE ALL CROSSPINS WITH SCREWS

# Fit the square axle and orange gear

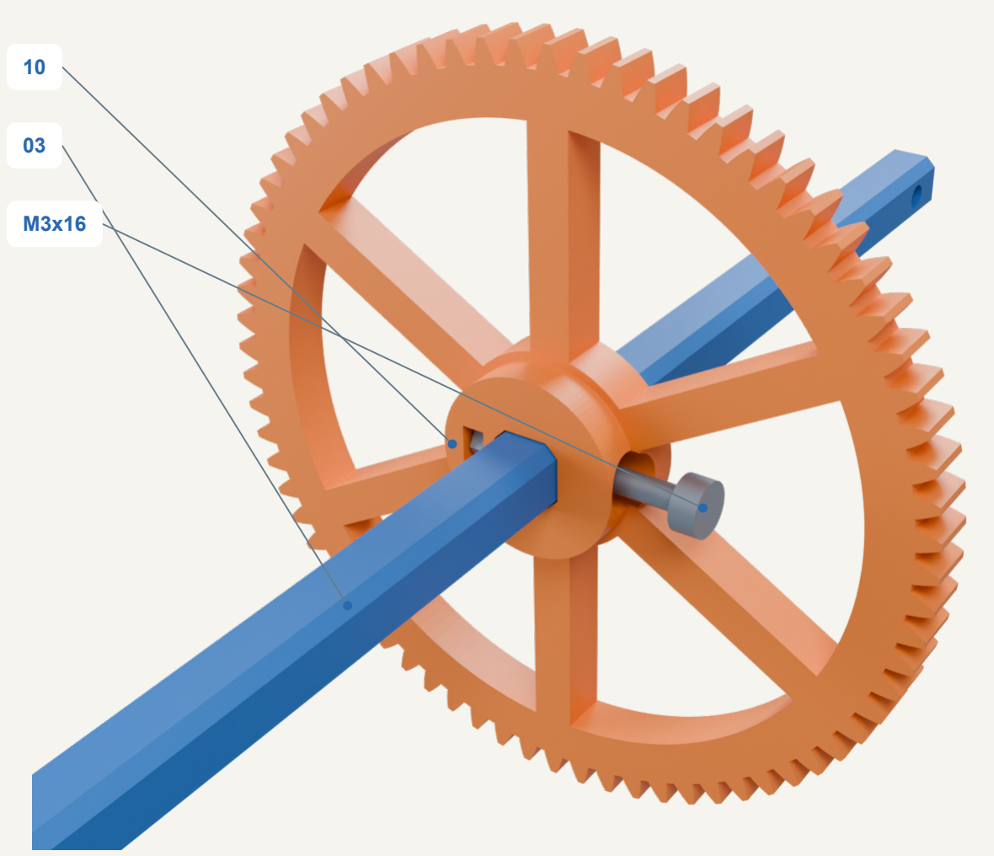
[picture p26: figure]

ROLLING CLOCK R3 | 248 mm drum | PLA / 0.4 mm nozzle / 0.2 mm layers | 5 / 17

### 1. Use the corrected 186 mm axle 03. Mark the rear end:

the middle cross-hole is 97 mm from it (89 mm from the other). End holes are 6 mm from each end.

2. Slide journal 36 (76 mm) through A. Fit 38 (6 mm, round bore) around its protruding end, then 35 (1.2 mm, square bore) onto the axle. Collar 38 fills the gap to the rear frame.

### 3. Slide on 10: its flat face points rearward; the raised

hub points toward the short, 89 mm end / pendulum. Load the hub nut, align the middle hole and fit M3x16 in the side recess.

### 4. Add keyed front thrust sleeve 34 (26.4 mm) ahead of

the orange hub. The square faces carry torque; the cross-screw holds the gear in position.

Next page: 1:1 drawing. Journal 36 runs inside collar 38. Rear thrust path: frame 05 -> collar 38 -> washer 35 -> gear 10. Forward of gear 10: sleeve 34 -> frame / journal 37 -> front wheel hub. Keep the small clearances; do not clamp the stack tight.

04 / AXLE IDENTIFICATION AT ACTUAL SIZE

# Main axle: rear, front and gear orientation

Corrected R3 • 54 mm frame posts • 186 mm axle • identical for 16x / 32x / 64x

REAR — main ballast bowl side | FRONT — pendulum side

CHECK THE ASSEMBLY

Long side of the middle hole: REAR (97 mm).

Fix gear 10 at this middle hole with one M3x16 screw + nut.

38 surrounds rear journal 36. It fits between frame 05
and rear thrust washer 35. Parts are in their assembled positions. Small gaps are
intentional; do not clamp tight.

Rear frame collar shown in section. Other frame parts / drum omitted.

Lay the bare axle on the outline below to identify its three holes.

97 mm to middle hole; 89 mm to middle hole; 36 Rear journal; 76 mm long; 37 Front journal; 45.6 mm long; 35 / 1.2 mm washer; 05 Rear-frame collar; 38 NEW rear thrust collar; 6 mm long / Ø12.4 mm ROUND bore; 34 Front thrust sleeve; 26.4 mm long; Flat face toward REAR; Raised hub → FRONT; 10 Fixed orange wheel; 72 teeth • hub on the right

BARE AXLE 03 • 8 mm square • Ø3.4 mm cross-holes

Hole labels are measured from the REAR end. Both end holes are 6 mm from their nearest end.

This bar must measure 50 mm

Print A4 landscape at 100% / Actual size. Disable Fit / Shrink. Check the bar first.

ROLLING CLOCK R3 | TRUE 1:1 VECTOR DRAWING | 8 OCTOBER 2026 | 6 / 17

05 / RATIO-SPECIFIC ASSEMBLY REFERENCE

# 16:1 - spacer order and wheel orientation

Side diagrams show the assembled order. Axial positions come from CAD; diameters are compressed. Not 1:1.

PIVOT MAP | REAR / ballast bowl side | FRONT / pendulum side

Seen from the front

A

B16

Bslow

C D

P

B uses B16.
Gear files: STL/16x/

Spacer label: part / length.

Anchor file:
STL/16x/

18_anchor_forward.stl

Pinions always face REAR.
Anchor sleeve faces FRONT.

13 = short gear pivot
19 = long anchor pivot

Rear spacers sit against the pivot foot, ahead of frame 05.

B

05 06

13 foot

15 / 1.2 mm | 16 / 23.7 mm

11

11_B_18_72.stl
18T pinion toward REAR
72T wheel toward FRONT

15 (1.2) > 11 > 16 (23.7) > front frame 06

C

05 06

13 foot

17 / 13.2 mm | 27 / 4.7 mm
| 12

12_escape_compound.stl
18T pinion toward REAR
30T escape teeth toward FRONT

17 (13.2) > 12 > 27 (4.7) > front frame 06

P

05

06

22

19 foot

20 / 34.2 mm | 21 / 7.7 mm
18 24

long sleeve

Bridge
22

20 (34.2) > 18 [sleeve forward] > 21 (7.7) > bridge 22

P: sleeve 18 passes through frame 06; clamp 24 surrounds its front end. Spacer 21 goes beyond both.

One of each spacer shown. Use common/ for 20 and 21. Main axle A and its sleeves: guide page 6 / AXLE-1-TO-1.pdf.

Corrected 54 mm frame posts. Nominal gear endplay: 0.6 mm total. Do not squeeze rotating parts between fixed faces.

ROLLING CLOCK R3 | 16:1 PIVOT STACKS | NUMBERS = STL FILE PREFIXES | 7 / 17

05 / RATIO-SPECIFIC ASSEMBLY REFERENCE

# 32:1 - spacer order and wheel orientation

Side diagrams show the assembled order. Axial positions come from CAD; diameters are compressed. Not 1:1.

PIVOT MAP | REAR / ballast bowl side | FRONT / pendulum side

Seen from the front

A

B16

Bslow

C D

P

B uses Bslow.
Gear files: STL/32x/

Spacer label: part / length.

Anchor file:
STL/slow-common/

18_anchor_reversed.stl

Pinions always face REAR.
Anchor sleeve faces FRONT.

13 = short gear pivot
19 = long anchor pivot

Rear spacers sit against the pivot foot, ahead of frame 05.

B

05 06

13 foot

15 / 1.2 mm | 16 / 23.7 mm

11

11_B_18_72.stl
18T pinion toward REAR
72T wheel toward FRONT

15 (1.2) > 11 > 16 (23.7) > front frame 06

D

05 06

13 foot

28 / 13.2 mm | 29 / 11.7 mm

14

14_D_18_60.stl
18T pinion toward REAR
60T wheel toward FRONT

28 (13.2) > 14 > 29 (11.7) > front frame 06

C

05 06

13 foot

17 / 25.2 mm | 27 / 4.7 mm
| 12

12_escape_compound.stl
30T pinion toward REAR
30T escape teeth toward FRONT

17 (25.2) > 12 > 27 (4.7) > front frame 06

P

05

06

22

19 foot

20 / 34.2 mm | 21 / 7.7 mm
18 24

long sleeve

Bridge
22

20 (34.2) > 18 [sleeve forward] > 21 (7.7) > bridge 22

P: sleeve 18 passes through frame 06; clamp 24 surrounds its front end. Spacer 21 goes beyond both.

One of each spacer shown. Use common/ for 20 and 21. Main axle A and its sleeves: guide page 6 / AXLE-1-TO-1.pdf.

Corrected 54 mm frame posts. Nominal gear endplay: 0.6 mm total. Do not squeeze rotating parts between fixed faces.

ROLLING CLOCK R3 | 32:1 PIVOT STACKS | NUMBERS = STL FILE PREFIXES | 8 / 17

05 / RATIO-SPECIFIC ASSEMBLY REFERENCE

# 64:1 - spacer order and wheel orientation

Side diagrams show the assembled order. Axial positions come from CAD; diameters are compressed. Not 1:1.

PIVOT MAP | REAR / ballast bowl side | FRONT / pendulum side

Seen from the front

A

B16

Bslow

C D

P

B uses Bslow.
Gear files: STL/64x/

Spacer label: part / length.

Anchor file:
STL/slow-common/

18_anchor_reversed.stl

Pinions always face REAR.
Anchor sleeve faces FRONT.

13 = short gear pivot
19 = long anchor pivot

Rear spacers sit against the pivot foot, ahead of frame 05.

B

05 06

13 foot

15 / 1.2 mm | 16 / 23.7 mm

11

11_B_18_72.stl
18T pinion toward REAR
72T wheel toward FRONT

15 (1.2) > 11 > 16 (23.7) > front frame 06

D

05 06

13 foot

28 / 13.2 mm | 29 / 11.7 mm

14

14_D_18_72.stl
18T pinion toward REAR
72T wheel toward FRONT

28 (13.2) > 14 > 29 (11.7) > front frame 06

C

05 06

13 foot

17 / 25.2 mm | 27 / 4.7 mm
| 12

12_escape_compound.stl
18T pinion toward REAR
30T escape teeth toward FRONT

17 (25.2) > 12 > 27 (4.7) > front frame 06

P

05

06

22

19 foot

20 / 34.2 mm | 21 / 7.7 mm
18 24

long sleeve

Bridge
22

20 (34.2) > 18 [sleeve forward] > 21 (7.7) > bridge 22

P: sleeve 18 passes through frame 06; clamp 24 surrounds its front end. Spacer 21 goes beyond both.

One of each spacer shown. Use common/ for 20 and 21. Main axle A and its sleeves: guide page 6 / AXLE-1-TO-1.pdf.

Corrected 54 mm frame posts. Nominal gear endplay: 0.6 mm total. Do not squeeze rotating parts between fixed faces.

ROLLING CLOCK R3 | 64:1 PIVOT STACKS | NUMBERS = STL FILE PREFIXES | 9 / 17

05 / 16X PARTS ONLY

# Build the two gear stages

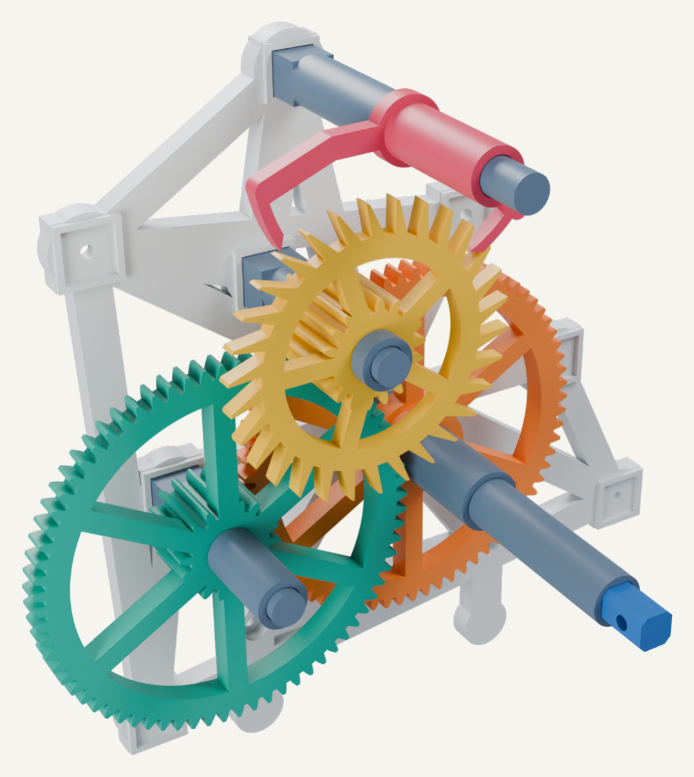
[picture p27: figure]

ROLLING CLOCK R3 | 248 mm drum | PLA / 0.4 mm nozzle / 0.2 mm layers | 10 / 17

### 1. On the B16 pivot: add 15 (1.2 mm), then green 11 with

its small pinion rearward, then 16 (23.7 mm). The small pinion engages the orange wheel.

### 2. On C: add 17 (13.2 mm), then yellow 12 with its small

pinion rearward, then 27 (4.7 mm). Its small pinion engages the large green wheel.

### 3. On P: add 20 (34.2 mm), then the 18_anchor_forward

from STL/16x/. Its long sleeve points forward. Ease the pallet faces around the escape-wheel teeth.

### 4. Turn the input gently while supporting the pivots. Stop

at a locked pallet; never force the wheel past it.

All gear spacers have flat annular ends. The intended endplay is 0.6 mm per gear. Neither the front plate nor a screw should clamp a rotating gear tightly between fixed faces.

06 / FASTENERS MUST REMAIN ACCESSIBLE

# Prepare and close the front frame

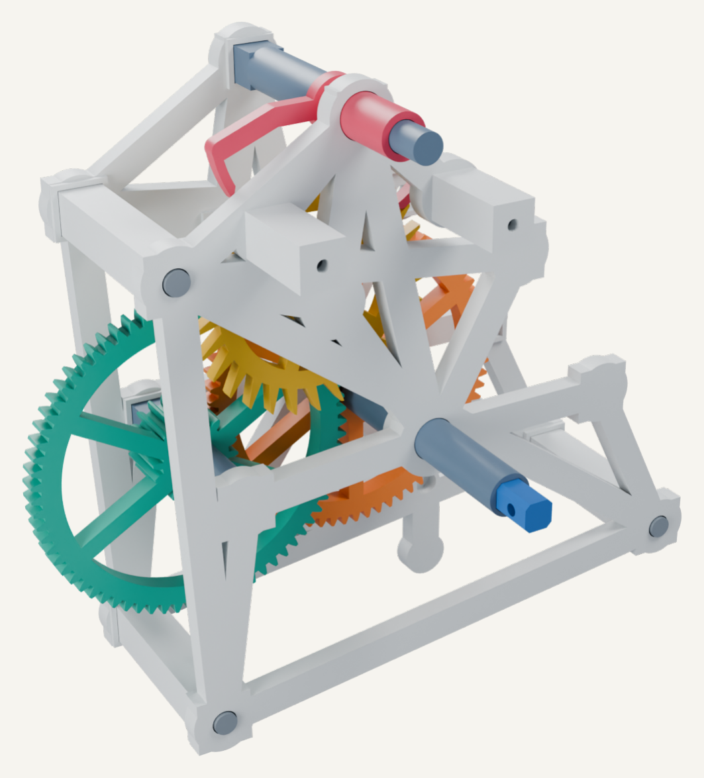
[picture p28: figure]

ROLLING CLOCK R3 | 248 mm drum | PLA / 0.4 mm nozzle / 0.2 mm layers | 11 / 17

### 1. Before fitting 06, bolt both 23 bridge posts to its outer

face with M3x10 screws inserted from the gear side. Their ends sit flat against the frame.

### 2. Temporarily use bridge 22 as an alignment template

over the two posts while tightening their rear screws. Its square lips prevent twisting. Lift the bridge off again.

### 3. Place frame 06 over the three frame posts, both short

pivot tips and the anchor sleeve. Its blind bearing seats and A collar face inward, toward the gears.

### 4. Add the three front M3x10 frame-post screws, seating

them gradually. Slide short front journal 37 (45.6 mm) onto the axle and into A.

If anything binds as the frame closes, reopen it and check the spacer order and blind seats. There should be 0.5 mm behind each seated pivot tip. Do not tighten a screw to overcome a misalignment.

07 / ADJUSTABLE BEAT, RIGID BRIDGE

# Clamp the pendulum and close the bridge

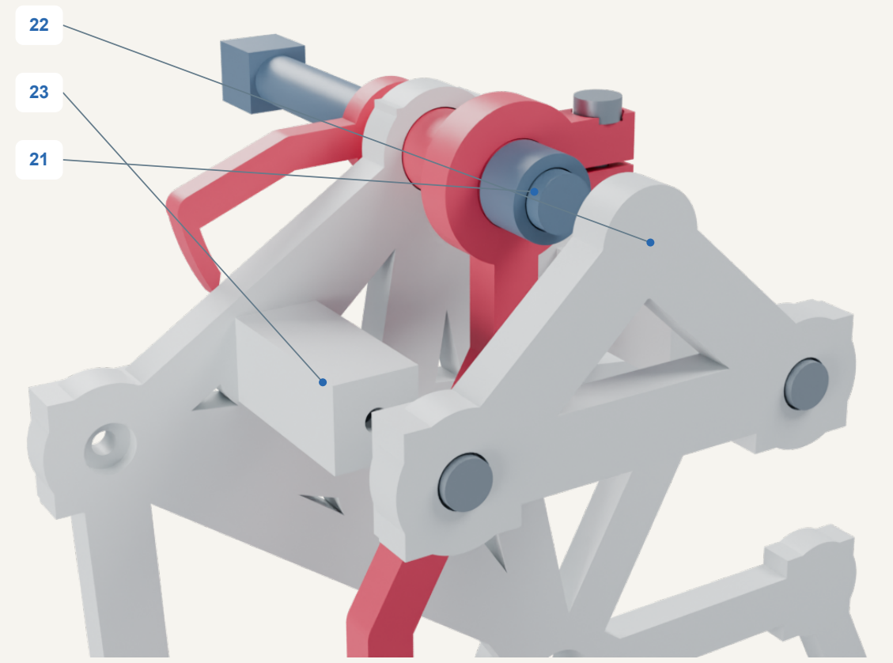
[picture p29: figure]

ROLLING CLOCK R3 | 248 mm drum | PLA / 0.4 mm nozzle / 0.2 mm layers | 12 / 17

### 1. Slide the head of 24 onto the anchor sleeve, ahead of

the frame. Its bent rod runs down around the main axle. Keep the front of the clamp approximately flush with the sleeve end.

### 2. Fit the clamp nut and M3x16 screw. The screw head

sits in the shallow circular recess. Tighten lightly so the angle can still be adjusted for the beat.

### 3. Place 21 (7.7 mm) on the exposed anchor pivot, ahead

of the sleeve and pendulum head.

### 4. Fit bridge 22 onto both posts and the pivot tip. Add its

two front M3x10 screws and snug them evenly. Confirm that the pendulum swings freely.

The bridge locates the fixed pivot; it must not squeeze the rotating sleeve. The square posts and flat faces establish the spacing. Check clearance at both clamp ears and the screw through a gentle swing.

08 / NO TOOTHPICK OR PRINTED SMALL PIN

# Fasten the bob with a real screw

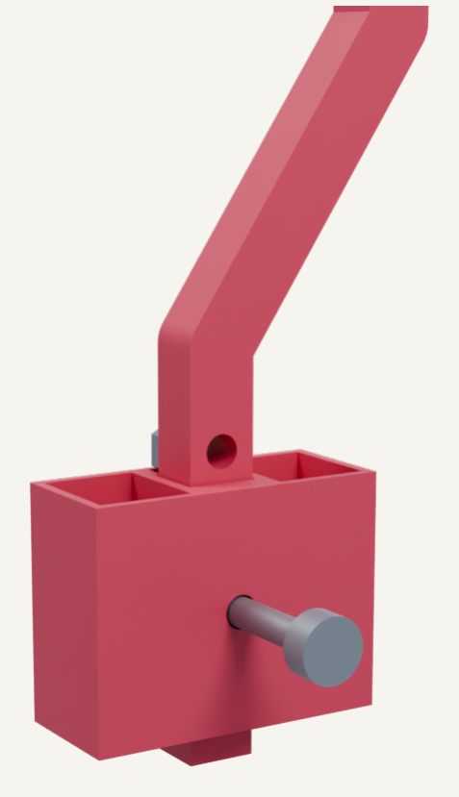
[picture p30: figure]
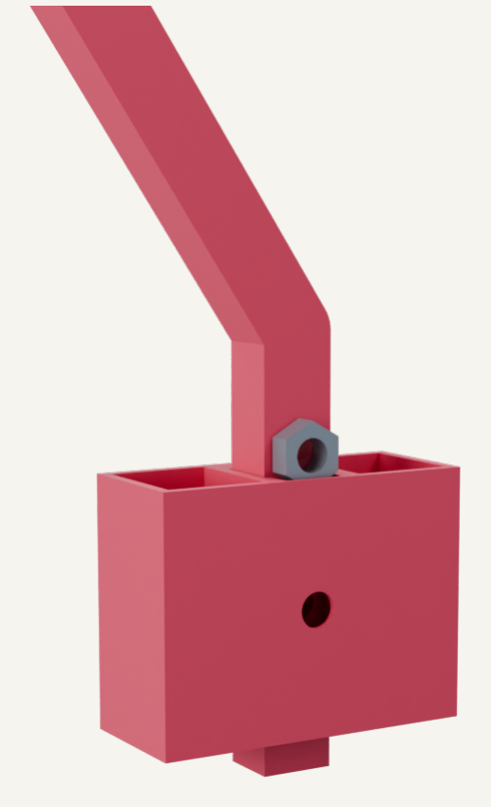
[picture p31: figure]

ROLLING CLOCK R3 | 248 mm drum | PLA / 0.4 mm nozzle / 0.2 mm layers | 13 / 17
Rear: insert the screw | Front: drop in the nut

### 1. Slide bob 25 over the straight lower part of the rod, with

both iron pockets facing upward. Start at the 150 mm hole: fourth from the pivot, second from the free end.

2. Drop a plain M3 nut into the 5.8 mm front channel, separate from the iron pockets. Slide it through the taper into the 5.6 mm seat, with its thread aligned to the rod hole.
3. Insert one M3x16 from the rear, toward the front nut. Tighten until the bob is held; do not crush its thin outside walls.
4. With the frame upright, add 15-20 g total iron, approximately evenly divided. Keep the main ballast bowl empty until the drum is fitted.

Nominal clearances: bob to frame 9.4 mm; screw head to frame 6.2 mm; screw tip to front spokes 15.6 mm. The 1 mm outer walls save space; the central web and thicker floor carry the attachment and ballast loads.

09 / FINISH THE CASE AROUND A FREE-RUNNING CORE

# Bench-test, then add bowl and drum

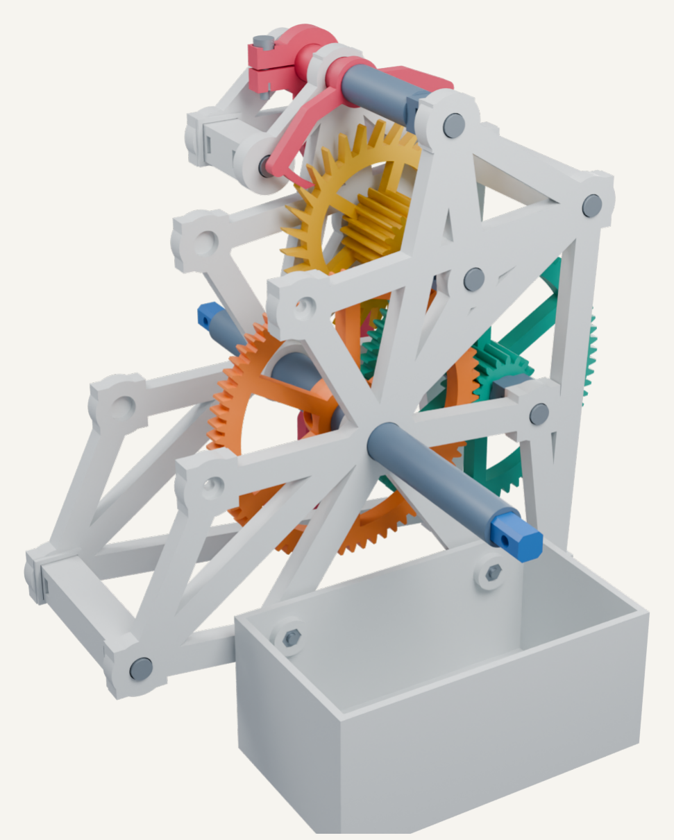
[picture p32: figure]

ROLLING CLOCK R3 | 248 mm drum | PLA / 0.4 mm nozzle / 0.2 mm layers | 14 / 17

### 1. Support the fixed frame upright, without squeezing its

bearings. Keep the loose axle sleeves seated with removable tape collars if necessary. Apply light counterclockwise input torque, seen from the pendulum side.

### 2. Adjust the pendulum clamp angle until each half-swing

releases one step and catches on the other pallet. Then snug the clamp. Remove temporary tape before final assembly.

### 3. Fit empty bowl 08 with two M3x10 screws from the gear

side and nuts inside the cup. Both lower pads must touch the rear frame.

### 4. Use six corrected 172 mm case posts. Preload their

nuts and both wheel-hub nuts. Fit the rear wheel and its M3x16 axle screw; bolt on the posts with six M3x16. Fit the front wheel, its axle screw and six post screws.

The case uses 12 post screws plus 2 axle screws. Snug opposite posts progressively. Wheel 01 now has a 1,536-segment rolling rim: try slicer Resolution 0.001 mm and Arc fitting on. Keep 0.2 mm layers. Check for rubbing through a full revolution before adding about 600 g ballast.

10 / THE 32X AND 64X OPTIONS

# Swap gearing without reprinting the frames

ROLLING CLOCK R3 | 248 mm drum | PLA / 0.4 mm nozzle / 0.2 mm layers | 15 / 17
32x: final pair 60:30 | 64x: final pair 72:18

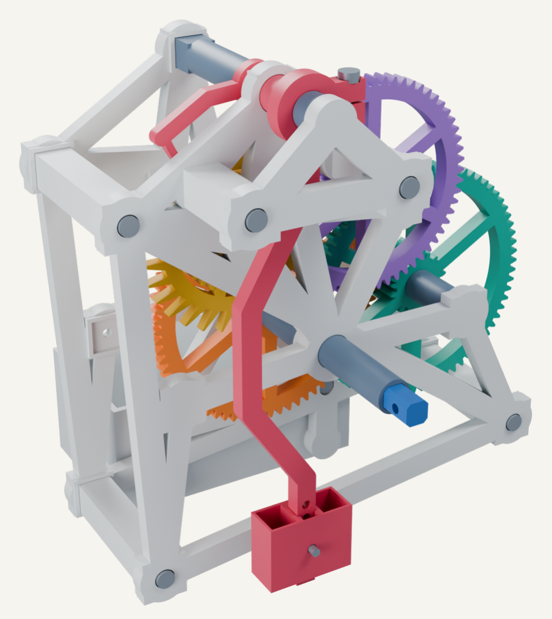
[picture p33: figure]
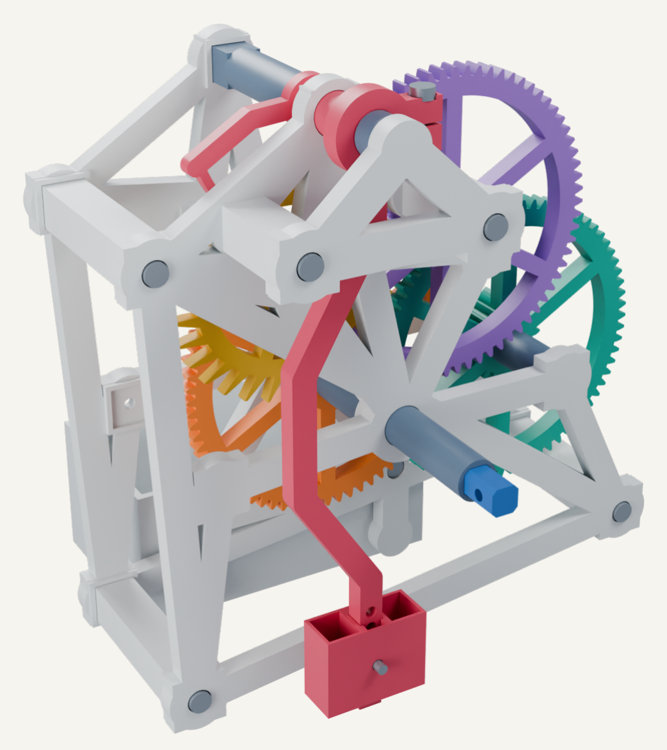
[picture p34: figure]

16x to a slower set: move B's pivot to Bslow. Add a third short pivot at D and its M3x10 screw/nut.

Use the selected folder's B, D and escape compounds, its spacers, and 18_anchor_reversed from slow-common/. Small pinions face rearward.

D stack: 28 (13.2 mm), D compound, 29 (11.7 mm). C's rear spacer 17 becomes 25.2 mm. B spacers and C's 4.7 mm front spacer stay the same lengths.

32x to 64x: swap only D and the escape compound. Both final pairs total 90 teeth, so shaft centres stay 56.25 mm apart.

Use each ratio's print list. The reversed wheel and anchor are a pair: the extra external mesh reverses the escape-wheel direction. Input still turns counterclockwise from the pendulum side. Recheck beat after a swap.

11 / START FROM THE SUCCESSFUL PHYSICAL TEST

# Run on the incline and calibrate

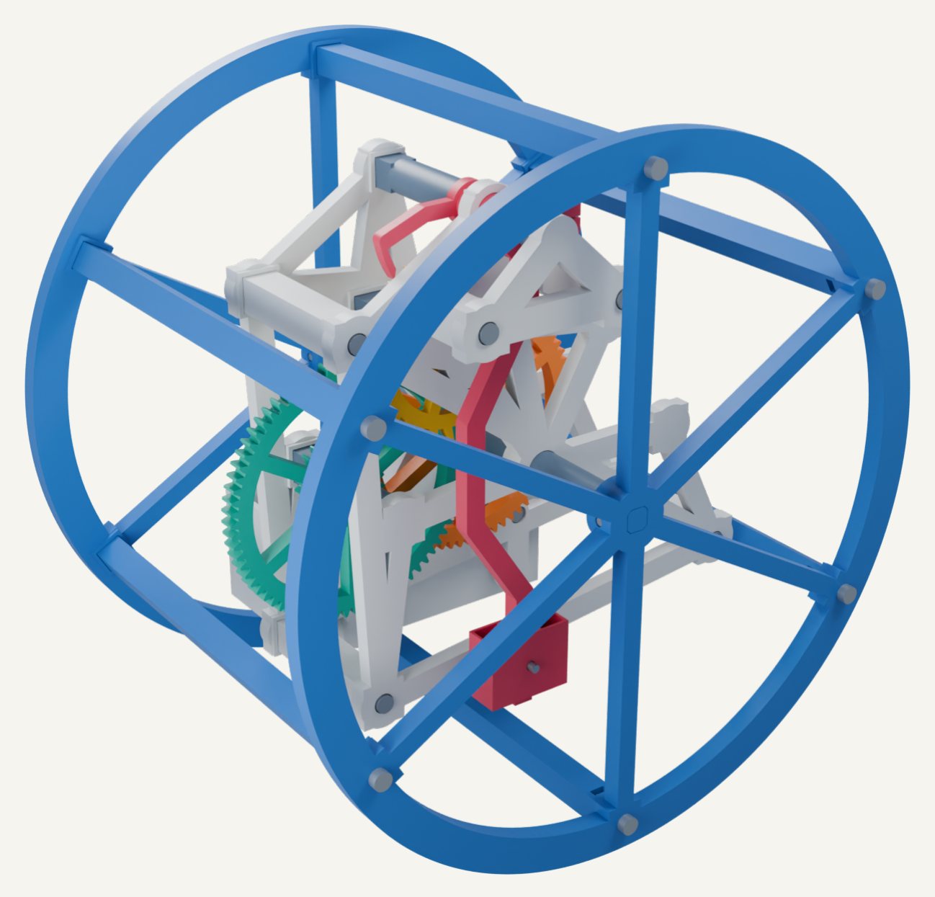
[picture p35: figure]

ROLLING CLOCK R3 | 248 mm drum | PLA / 0.4 mm nozzle / 0.2 mm layers | 16 / 17

Start with 16x, about 600 g in the main cup and 15-20 g in the bob. Use a straight board with a soft stop at the low end.

The earlier clock ran well with 4 cm rise over 80 cm, also at 3 cm. At 2 cm it required careful beat adjustment. Begin at 4 cm (about 2.9 degrees).

Time a marked distance. Calculated one-metre times are about 7:42 / 15:25 / 30:50 for 16x / 32x / 64x. R3's changed wheel and pendulum need a new real measurement.

Move the bob lower to slow its rate. Lift the drum to reset uphill. Try 32x only after 16x runs reliably, then try 64x: each slower option leaves less ideal torque at the escapement.

A little rocking can accompany the exchange of angular momentum between pendulum, carrier and drum. Snug joints remove looseness but do not guarantee zero rocking. Check for rubbing, skipped releases or stops; record these separately from timing error.

12 / ASSEMBLY REFERENCE

# Keep these lengths and screw counts handy

ROLLING CLOCK R3 | 248 mm drum | PLA / 0.4 mm nozzle / 0.2 mm layers | 17 / 17
Part | Position | 16x (mm) | 32x / 64x (mm)
15 | B rear | 1.2 | 1.2
16 | B front | 23.7 | 23.7
17 | C rear | 13.2 | 25.2
27 | C front | 4.7 | 4.7
28 / 29 | D rear / front | - | 13.2 / 11.7
20 | Anchor rear | 34.2 | 34.2
21 | Anchor front | 7.7 | 7.7
34 | Main front thrust | 26.4 | 26.4
35 | Main rear washer | 1.2 | 1.2
36 / 37 | Rear / front journal | 76 / 45.6 | 76 / 45.6
38 | Rear journal collar | 6 / round bore | 6 / round bore

One nut per screw

Case posts | 12 x M3x16
All axle retainers | 3 x M3x16
Pendulum clamp + bob | 2 x M3x16
Frame posts | 6 x M3x10
Bridge posts | 4 x M3x10
Bowl | 2 x M3x10
Gear / anchor feet | 3 x M3x10 (16x)
| 4 x M3x10 (32x / 64x)

R3 check results: closed connected print meshes; no unintended nominal intersections; spur and pallet checks; -15 to +15 degree pendulum sweep; full drum rotation. Nominal gap to the rotating posts is at least 2.35 mm.

The corrected R3 has been reported printing and rolling well. The refined rolling rim still needs a physical test; timing and every ratio remain unverified. Record the selected ratio, slope, ballast, timing, rubbing and skipped beats.

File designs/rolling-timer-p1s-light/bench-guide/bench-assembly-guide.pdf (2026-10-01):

ILLUSTRATED WORKSHOP GUIDE / LIGHTWEIGHT 16:1

# Assemble your printed bench mechanism

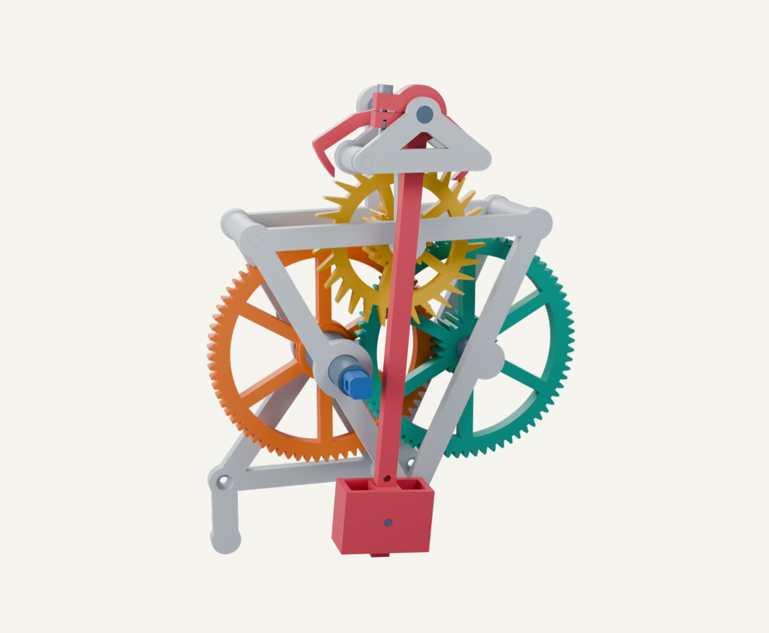
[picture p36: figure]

LIGHT 16:1 | Bench kit only | Numbers match your STL filenames | 1 / 13

YOUR TWO PRINT BATCHES

This guide uses exactly the 28 printed pieces from the 25 STL files in your two batches, plus one M3 x16 screw and one M3 nut.

The result is a supported bench mechanism: gear train, escapement and pendulum. You supply a gentle turning force by hand for this first test.

Front means the pendulum side, facing you in these pictures. Rear means the side with the heads of pivots 13 and 19.

Frames, posts and bridge

10 - orange input wheel

11 - green compound

12 - yellow escape wheel

18 / 24 / 25 - regulator

Printed pins and spacers

Before assembly: remove brims and obvious seam burrs. Try shafts in their bores by hand. Clean tight shaft surfaces gently; preserve gear teeth and pallet working faces. Keep the bob empty until the mechanism is upright.

STEP 01 / 10 ASSEMBLY STEPS

# Build the rear support

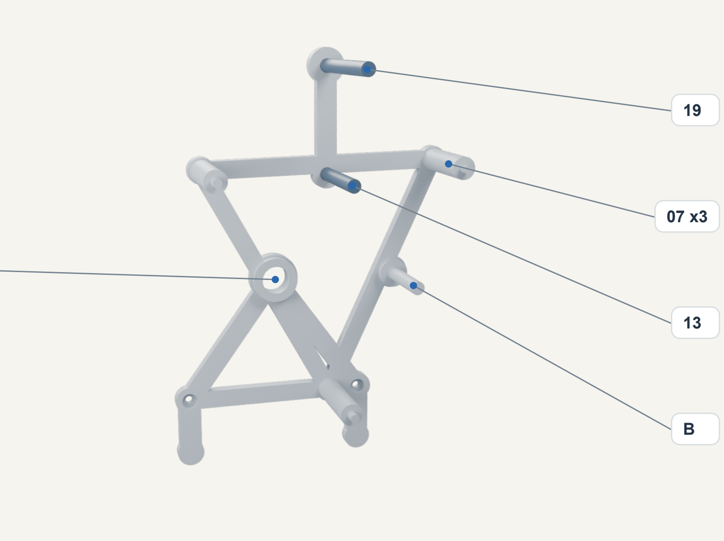
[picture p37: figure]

LIGHT 16:1 | Bench kit only | Numbers match your STL filenames | 2 / 13

05

Looking from the gear / pendulum side. B is already printed into frame 05.

PARTS TO ADD NOW
05_rear_carrier.stl
07_carrier_post.stl x3
13_gear_pivot.stl
19_anchor_pivot.stl

### 1. Hold rear frame 05 with its long built-in B pin pointing

toward you. The two small bowl screw holes are at the bottom; leave them empty.

### 2. Insert short pivot 13 through hole C and long pivot 19

through the top hole P, both from behind. Their flat heads stay behind frame 05.

### 3. Insert the three posts 07 into the three small corner

holes shown. Their thick shoulders sit against the gear-side face of 05.

FOUR WORKING AXES

A: large main bearing. B: built-in gear pin. C: escape-wheel pivot 13. P: top anchor pivot 19. The three separate corner holes take posts 07; none goes into a bowl screw hole.

Check: 13 is 49 mm overall; 19 is 67 mm. Use all three 47 mm carrier posts. Set front frame 06 aside.

STEP 02 / 10 ASSEMBLY STEPS

# Fit the square shaft and rear sleeve

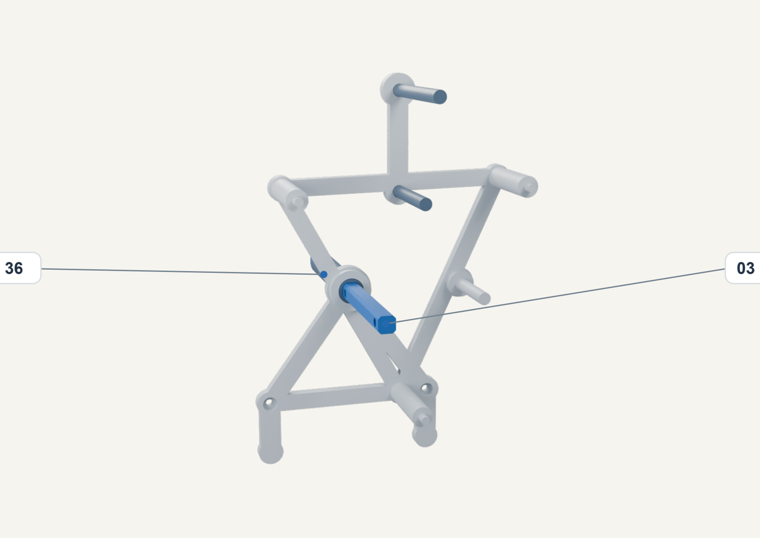
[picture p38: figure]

LIGHT 16:1 | Bench kit only | Numbers match your STL filenames | 3 / 13

The long round sleeve passes through the rear frame bearing.

PARTS TO ADD NOW
03_main_shaft.stl
36_rear_round_journal.stl

### 1. Identify the rear end of shaft 03: the middle

cross-hole is 81 mm from it, and 59 mm from the other end. Mark the rear end temporarily.

2. Slide long round sleeve 36 onto the square shaft. Feed the sleeved shaft through the large A hole of frame 05 from behind.

### 3. Set the front end of sleeve 36 flush with the front

face of the raised collar on 05. Hold it there while adding the next parts.

5 mm | 81 mm | 135 mm
SHAFT 03

140 mm overall

REAR END | | FRONT END

Check: the 66.6 mm sleeve provides the round bearing surface. The bare square shaft should not rub directly in the frame hole.

STEP 03 / 10 ASSEMBLY STEPS

# Add the orange input gear

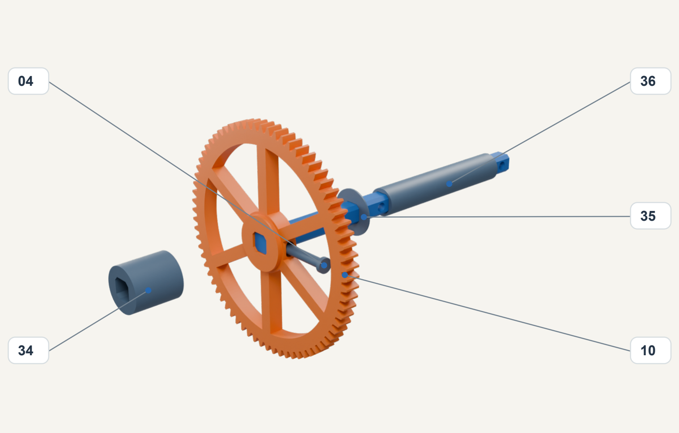
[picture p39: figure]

LIGHT 16:1 | Bench kit only | Numbers match your STL filenames | 4 / 13

Exploded detail: parts are spread apart along the shaft. Frame omitted here.

PARTS TO ADD NOW
35_main_rear_thrust_washer.stl 10_drive_72.stl
04_main_crosspin.stl
34_main_front_thrust_sleeve.stl

### 1. From the front, slide thin washer 35 onto the square

shaft, against the rear collar. This is the very thin 0.6 mm washer.

### 2. Slide drive gear 10 on with its taller central hub

facing forward. Align its cross-slot with the shaft hole 81 mm from the rear end.

### 3. Push crosspin 04 through the hub and shaft. Then

add the larger keyed sleeve 34 in front of the gear. Its length is 19.2 mm.

Check: gear 10 and shaft 03 turn together. The square socket transmits torque; a little tangential play in the retaining pin slot is intentional.

STEP 04 / 10 ASSEMBLY STEPS

# Fit the green compound gear

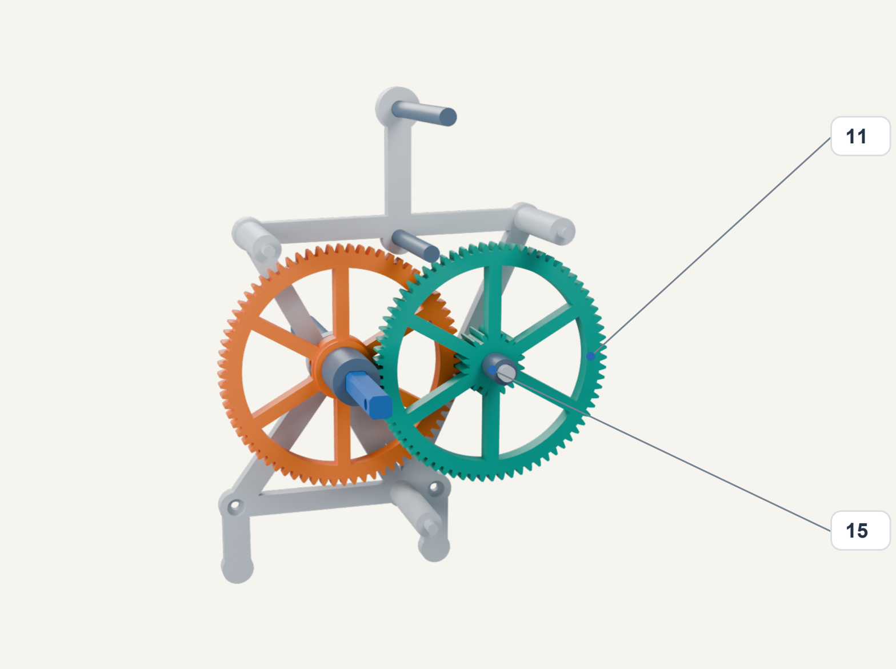
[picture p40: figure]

LIGHT 16:1 | Bench kit only | Numbers match your STL filenames | 5 / 13

The green wheel sits farther forward than the orange wheel.

PARTS TO ADD NOW
11_compound_18_72.stl
15_B_front_spacer.stl

### 1. Slide compound gear 11 onto the built-in B pivot of

rear frame 05.

### 2. Point its projecting small pinion toward the rear

frame. Its large 72-tooth wheel faces forward. The small pinion meshes with orange gear 10.

### 3. Slide spacer 15, length 11.4 mm, onto the B pivot in

front of gear 11.

Check: turn the gears gently while supporting the loose shafts. The large green wheel should clear the orange wheel rather than mesh with it.

STEP 05 / 10 ASSEMBLY STEPS

# Fit the yellow escape compound

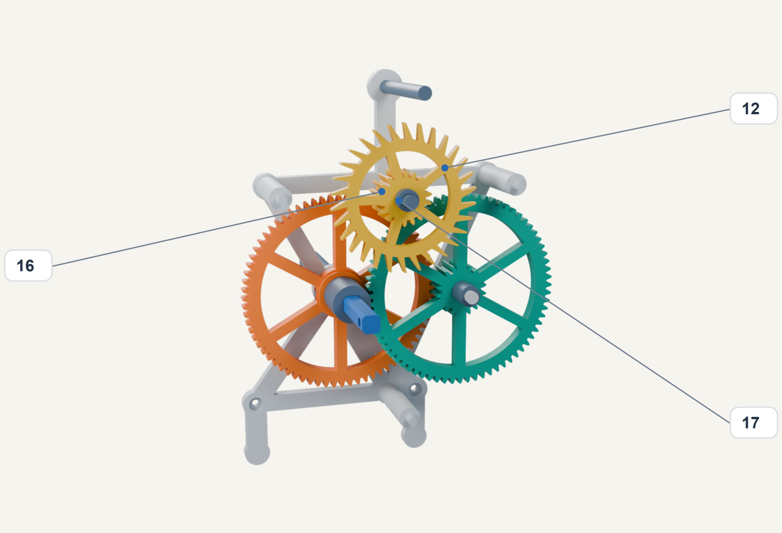
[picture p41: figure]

LIGHT 16:1 | Bench kit only | Numbers match your STL filenames | 6 / 13

The yellow small pinion engages the large green wheel.

PARTS TO ADD NOW
16_C_rear_spacer.stl
12_escape_compound.stl
17_C_front_spacer.stl

### 1. On pivot 13 at C, slide on rear spacer 16, length 14.4

mm. It rests against frame 05.

### 2. Add escape compound 12: its projecting small pinion

points rearward, and its large pointed escape wheel faces forward. Turn gently to engage the green wheel.

### 3. Add front spacer 17, length 4.4 mm. Before fitting the

anchor, check that both gear meshes turn without a hard spot.

Check: 16 is the long spacer behind the yellow gear; 17 is the short spacer in front. Do not press on the pointed tooth tips.

STEP 06 / 10 ASSEMBLY STEPS

# Place the pallet anchor

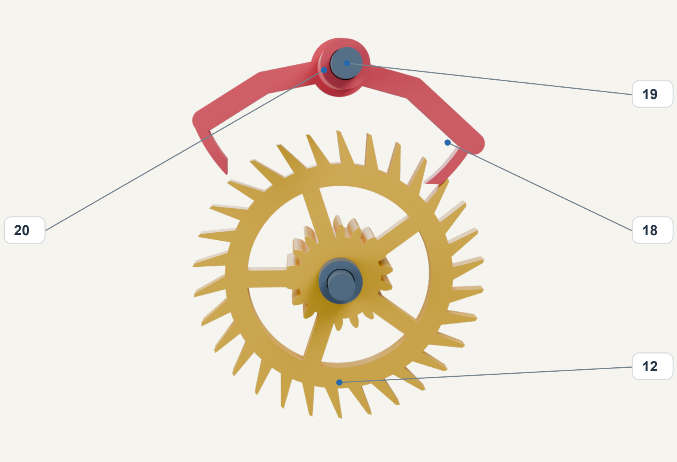
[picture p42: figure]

LIGHT 16:1 | Bench kit only | Numbers match your STL filenames | 7 / 13

Isolated escapement detail. Rear frame and other gears omitted for clarity.

PARTS TO ADD NOW
20_anchor_rear_spacer.stl
18_pallet_anchor.stl

### 1. On long top pivot 19, slide rear spacer 20 against

frame 05. This narrow spacer is 27.4 mm long.

### 2. Slide anchor 18 onto that pivot with its two pallet arms

pointing down toward the escape wheel. Its long round sleeve points forward.

3. Ease the pallets around the upper teeth of wheel 12, rotating the wheel a little if necessary. The pallet faces and escape wheel occupy the same front-to-back plane.

Check: the anchor pivots freely on 19. Preserve the little working faces and tooth tips; do not force the wheel past a locked pallet.

STEP 07 / 10 ASSEMBLY STEPS

# Close the two frames

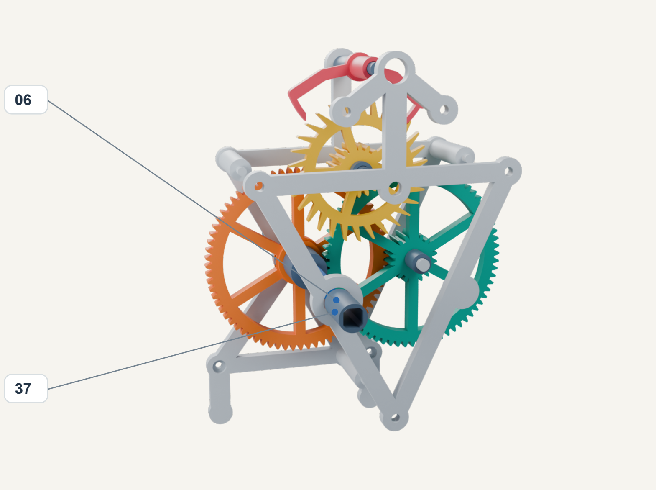
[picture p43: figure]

LIGHT 16:1 | Bench kit only | Numbers match your STL filenames | 8 / 13

Front frame and front sleeve are shown pulled forward before seating.

PARTS TO ADD NOW
06_front_carrier.stl
37_front_round_journal.stl

### 1. Orient front frame 06 with its raised main collar and

blind B bearing seat facing rearward, toward the gears.

### 2. Bring it onto all three posts 07. Guide B's built-in pin

into its blind seat, C pivot 13 into its hole, and the anchor's round sleeve through the large top opening.

### 3. Seat the frame gently. Slide short round sleeve 37

over the front of the square shaft and into the A bearing. Its rear end should be flush with the rear face of the front frame collar.

SEAT THE FRAME EVENLY

Posts locate the two frames. If a joint is loose during the bench test, a small removable tape wrap around the fixed joint can hold it; keep tape away from teeth and rotating surfaces. Do not glue the assembly yet.

Check: sleeves 36 and 37 turn with the shaft. Keep a little axial play in the gears. If closure makes anything stiff, reopen and check the spacer order.

STEP 08 / 10 ASSEMBLY STEPS

# Clamp the pendulum to the anchor

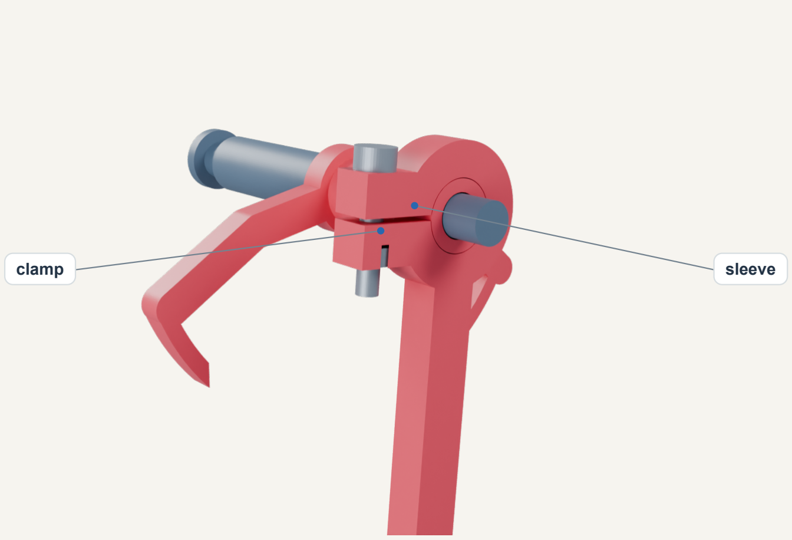
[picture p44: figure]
clamp; sleeve

LIGHT 16:1 | Bench kit only | Numbers match your STL filenames | 9 / 13

Close-up of the anchor sleeve and split pendulum clamp. Rod continues below.

PARTS TO ADD NOW
24_pendulum.stl
+ M3 x16 screw and plain M3 nut

### 1. Slide the split clamp of pendulum 24 over the

anchor's protruding round sleeve, ahead of front frame
06. The rod points downward.

### 2. Place one plain M3 nut in the hexagonal recess of

the clamp ear. Insert an M3 x16 screw through the opposite ear and start it into the nut.

### 3. Set the front face of the clamp approximately flush

with the end of the anchor sleeve. Tighten only enough to hold it provisionally; you will adjust its angle during the test.

LEAVE ACCESS FOR BEAT ADJUSTMENT

The angle between anchor and pendulum is adjustable. Tightening the clamp makes them move together; it must not pinch the stationary pivot. The illustrated screw and nut are unthreaded visual envelopes.

Check: the pendulum clamps to the rotating anchor sleeve, not to the stationary 6 mm pivot. Keep the clamp clear of frame 06.

STEP 09 / 10 ASSEMBLY STEPS

# Fit the open bob

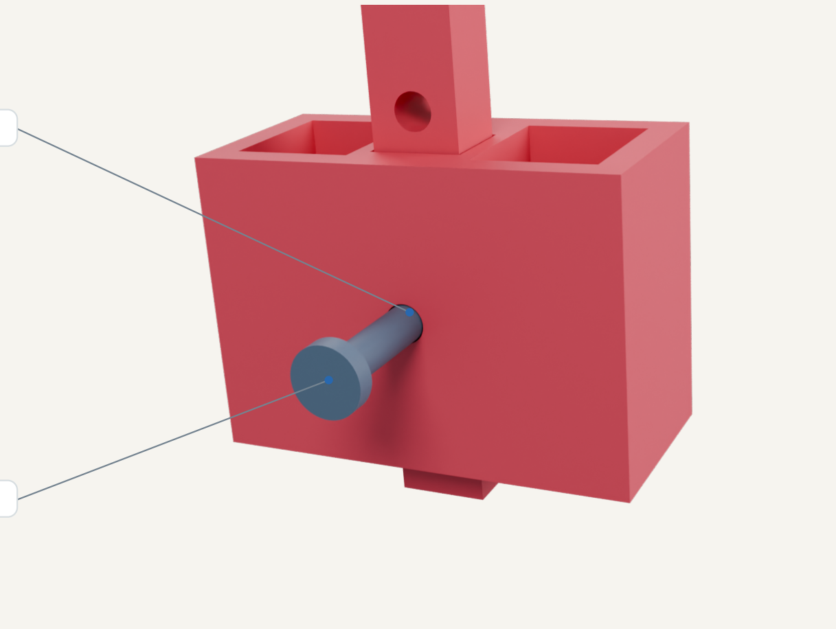
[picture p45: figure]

LIGHT 16:1 | Bench kit only | Numbers match your STL filenames | 10 / 13

26

25

Rear close-up of the bob; its pin is pulled back before insertion.

PARTS TO ADD NOW
25_open_pendulum_bob.stl
26_bob_pin.stl

### 1. Slide open bob 25 onto the bottom of the pendulum

rod with its two open pockets facing upward.

### 2. Align its hole with the 150 mm rod hole: the fourth

hole from the pivot, or the second hole from the free end.

### 3. Insert bob pin 26. Keep the bob empty until the

assembled frame is supported upright; then put 15-20 g total of iron into its two pockets.

135 | 140 | 145 | 150 | 155
PIVOT SIDE | FREE END

135, 140, 145, 150, 155 mm from pivot (diagram spacing enlarged)

Check: the bob pin passes through the rod and bob. Split the iron approximately evenly between the two pockets; this is the only ballast used in this bench test.

STEP 10 / 10 ASSEMBLY STEPS

# Support the front of the anchor pivot

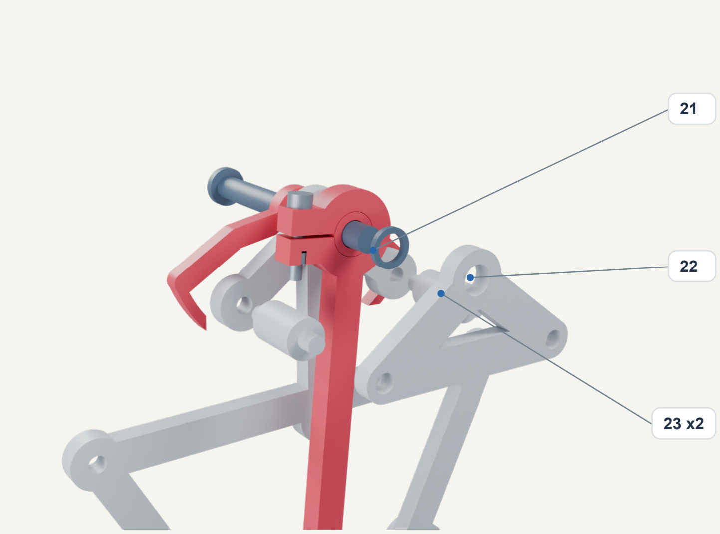
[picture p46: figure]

LIGHT 16:1 | Bench kit only | Numbers match your STL filenames | 11 / 13

Exploded close-up: washer, two bridge posts and bridge are pulled forward.

PARTS TO ADD NOW
21_anchor_front_washer.stl 23_bridge_post.stl x2
22_anchor_bridge.stl

### 1. Slide thin washer 21, thickness 1.4 mm, over the

exposed end of pivot 19, just in front of the pendulum clamp and anchor sleeve.

### 2. Fit both short bridge posts 23 into the two small holes

beside the top of front frame 06. Each post is 23 mm overall.

### 3. Fit bridge 22 onto the posts while guiding pivot 19 into

its central hole. Seat all three locations together without bending the pivot.

Check: the anchor pivot is now supported at both ends. The anchor and pendulum must turn freely with slight endplay; the bridge must not squeeze the clamp.

FIRST BENCH TEST / AFTER ALL TEN ASSEMBLY STEPS

# Support it, then try the escapement

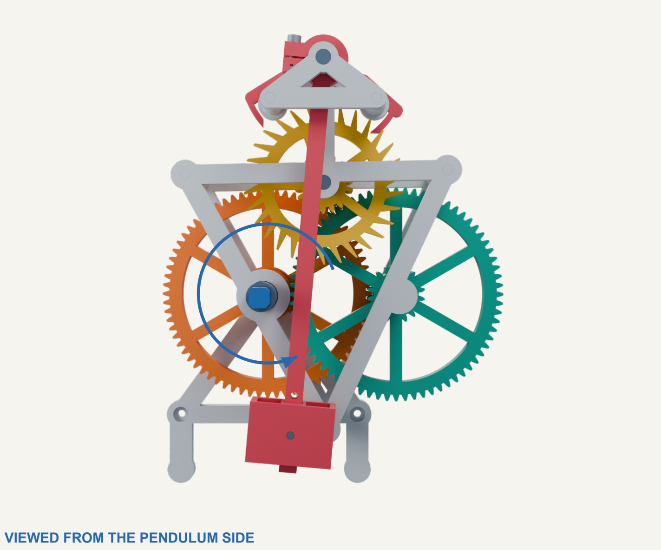
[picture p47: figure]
VIEWED FROM THE PENDULUM SIDE

LIGHT 16:1 | Bench kit only | Numbers match your STL filenames | 12 / 13

Orange and yellow turn counterclockwise; green turns clockwise. This corrects the earlier clockwise instruction for this front view.

### 1. Support the fixed frame upright with a padded clamp or

blocks, leaving the pendulum and both gear faces free. Avoid squeezing the bearing areas.

### 2. Without drum wheels, sleeves 36 and 37 can slide

outward. Keep them seated. Small removable tape collars on the exposed shaft just outside their outer ends can retain them; keep tape away from the frame bearings.

### 3. Add 15-20 g to the bob. Apply very light

counterclockwise torque to orange gear 10, viewed from the pendulum side. Move the pendulum gently, initially about 5 degrees each side.

### 4. Look for release, then a definite stop on the opposite

pallet on each half-swing. Adjust the pendulum clamp angle until release occurs at similar excursions either side of vertical; retighten lightly.

Pass: alternating catches without tooth skipping, scraping or a tight spot. If it binds or skips, stop and inspect the fit and pallet contact before adding force. This hand-driven check does not yet establish self-running performance.

QUICK REFERENCE / LENGTHS, LOCATIONS AND TROUBLESHOOTING

# Keep these small parts straight

LIGHT 16:1 | Bench kit only | Numbers match your STL filenames | 13 / 13

SPACERS AND SLEEVES

15 | 11.4 mm | In front of green gear 11
16 | 14.4 mm | Behind yellow gear 12
17 | 4.4 mm | In front of yellow gear 12
20 | 27.4 mm | Behind anchor 18
21 | 1.4 mm | Before the anchor bridge 22
34 | 19.2 mm | In front of orange gear 10
35 | 0.6 mm | Behind orange gear 10
36 | 66.6 mm | Long round sleeve; rear A bearing
37 | 23.6 mm | Short round sleeve; front A bearing

PINS, POSTS AND PIVOTS

07 | 3 copies | 47 mm overall; joins frames
13 | 1 copy | 49 mm overall; escape pivot
19 | 1 copy | 67 mm overall; anchor pivot
23 | 2 copies | 23 mm overall; bridge supports
04 / 26 | 1 each | Main gear retainer / bob retainer

IF SOMETHING DOES NOT FIT

Frame will not close
Check the three posts, the blind B seat and both pivot tips. Back off and align them together; do not use the front plate to bend a pin into place.

Gears stiff after closure
Check spacer lengths, shaft seams and remaining endplay. The front frame should not clamp a gear between two thrust faces.

Anchor does not swing freely
Check spacer 20, washer 21, bridge seating and clamp position. Nothing rotating should be trapped against a fixed frame or bridge.

Teeth pass without a firm catch
Confirm that the wheel and pallets are in the same plane, then adjust the beat. If catches remain marginal or skip, keep the tooth tips intact and record a close-up.

It stops when you release the gear
Expected for this bench setup: the rolling drum and its drive are not fitted. Keep very light hand torque while assessing the escapement.

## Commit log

2026-10-01 Publish first working rolling clock prototype
    [00_01_case_wheel.stl, 01_01_case_wheel.stl, 01_case_wheel.stl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]
2026-10-02 Add bolted R3 prototype with shared 16x, 32x and 64x frames
    [00_rear_case_wheel.stl, 01_case_wheel.stl, 01_front_case_wheel.stl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]
2026-10-02 Widen nut insertion channels while preserving snug seats
    [00_rear_case_wheel.stl, 01_case_wheel.stl, 01_front_case_wheel.stl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]
2026-10-02 Use coupon-tested 5.6 mm nut seats throughout R3
    [00_rear_case_wheel.stl, 01_case_wheel.stl, 01_front_case_wheel.stl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]
2026-10-07 Enclose pivot nuts in taller bases and widen the stack by 6 mm
    [01_front_case_wheel.stl, 02_case_post_1.stl, 02_square_case_post.stl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]
2026-10-08 Add actual-size R3 axle assembly and orientation drawing
2026-10-08 Illustrate spacer stacks and wheel orientation for all R3 ratios
2026-10-08 Add missing rear journal thrust collar after R3 widening
    [101_38_rear_journal_thrust_collar.stl, 107_38_rear_journal_thrust_collar.stl, 38_rear_journal_thrust_collar.stl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]
2026-10-08 Refine rolling rim mesh and record successful R3 test
    [00_rear_case_wheel.stl, 01_case_wheel.stl, 01_front_case_wheel.stl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]
2026-10-13 Add split wheel with analytic P1S tire toolpaths
2026-10-13 Add five-pass narrow tire with unchanged six-point mounting
2026-10-14 Restore wide tire with open zigzag ribs and solid screw seats
2026-10-14 Close zigzag tire with three concentric layers on each face
